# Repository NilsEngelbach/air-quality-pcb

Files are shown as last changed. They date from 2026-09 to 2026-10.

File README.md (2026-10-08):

# Air Quality Checker — PCB

Custom 2-layer KiCad boards for the [air-quality-checker](../air-quality-checker) firmware: a battery-powered
indoor air-quality monitor. A Bosch **BME688** measures the air, an **SG92R** micro servo points at the current IAQ
band, and readings can be uploaded over WiFi. A LiPo cell powers it and charges over USB-C. The device sleeps
~98 % of the time and wakes every 5 minutes.

The repo holds every board revision in its own folder. **The current board is [`v9/`](v9/) (rev I).**

---

## Current board — v9 (rev I)

| Block | Part | Notes |
|---|---|---|
| MCU | **ESP32-C3-WROOM-02-N4** | native USB Serial/JTAG (no USB-UART bridge), antenna in a board notch with no copper beside it |
| Sensor | **BME688** on-board, I²C 0x76 | on a slotted island at the board edge for thermal isolation |
| Indicator | **SG92R** servo header | from VSYS through a load switch (Q6): 0 µA in sleep, 4.5 V on USB / 3.0–4.2 V on battery |
| Charger | **MCP73831**, ~303 mA | charge status to the MCU (IO20) and a green side-view LED |
| Regulator | **AP2112K-3.3** | 600 mA LDO |
| Power path | DMG2305UX P-FETs + B5819W | USB priority, battery reverse-polarity protection, POWER switch drives a FET |
| Controls | POWER (SPDT) + **WiFi mode** (SP3T: OFF / SPARSE / CONTINUOUS) slide switches | right-angle, actuators through the enclosure wall |
| Indicators | blue STATUS + green CHG side-view LEDs | visible from the enclosure side |
| Expansion | **STEMMA QT / Qwiic** port | switched 3.3 V and bus isolation: 0 µA when off; e.g. for a real CO₂ sensor |
| Protection | 2 × USBLC6-2SC6 | USB data lines and the STEMMA QT port |
| Board | Ø 72 mm round, bottom flat for the controls, 2 layers, 1.6 mm FR4 | 0.3 mm minimum drill; assembled by PCBWay |

**State (2026-10-08):** layout done, ERC 0 / DRC 0 with schematic parity; schematic PDF and PCBWay BOM generated.
Gerbers, the ESP32-C3 firmware port and bench validation are still open.

| v9 document | For |
|---|---|
| [`v9/README.md`](v9/README.md) | changes vs v8, pin map, power architecture, firmware port, outputs, next steps |
| [`v9/user-documentation.md`](v9/user-documentation.md) | people using the device |
| [`v9/design_review.md`](v9/design_review.md) | findings F1–F34 with evidence and validation checklists |
| [`v9/layout_constraints.md`](v9/layout_constraints.md) | layout rules |
| [`v9/power_budget.md`](v9/power_budget.md) | sleep floor, wake budget, battery life per WiFi mode |

---

## Revisions

| Rev | Folder | Summary | Docs |
|---|---|---|---|
| A | [`v1/`](v1/) | 108 × 108 mm square. ESP-12F (ESP8266) + CP2102N, BME688 breakout over STEMMA QT, servo from VBAT | [README](v1/README.md) |
| B | [`v2/`](v2/) | Same circuit on a **Ø 72 mm round** board, mounting holes, wind logo | [README](v2/README.md) |
| C | [`v3/`](v3/) | **BME688 soldered on-board**, copper keep-out under the sensor | [README](v3/README.md) |
| D | [`v4/`](v4/) | GPIO2 status LED, battery sensing, USB ESD, battery reverse-polarity FET, spare-GPIO header, fiducials, **5 V servo boost** | [README](v4/README.md) |
| E | [`v5/`](v5/) | Production / assembly refresh (PCBWay BOM, replacement power switch); battery-life analysis | [power budget](v5/power_budget.md) |
| F | [`v6/`](v6/) | Gated servo boost, **3-position WiFi mode switch**, side-view status LED, MΩ battery divider | [README](v6/README.md), [user docs](v6/user-documentation.md), [power budget](v6/power_budget.md) |
| G | [`v7/`](v7/) | **ESP32-C3** (native USB, no CP2102N), FET-driven power switch, servo-rail load switch, long-actuator edge switches, STEMMA QT port, charge-status input, antenna notch and sensor island | [README](v7/README.md), [design review](v7/design_review.md) |
| H | [`v8/`](v8/) | **Servo boost removed** (servo from VSYS), Espressif WROOM-02 footprint so the board keeps the 0.3 mm minimum drill. Fabrication outputs were generated | [README](v8/README.md), [design review](v8/design_review.md) |
| I | [`v9/`](v9/) | Re-placed and re-routed v8: **GPIO remap**, LDO at the module, smaller sensor island, no copper beside the antenna, C24 on the STEMMA QT rail | [README](v9/README.md) and the documents above |

Each revision's README lists what changed against the one before. From v7 on, the design reviews number their
findings (F1, F2, …) and carry them forward, so a finding keeps its number across revisions.

---

## Repository layout

```
README.md                   this overview
build_pcbway_bom.py         KiCad BOM export → PCBWay BOM (python build_pcbway_bom.py v9)
a-sample-of-PCBWay-BOM.xlsx PCBWay's BOM template, the format the script produces
wind.svg                    wind logo used on the back silkscreen (v2+)
vN/
  air-quality-pcb-vN.kicad_pro / .kicad_sch / .kicad_pcb
  README.md, design_review.md, layout_constraints.md, power_budget.md, user-documentation.md   (as available)
  bom_kicad_raw.csv → bom_pcbway_vN.csv, schematic_vN.pdf                                       (as generated)
  Espressif.pretty/, SamacSys_Parts.pretty/, fp-lib-table, air-quality-pcb-vN.3dshapes/       (v7+: vendor footprints and STEP models)
```

Not in git (see `.gitignore`): `gerbers/`, `*.rpt` (ERC/DRC reports), KiCad backups and lock files. Regenerate
them with the `kicad-cli` commands in each revision's README (KiCad 10).

### PCBWay BOM

1. Export the schematic BOM ungrouped, with the fields `Reference,Value,Footprint,Manufacturer,MPN,Description`, to
   `vN/bom_kicad_raw.csv` (command in the revision README).
2. `python build_pcbway_bom.py vN` groups it into PCBWay's columns and writes `vN/bom_pcbway_vN.csv`.

---

## Firmware

The firmware lives in the sibling [`air-quality-checker`](../air-quality-checker) repo. It currently targets the
**ESP8266 boards (v1–v6)**. The ESP32-C3 boards (v7–v9) need a port: PlatformIO `espressif32`, ESP-IDF deep sleep,
the new pin map, BME688 at 0x76. The steps are in [`v7/README.md`](v7/README.md#firmware-port-air-quality-checker-repo),
with the servo rules from v8 and the **v9 pin map** in [`v9/README.md`](v9/README.md#firmware-port-air-quality-checker-repo).
The v7/v8 and v9 pin maps differ, so a v8 build must not be flashed onto a v9 board.

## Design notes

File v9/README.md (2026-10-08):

# Air Quality Checker — PCB v9 (rev I)

Ninth iteration, derived from the routed v8 board. Same circuit and outline. The board is **re-placed and
re-routed**, the **GPIO assignment is cleaned up** so that each signal leaves the module towards its destination,
the **sensor island is smaller** with a narrower neck, **no copper sits beside the antenna** any more, and the
STEMMA QT rail gets a **100 nF cap at the connector** (C24).

**State (2026-10-08): layout done; schematic PDF and BOMs generated, Gerbers not yet.** Schematic ERC **0 violations**.
Board DRC with schematic parity **0 violations, 0 unconnected** (also after a zone refill). Parity lists the
7 board-only footprints (H1–H4, FID1–3) and one new warning, D2's value (`CHG` on the board, `CHG-GREEN` in the
schematic; F34). The four silkscreen-at-edge items are excluded as in v8. Still to do: Gerbers, drill and
position files (see *Regenerate outputs*), the order, the firmware port and the bench validation.

| Document | For |
|---|---|
| [`user-documentation.md`](user-documentation.md) | people using the device: controls, WiFi modes, setup, LEDs, troubleshooting |
| [`design_review.md`](design_review.md) | findings F1–F26 (v7/v8) and **F27–F34 (new in v9)**, each with validation checklists |
| [`layout_constraints.md`](layout_constraints.md) | the layout rules the v9 board follows: antenna, servo rail, island, widths |
| [`power_budget.md`](power_budget.md) | sleep floor, wake budget, battery life by WiFi mode (estimates, bench checklist) |

For v7 → v8 (boost removed, Espressif footprint) see [`../v8/README.md`](../v8/README.md). For v6 → v7
(ESP32-C3, switches, STEMMA QT, …) see [`../v7/README.md`](../v7/README.md).

---

## What changed vs v8

| # | Change | Why (finding) |
|---|---|---|
| 1 | **GPIO remap:** SERVO_PWM IO5 → **IO0**, VBAT_SENSE IO0 → **IO3** (ADC1_CH3), MODE_A IO3 → **IO4**, MODE_B IO4 → **IO5** | the mode switch now uses the module's left pads (towards SW4), servo and VBAT sense its right pads (towards J3 and the divider); shorter routes, fewer vias. **Firmware pin map changes** (F27) |
| 2 | **C24 100 nF** on QT_3V3 at J5 / U8 | HF decoupling at the connector and the ESD clamp; 0 µA in sleep (F28) |
| 3 | **LDO U4 + C10–C12 moved** right below the module (53.1, 44.6) | short +3V3 to the module (+3V3 copper 156 → 104 mm) (F29) |
| 4 | **Power path and servo switch regrouped** at J3: D1, Q3, C20, Q6, Q7, R27, R28, C22, C19, C13 | SERVO_PWR 25 → 15.5 mm, F.Cu, no vias (F29) |
| 5 | **USB ESD U6 rotated**, pin pairs flipped (connector on 6/4, MCU on 1/3) | still flow-through; connector-side D± 19 → 7.5 mm (F29) |
| 6 | RESET/BOOT, EN RC, VBAT divider, charge-detect divider, strap pull-ups, STEMMA QT FETs re-placed | shorter, uncrossed routes (F29) |
| 7 | **Sensor island** ≈ 9.5 × 7 mm, **4 mm neck**, **4 mm slots** (v8: ≈ 11.5 × 13 mm, 7 mm neck, 1 mm slots); U5 further out, C14/C15 on the island | better thermal isolation of the BME688 (F13, F30) |
| 8 | **ANTENNA_KEEPOUT** widened to x 29.5–80 (both layers), pour keepouts x 27.5–83; new GND via fence at y = 27.5 | no copper on the board shoulders beside the antenna (F7, F31) |
| 9 | Re-routed and re-stitched: 641 vias (605 GND, stitching at 0.8 / 0.4 mm); a few accepted width exceptions | (F5, F32) |
| 10 | Title block / back silkscreen **rev I** | |

Everything else is unchanged from v8: schematic topology, parts (apart from C24), outline apart from the island,
U1 position and EPAD vias, connectors, switches, LEDs and mounting holes.

## Pin map (ESP32-C3-WROOM-02)

| GPIO | Net | Function |
|---|---|---|
| IO0 | **SERVO_PWM** | servo signal via R17 (v8: IO5) |
| IO1 | VBUS_SENSE | ADC1_CH1, 5 V → 1.59 V (USB present) |
| IO2 | QT_PWR_N | **STEMMA QT power, active low** (strap pin, R2 10 k pull-up → port off at reset and in sleep) |
| IO3 | **VBAT_SENSE** | ADC1_CH3, divider 1 M / 270 k (4.2 V → 0.89 V, use 2.5 dB attenuation) (v8: IO0) |
| IO4 | **MODE_A** | SW4 POS1 → LOW = WiFi **OFF** (v8: IO3) |
| IO5 | **MODE_B** | SW4 POS3 → LOW = **CONTINUOUS**; both HIGH = SPARSE (v8: IO4) |
| IO6 / IO7 | SDA / SCL | I²C: BME688 (**0x76**) + STEMMA QT port (through Q9/Q10) |
| IO8 | STATUS_LED_N | blue side LED D3, **active-low**; strap (10 k pull-up) |
| IO9 | BOOT | SW2, strap (10 k pull-up) |
| IO10 | SERVO_EN | HIGH = servo rail on (Q7 → Q6); R4 100 k pull-down keeps it off |
| IO18 / IO19 | USB D− / D+ | native USB Serial/JTAG |
| IO20 | CHG_DET | charger STAT via divider: LOW = charging (only valid with VBUS present), HIGH = done |
| IO21 | — | not connected (spare) |

## Power architecture

Unchanged from v8:

```
USB-C VBUS ─┬─► MCP73831 (303 mA) ─► VBAT_RAW ◄── Q4 (reverse-polarity) ◄── LiPo J4
            │        └─ STAT ─► D2 (green) / R31-R32 ─► IO20
            │                        │
            │                  Q5 (SW3 drives the gate)
            │                        ▼
            └─►|D1|──► VSYS ◄── Q3 (USB priority) ── VBAT ─► R20/R21 ─► IO3
                        │
                        ├─► AP2112K-3.3 ─► +3V3 (ESP32-C3, BME688, LED) ─► Q8 (IO2) ─► QT_3V3 (C23, C24) ─► J5
                        └─► Q6 (SERVO_EN via Q7) ─► SERVO_PWR (C19 22 µF + C13 100 µF) ─► J3
```

Servo supply: **≈ 4.5 V on USB**, **3.0–4.2 V on battery** (F25). Sleep floor estimate **≈ 66 µA**. Battery
life by WiFi mode is in [`power_budget.md`](power_budget.md) (estimates until measured).

## Firmware port (air-quality-checker repo)

The firmware in [`../../air-quality-checker`](../../air-quality-checker) still targets the ESP8266 (v6 board).
The port follows [`../v7/README.md`](../v7/README.md#firmware-port-air-quality-checker-repo) (PlatformIO
`espressif32` / `esp32-c3-devkitm-1`, BSEC2 1.10.2610, BME688 at 0x76, `esp_deep_sleep`, `RTC_DATA_ATTR`) and
the v8 servo rules, **with the v9 pin map**:

```cpp
#define SERVO_PWM_PIN   0   // v8: 5
#define VBUS_SENSE_PIN  1
#define QT_PWR_N_PIN    2   // LOW = STEMMA QT on
#define VBAT_SENSE_PIN  3   // v8: 0 — ADC1_CH3, ADC_2_5db, VBAT = mV / 0.2126
#define MODE_A_PIN      4   // v8: 3 — LOW = OFF
#define MODE_B_PIN      5   // v8: 4 — LOW = CONTINUOUS
#define SDA_PIN         6
#define SCL_PIN         7
#define LED_PIN         8   // active-low
#define BOOT_PIN        9
#define SERVO_EN_PIN   10
#define CHG_DET_PIN    20   // LOW = charging (only with VBUS present)
```

- **Do not flash a v7/v8 pin map onto v9:** it would drive PWM into the battery divider and read the mode switch
  as an ADC.
- **Servo (F25):** SERVO_EN HIGH ≥ 50 ms before a move, LOW after it and before sleep; no PWM while SERVO_EN is LOW;
  skip moves below VBAT ≈ 3.5 V; move with WiFi idle.
- **Mode switch (F33):** read IO4/IO5 with `INPUT_PULLUP` at each wake, then switch them back to `INPUT`. If you use
  GPIO wake (switch gesture, instant mode change), enable pull-up + wake **only on the pin whose contact is open**.
  A pull-up on a closed contact costs ~70 µA in sleep and doubles the floor.
- **Re-provisioning:** BOOT/RESET are inside the enclosure. Add a switch gesture on SW4 (e.g. OFF → CONTINUOUS →
  OFF → CONTINUOUS within 5 s) and keep RESET-then-BOOT as the service path; `user-documentation.md` marks both.
- **Low battery (F19):** VBAT < ~3.3 V → one LED blink, then indefinite deep sleep.

## Files

| File | Purpose |
|---|---|
| `air-quality-pcb-v9.kicad_pro/.kicad_sch/.kicad_pcb` | v9 project (ERC clean; board DRC clean with parity) |
| `Espressif.pretty/`, `SamacSys_Parts.pretty/`, `fp-lib-table` | vendor footprints: U1 (Espressif) and SW4 (OS103011MA7QP1, Mouser / SamacSys) |
| `air-quality-pcb-v9.3dshapes/` | STEP models for the vendor footprints and the side LEDs |
| `README.md` | this file |
| `user-documentation.md` | end-user guide |
| `design_review.md` | findings F1–F34 with evidence, sources and validation checklists |
| `layout_constraints.md` | layout rules |
| `power_budget.md` | power and battery-life estimates, bench checklist |
| `schematic_v9.pdf` | plotted schematic |
| `bom_kicad_raw.csv` → `bom_pcbway_v9.csv` | schematic BOM export → PCBWay BOM (38 lines, 72 placements; SW3, SW4, J3, J4 THT; C24 joins the CL21B104KBCNNNC line), built with `python build_pcbway_bom.py v9` |
| *to generate* `gerbers/` | Gerbers, drill, position file — see below (`*.rpt` and `gerbers/` are git-ignored) |

### Regenerate outputs (run in `v9/`)

```sh
kicad-cli sch erc -o erc_v9.rpt air-quality-pcb-v9.kicad_sch
kicad-cli pcb drc --schematic-parity --refill-zones -o drc_v9.rpt air-quality-pcb-v9.kicad_pcb
kicad-cli sch export pdf -o schematic_v9.pdf air-quality-pcb-v9.kicad_sch
kicad-cli pcb export gerbers -o gerbers/ --subtract-soldermask --check-zones \
  --layers "F.Cu,B.Cu,F.Paste,B.Paste,F.Silkscreen,B.Silkscreen,F.Mask,B.Mask,Edge.Cuts" air-quality-pcb-v9.kicad_pcb
kicad-cli pcb export drill -o gerbers/ --format excellon --generate-map --map-format pdf air-quality-pcb-v9.kicad_pcb
kicad-cli pcb export pos -o gerbers/air-quality-pcb-v9-pos.csv --format csv --units mm --side both air-quality-pcb-v9.kicad_pcb
kicad-cli sch export bom -o bom_kicad_raw.csv --fields "Reference,Value,Footprint,Manufacturer,MPN,Description" \
  --group-by "" air-quality-pcb-v9.kicad_sch
python ../build_pcbway_bom.py v9
```

Then zip the `*.g*` files and the `.drl` into `gerbers/air-quality-pcb-v9-gerbers.zip`. Expect 72 placements
(v8: 71, + C24) and a smallest hole of 0.30 mm.

## Next steps

1. Housekeeping (F34): resolve the D2 value warning, fix the title-block comment ("(v7)") and the two keepout
   names, then generate Gerbers, drill and position files (and re-export the PDF/BOM if the schematic changed).
2. Optional before ordering: 3D export → enclosure check (switch actuators ~3.2 mm, USB face, LEDs, sensor-island
   opening, ≥ 15 mm around the antenna) and a 1:1 paper print of the SW4 footprint against a real part (F11).
3. **Order at PCBWay:** Gerber zip, `bom_pcbway_v9.csv`, position file. Order note: SW3/SW4 are THT; parts overhang the
   bottom flat, and the sensor island hangs on a 4 mm neck — no breakaway tabs on those sides.
4. Firmware port with the v9 pin map (above), then the validation checklists in `design_review.md` (F27–F33 are new)
   and the bench measurements in `power_budget.md` §8.

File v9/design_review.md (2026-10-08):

# v9 Design Review — Findings and Validation Checklist

F1–F24 are the review of the v6 board (`v6/air-quality-pcb-v6.*`, state of 2026-09-30) and the
changes made for v7. F25–F26 cover v8 (boost removed, 0.3 mm minimum drill). v9 (rev I) is built from
the routed v8 board, so all of them carry over. **F27–F34** cover the v9 changes: a GPIO remap, C24 on the
STEMMA QT rail, a re-placed and re-routed board, a smaller sensor island, a copper-free zone beside the
antenna, and some open housekeeping. Where v9 changes an earlier finding, the section has a **v9** note
(the **v8** notes stay as history). Every finding lists the evidence, the source, what the design does about
it, and how to validate it. Tick the boxes as you validate. Coordinates are board mm (KiCad), centre (55, 55),
y grows downward.

**Status legend:** ✅ done in the schematic/netlist/board · 🟡 layout task, still open ·
⬜ open decision, not changed · 🔬 needs bench or firmware validation · ➖ obsolete

| # | Finding | Status |
|---|---|---|
| F1 | Power switch SW3 (0.3 A) carries the whole battery current | ✅ 🔬 |
| F2 | Servo rail is **not** off in deep sleep on v6 (boost passes VSYS through L1/D4) | ✅ 🔬 (v8: Q6 now feeds the servo directly) |
| F3 | v6 "DRC clean" is stale — the current v6 file has 8 violations | ✅ (v9: DRC 0 / 0, 2026-10-08) |
| F4 | GND pads of U3 (charger) and U7 (boost) have only one thermal spoke | ✅ (U7 gone in v8) |
| F5 | All tracks are 0.2 mm, no net classes | ✅ (v9 exceptions: F32) |
| F6 | Boost converter hot loop is ~20 mm long, with no input cap at U7 | ➖ boost removed |
| F7 | ESP-12F antenna sits mid-board with copper all around | ✅ 🔬 (v9: F31) |
| F8 | USB-UART bridge (CP2102N) is not needed with the ESP32-C3 | ✅ 🔬 |
| F9 | ESP32-C3 strapping / EN / USB requirements | ✅ 🔬 |
| F10 | v7 pin map (ADC1, deep-sleep wake pins) | ✅ 🔬 (v9 remap: F27) |
| F11 | Edge parts: overhang limits; switch actuators too short | ✅ 🟡 🔬 |
| F12 | MCP73831 runs in thermal regulation at 455 mA | ✅ (R14 3.3 k) 🟡 🔬 |
| F13 | BME688 needs thermal isolation from heat sources | ✅ 🔬 (v9: F30) |
| F14 | AP2112K quiescent current dominates the v7 sleep floor | ✅ decided: keep |
| F15 | WROOM-02 library footprint uses 0.2 mm EPAD via drills | ✅ v8: Espressif footprint (F26) |
| F16 | BSEC2 supports the ESP32-C3 | ✅ 🔬 |
| F17 | VBUS_SENSE moved from CP2102N to ESP ADC | ✅ 🔬 |
| F18 | Round outline vs. straight-fronted edge parts | ✅ (cuts done) 🔬 |
| F19 | No battery under-voltage cutoff on board | ✅ decided: protected cells; firmware cutoff 🔬 |
| F20 | v6 power budget understated the sleep current | ✅ 🔬 (v9: [`power_budget.md`](power_budget.md)) |
| F21 | STEMMA QT port for optional sensors | ✅ 🟡 🔬 |
| F22 | Charge status to the MCU | ✅ 🔬 |
| F23 | CHG LED D2 invisible inside the enclosure | ✅ 🟡 |
| F24 | BME688 occupies the common add-on address 0x77 | ✅ 🔬 |
| F25 | **v8:** boost removed — servo runs from VSYS (4.5 V USB / 3.0–4.2 V battery) | ✅ 🟡 🔬 |
| F26 | **v8:** board must keep the 0.3 mm minimum drill — EPAD vias for the WROOM-02 | ✅ 🔬 |
| F27 | **v9:** GPIO remap — SERVO_PWM → IO0, VBAT_SENSE → IO3, MODE_A → IO4, MODE_B → IO5 | ✅ 🔬 (firmware) |
| F28 | **v9:** C24 100 nF HF decoupling on QT_3V3 at J5 / U8 | ✅ 🔬 |
| F29 | **v9:** re-placement — LDO at the module, power path regrouped at the servo switch, USB ESD flipped | ✅ 🔬 |
| F30 | **v9:** smaller sensor island (≈ 9.5 × 7 mm, 4 mm neck, 4 mm slots), U5 decoupling on the island | ✅ 🔬 |
| F31 | **v9:** no copper beside the antenna — keepouts widened to the board shoulders, new via fence | ✅ 🔬 |
| F32 | **v9:** routing — track-width exceptions, 0.8 / 0.4 mm stitching, USB pair length | ✅ (accepted) 🔬 |
| F33 | **v9:** mode-switch pull-ups must not stay on in deep sleep (~70 µA per closed contact) | ⬜ firmware 🔬 |
| F34 | **v9:** housekeeping — D2 value parity warning, title-block comment, keepout names, Gerbers not generated yet | 🟡 |

---

## F1 — Power switch SW3 is overloaded

- **Evidence (v6):** SW3 = C&K PCM12SMTBR, rated **0.3 A @ 6 V** (v6 BOM). It switched
  VBAT_RAW → VBAT, i.e. *all* battery current: servo move ≈ 400 mA battery-side
  (`v6/power_budget.md` §8), ESP32-C3 WiFi TX peaks up to 350 mA (module datasheet,
  Table 6-4). Combined peaks ≈ 0.75 A > 2× the switch rating.
- **v7 action:** SW3 only drives the gate of a new P-FET **Q5 (DMG2305UX, 20 V / 4.2 A)**.
  Q5 source = VBAT_RAW, drain = VBAT. SW3 common (pin 2) → gate; POS1 (1–2) → GND = **ON**;
  POS2 (2–3) → source = **OFF**. **R26 10 MΩ** gate–source holds Q5 off during the
  break-before-make gap (costs 0.42 µA while ON). Q5's body diode points VBAT → VBAT_RAW,
  so with SW3 OFF the battery cannot feed the system; USB still powers it via D1 (same as v6).
  The switch now carries µA, so a 0.1 A switch (F11) is fine.
- **Validate:**
  - [ ] SW3 ON: device runs from battery; Q5 V_DS < 50 mV at 0.5 A load.
  - [ ] SW3 OFF, no USB: VBAT ≈ 0 V, battery current < 1 µA (only charger leakage).
  - [ ] SW3 OFF + USB: device runs from USB, battery charges, Q5 stays off.
  - [ ] Slide SW3 slowly between positions: no brownout or latch-up.

## F2 — The servo rail is never really off on v6

- **Evidence (v6 schematic):** MT3608 is a non-synchronous boost: VSYS → L1 → SW node → D4
  → SERVO_5V. Pulling EN low (v6 change #1) stops switching but **does not disconnect**:
  SERVO_5V sits at ≈ VSYS − V_F(D4) in deep sleep. The servo stays powered, and the
  feedback divider R22 + R23 (93 kΩ) draws ≈ 37 µA. The v6 budget line "MT3608 + SG92R
  idle < 1 µA (EN low = shutdown)" only counts the MT3608's own shutdown current.
- **v7 action:** load switch in front of the boost input:
  **Q6 DMG2305UX** (VSYS → BOOST_IN, which feeds U7 IN, L1 and C18), gate pulled up by **R27 100 k**;
  **Q7 2N7002** pulls the gate down through **R28 47.5 k** when BOOST_EN (IO10) is high
  (V_GS ≈ −2.5 V at 3.7 V). **C22 100 nF** gate-drain gives a slow turn-on:
  ≈ 47 µA / 100 nF ≈ 0.5 V/ms, so BOOST_IN ramps in ~8 ms and the inrush into the
  ~166 µF downstream (C18 + C19 + C21 + C13) is ~80 mA instead of amps.
  Off state: R4 keeps BOOST_EN low → Q7 off → Q6 off → zero rail current.
- **v8:** the boost is gone and Q6's drain is the servo rail itself (`SERVO_PWR`; the control net is
  now `SERVO_EN`, gate/pull-down nets `SERVO_GATE`/`SERVO_PD`). Downstream capacitance is C19 + C13 = 122 µF,
  so the soft-start inrush is ≈ 60 mA. The off state is unchanged: zero rail current. See F25.
- **Validate:**
  - [ ] **On a v6 board first:** measure the J3 pin-2 current and voltage in deep sleep (expect ≈ VSYS − 0.3 V and
        ≥ 37 µA plus the servo idle current). This confirms the finding and quantifies the v6 loss.
  - [ ] v9 deep sleep: SERVO_PWR = 0 V.
  - [ ] Scope VSYS, +3V3 and SERVO_PWR on a SERVO_EN rising edge: SERVO_PWR ramps in ~5–10 ms;
        +3V3 dips < 100 mV (no ESP brownout).
  - [ ] Servo moves normally with SERVO_EN high ≥ 50 ms before the move.

## F3 — v6 DRC report is stale

- **Evidence:** `v6/drc_v6_check.rpt` is dated 10:07; the board was saved at 14:17.
  A fresh `kicad-cli pcb drc` on v6 gives **8 violations**: 4× copper-to-edge
  (SW3 0.47 / 0.47 mm, SW4 0.44 / 0.42 mm vs the 0.5 mm rule), 2× silkscreen clipped (SW3),
  2× starved thermal (F4).
- **v7 action:** SW3/SW4 replaced (F11); thermal fix (F4).
- **v8:** `drc_v8.rpt` (with schematic parity): 0 errors, 0 unconnected; 2 warnings (U1 silkscreen
  clipped at the antenna notch, F26) and the 7 board-only footprints.
- **v9:** ERC 0 violations. DRC with schematic parity (2026-10-08, also after a zone refill): **0 violations,
  0 unconnected**. Parity reports the 7 board-only footprints and one new warning, D2's value (F34). The four
  `silk_edge_clearance` items at the notch and the bottom flat are excluded in the project file.
- **Validate:**
  - [ ] After placement and routing: `run_drc` = 0 violations, and the report timestamp is newer than the board file.

## F4 — Starved thermals on the charger and boost GND pads

- **Evidence:** v6 DRC `starved_thermal` on U7 pin 2 and U3 pin 2 (1 spoke instead of 2).
  These are the two parts whose GND pin is their main heat path.
- **v7 action:** pad zone connection set to **solid** for the GND pads of U1 (pin 9 + EPAD),
  U3, U4 and U7.
- **v8:** U7 is removed. The solid connection is set again on U1 pin 9 and on all nine EPAD pads of the new
  footprint (F26).
- **Validate:**
  - [ ] After the zone refill, no `starved_thermal` on these pads. (The 5 current hits on J1/U6 are fine-pitch USB
        GND pads that lost their feeding traces; they clear when routed.)

## F5 — All traces are 0.2 mm, and there are no net classes

- **Evidence (v6 board dump):** every segment is 0.2 mm, including VBUS (138 mm of track),
  VBAT (59 mm), VSYS (47 mm), BOOST_SW (20 mm), SERVO_5V (47 mm).
  0.2 mm × 35 µm Cu ≈ 2.5 mΩ/mm → 0.25 V per 10 cm at 1 A. Heating is not the issue
  (IPC-2221 ≈ 0.7 A for +10 °C); voltage drop and inductance are (brownout during
  servo + WiFi peaks at low battery).
- **Action (v7, updated for v8, unchanged in v9):** net classes in `air-quality-pcb-v9.kicad_pro` (Freerouting/`export_dsn` reads them):

  | Class | Width | Via | Nets |
  |---|---|---|---|
  | Power | 0.8 mm | 0.8/0.4 | BAT_IN, VBAT_RAW, VBAT, VSYS, SERVO_PWR |
  | Supply | 0.5 mm | 0.8/0.4 | VBUS, +3V3, GND |
  | USB | 0.25 mm (diff pair 0.25/0.2) | 0.6/0.3 | USB_D±, USB_D*_CON, USB_D*_MCU |

  v8: SERVO_PWR (was BOOST_IN + SERVO_5V) is in Power; BOOST_SW is gone.
- **v9:** the re-route has some short segments below the class width (KiCad DRC does not enforce class widths).
  They are listed and accepted in F32.
- **Validate:**
  - [ ] `export_dsn` contains the classes; routed power tracks are ≥ the class widths.
  - [ ] At a 1 A battery load: VBAT_RAW → VSYS drop < 100 mV (incl. Q4, Q5, Q3).

## F6 — Boost converter hot loop (obsolete in v8)

> **v8:** the boost converter is removed (F25), so this finding and its checks no longer apply. Kept for the record.

- **Evidence (v6 placement):** U7–L1 14.5 mm, U7–D4 13.6 mm, D4–C19 20.5 mm, D4–C13 25.4 mm;
  BOOST_SW was a 20 mm track at 0.2 mm. **No cap at U7 IN**: the nearest VSYS cap was C18,
  11.7 mm away (C8 next to U7 is on VBUS). R22 sat ~8 mm from FB.
  MT3608 datasheet p.6: 22 µF in/out close to the IC on a strong GND plane, main traces
  short and wide, SW node small, FB divider close.
- **v7 action:** C18 → **22 µF at U7 IN** (BOOST_IN); **C21 22 µF** second output cap
  (0805 X5R 16 V loses capacitance at 5 V); D4 SS34 (SMA, 5.2 × 2.6 mm) →
  **PMEG4030ER** (SOD-123W, 2.6 × 1.7 mm, 40 V / 3 A). C20 22 µF is VSYS bulk ahead of Q6.
  Layout recipe in `layout_constraints.md` §3.
- **Validate:**
  - [ ] Layout: loop U7.1 → D4 → C19/C21 → GND → U7.2 fits within ~8 × 8 mm on F.Cu.
  - [ ] Scope the SW node: clean edges, ringing < 2 V overshoot. SERVO_5V ripple < 100 mV p-p during a servo move.

## F7 — Antenna placement

- **Evidence (v6):** ESP-12F centred at (53, 52) on the Ø72 mm board. Its antenna region
  (y ≈ 40–47.5 mm) is ~21 mm from the nearest edge, with GND pour on both layers around
  the keepout. No tracks cross the antenna.
- **Source:** Espressif ESP32-C3 HW design guidelines: antenna **outside** the base board,
  or the feed point as close to the edge as possible; cut the board on both sides of and under the antenna;
  **≥ 15 mm clearance in all directions** inside the housing; dense GND vias near the antenna.
- **v7 action:** module → ESP32-C3-WROOM-02 (18 × 20 mm). Its footprint carries an all-layer
  keepout of 28 × 11 mm (5 mm beyond each side and the antenna end). The old mid-board
  keepout zone was removed. Placement in `layout_constraints.md` §2.
- **v8:** Espressif's footprint only carries an 18 × 6 mm keepout (the antenna area of the module itself).
  The 28 × 11 mm area of the stock footprint is kept as the board rule area **ANTENNA_KEEPOUT**
  (x 41–69, y 15.4–26.4, F.Cu + B.Cu: no tracks, vias, pads or pour) — see F26.
- **v9:** ANTENNA_KEEPOUT is widened to the board shoulders beside the notch (x 29.5–80), the pours are kept off a
  slightly larger band, and the via fence is rebuilt — see F31.
- **Validate:**
  - [ ] Layout: antenna end at (or past) the board edge; no copper, tracks or vias in the keepout.
  - [ ] Bench: RSSI of v6 vs v7 at the same spot / AP distance (expect v7 ≥ v6).
  - [ ] In the enclosure: battery, servo and screws ≥ 15 mm from the antenna.

## F8 — UART bridge removed

- **Evidence:** the ESP32-C3 has an integrated USB Serial/JTAG controller (GPIO18/19)
  that supports flashing, console and automatic download mode (Espressif schematic
  checklist).
- **v7 action:** removed U2 (CP2102N), C4, C5, Q1, Q2, R6, R7 and JP1 (the C3 wakes from its
  internal RTC timer, so no GPIO16→RST link is needed). Added **R24/R25 22 Ω** series
  resistors (place at U1). C6 (4.7 µF) stays as VBUS bulk. **No test pads** (decision: boards
  are ordered assembled); recovery is BOOT + RESET over USB with the enclosure open. IO20 is
  re-used for CHG_DET (F22); IO21 is unconnected.
- **Validate:**
  - [ ] Board enumerates as USB JTAG/serial debug unit (VID 303A); `esptool` flashes without pressing buttons.
  - [ ] Manual recovery: hold BOOT, tap RESET → download mode.
  - [ ] Known behaviour: the USB port disappears during deep sleep — firmware should not rely on the console.

## F9 — ESP32-C3 strapping, EN and USB

- **Source:** module datasheet Table 4-3: SPI boot = GPIO9 high; download = GPIO9 low +
  GPIO8 high; GPIO2 "recommended to pull up due to glitches". EN RC = 10 k + 1 µF.
  Supply ≥ 500 mA, 10 µF + 0.1 µF at the module.
- **v7 action:** R2 → IO2 10 k pull-up; R5 → IO8 10 k pull-up (the status LED also sits on IO8,
  active-low, so LED off = strap high); R3 → IO9 10 k pull-up + SW2 BOOT; R1/C1 = 10 k /
  **1 µF** (was 100 nF); SW1 RESET now on EN; C2/C3 = 10 µF + 100 nF. AP2112K = 600 mA.
- **Validate:**
  - [ ] Boots into the application in every SW4 position, with and without USB.
  - [ ] LED stays dark during reset (IO8 high).
  - [ ] BOOT/RESET are **internal only** (decision). WiFi re-provisioning therefore needs a firmware gesture on
        SW4 (see README, firmware port). BOOT + RESET remain the service path: BOOT held while RESET is
        released = download mode.

## F10 — v7 pin map

> **v9:** IO0, IO3, IO4 and IO5 are reassigned — see **F27**. The table below is the **v9** map; the
> reasoning per pin is unchanged.

| GPIO | Net | Why |
|---|---|---|
| IO0 | SERVO_PWM (v7/v8: VBAT_SENSE) | via R17 100 Ω; any GPIO can drive LEDC PWM |
| IO1 | VBUS_SENSE | ADC1_CH1 (F17) |
| IO2 | QT_PWR_N | strap (R2 pull-up) → STEMMA QT power, active low (F21) |
| IO3 | VBAT_SENSE (v7/v8: MODE_A) | ADC1_CH3 (ADC1 is calibrated; ADC2 is not usable reliably) |
| IO4 / IO5 | MODE_A / MODE_B (SW4) (v7/v8: IO3 / IO4) | internal pull-ups while awake; GPIO0–5 can wake from deep sleep (mind F33) |
| IO6 / IO7 | SDA / SCL | R18/R19 10 k pull-ups; BME688 0x76 + QT port |
| IO8 | STATUS_LED_N | strap, pull-up R5, LED active-low |
| IO9 | BOOT | strap, R3 + SW2 |
| IO10 | SERVO_EN (v7: BOOST_EN) | R4 100 k pull-down → Q7/Q6 servo-rail switch |
| IO18 / IO19 | USB D− / D+ | via R25 / R24 |
| IO20 | CHG_DET | charger status via R31/R32 (F22) |
| IO21 | — | unconnected, spare |

- **Validate:**
  - [ ] Firmware port (see README) reads all inputs and drives all outputs as listed (v9 map).
  - [ ] VBAT_SENSE (IO3) reads 4.20 V ± 30 mV at full charge (ADC1, 2.5 dB attenuation, divider 0.2126).

## F11 — Edge parts: overhang limits and actuator length

- **Rule:** what limits overhang is the **frontmost copper or hole**, not the body.
  PCBWay: copper ≥ 0.3 mm, holes ≥ 0.5 mm from the routed edge; project rule
  `min_copper_edge_clearance` = 0.5 mm.
- **Evidence (v6):** SW3/SW4 (PCM12/PCM13): front SMD tabs sit 0.23 mm in front of the body,
  so the actuator tips reached only **0.71 / 0.55 mm** past the edge — they cannot reach through
  a 1.5–2 mm enclosure wall. D3 lens 0.2 mm past the edge; J1 front 0.7 mm past (front shield
  pad 0.88 mm inside).
- **v7 action:** right-angle THT slide switches with a **4 mm actuator** (C&K OS series):
  - SW3 **OS102011MA1QN1** (SPDT, 0.1 A / 12 V, BBM). KiCad footprint `SW_Slide_SPDT_Angled_CK_OS102011MA1Q`.
  - SW4 **OS103011MA7QP1** (SP3T ON-ON-ON, 0.1 A / 12 V, Digi-Key CKN9561-ND, active).
    Vendor footprint `SamacSys_Parts:OS103011MA7QP1` (Mouser / SamacSys, v3.2, with STEP), matching the C&K OS
    datasheet p. I-42: posts Ø1.5 mm 12.2 mm apart; terminals Ø0.8 mm at 2.1 / 6.1 / 8.1 / 10.1 mm from the left post;
    body 12.6 × 4.3 mm, centred on the pin row (body front 2.15 mm ahead of it).
    **Common = pin 2** (POS1 1–2, POS2 2–3, POS3 2–4) — differs from the PCM13 (common = 3);
    the schematic is wired for this.
  - With the posts' pads ending 0.5 mm behind the body front, the **body front can sit flush with
    the board edge** and the actuator protrudes **4.0 mm** (travel 2 mm per step).
- **v8/v9 (accepted):** SW3/SW4 sit at y = 81 with their bodies ~0.8 mm behind the bottom flat, so the actuators
  protrude **~3.2 mm**, not 4.0 mm. v9 did not move them. Size the enclosure wall and slots for 3.2 mm.
- **Validate:**
  - [ ] **First article / paper print:** the vendor footprint matches a real part (0.8 mm terminal holes are tight;
        check the pins drop in).
  - [ ] Enclosure: actuator passes the wall with ≥ 1.5 mm to grip; slot length = 2 mm actuator + travel
        (SPDT ≈ 4 mm, SP3T ≈ 6 mm) + clearance.
  - [ ] SW4 positions decode OFF / SPARSE / CONTINUOUS in that physical order.
  - [ ] PCBWay order note: THT parts SW3/SW4 + parts overhanging the edge — no breakaway tabs on those sides.

## F12 — Charger thermal (MCP73831, SOT-23-5)

- **Evidence:** R14 = 2.2 k → I_REG = 1000 V / 2.2 k ≈ 455 mA. Dissipation (5.0 − 3.7) V × 0.455 A
  ≈ 0.6 W typical, ≈ 0.9 W at the start of fast charge (3.0 V), datasheet worst case
  (5.5 − 2.7) × 0.455 ≈ 1.3 W. θJA = 230 °C/W minimum copper, ~130 °C/W with large copper
  (datasheet Table "Temperature specifications", §6.1.1.3) → the part sits in thermal
  regulation, and it heats the board (which affects BME688 readings while charging).
- **v7 action (decided):** **R14 = 3.3 k → I_REG ≈ 303 mA.** Dissipation (5.0 − 3.7) × 0.303 ≈ 0.39 W typical,
  worst case (5.5 − 2.7) × 0.303 ≈ 0.85 W. A 2000 mAh cell needs ≈ 7–8 h to full (fine overnight).
  Layout: large pours on pins 2/3/4 with vias, solid GND (done, F4), far from U5.
- **Validate:**
  - [ ] Thermal camera / thermocouple while charging an empty cell: U3 case temperature, charge current vs time.
  - [ ] BME688 temperature offset while charging vs not charging.

## F13 — BME688 thermal isolation

- **Evidence:** heat sources on board: U3 (up to ~1 W), U4 (≈ 0.45 W during TX bursts on USB:
  (4.6 − 3.3) V × 0.35 A), ESP module, LEDs (v7 also had U7/L1 during moves; removed in v8).
- **v7 action (layout):** U5 on the opposite side of the board from U1/U3/U4, ideally on a
  peninsula with a milled slot on 2–3 sides; keep the existing SENSOR_KEEPOUT (no pour under U5).
- **v9:** the island is smaller and its neck narrower, U5 sits further out, and C14/C15 moved onto the island
  (F30). The LDO U4 moved next to the module, so it is now **33 mm** from U5 (v8: ~44 mm); still well beyond the
  ~15 mm guideline. U3 (charger, the largest heat source) is 56 mm away.
- **Validate:**
  - [ ] Compare BME688 temperature vs a reference thermometer in sleep cycle, while charging, and on CONTINUOUS WiFi.

## F14 — LDO quiescent current

- **Evidence:** v7 sleep floor (estimate): ESP32-C3 deep sleep 5 µA (datasheet typ) +
  **AP2112K 55 µA** + VBAT divider 3.3 µA + R26 0.4 µA + BME688 ~2 µA ≈ **66 µA**.
  The LDO is ~80 % of it.
- **v7 (decided): keep the AP2112K.** Possible later option: a ≥ 500 mA LDO with µA-level Iq (e.g. Richtek RT9080-33 class;
  check dropout at 350 mA and the 1 µF output cap requirements) → floor ≈ 13 µA. The gain is only
  ~1.3 mAh/day against ~34 mAh/day total (wake phases dominate).
- **Validate:**
  - [ ] Measure the v7 sleep floor first; decide on the LDO swap with real numbers.

## F15 — WROOM-02 EPAD via drill

- **Evidence:** KiCad's `RF_Module:ESP32-C3-WROOM-02` uses 12 × 0.2 mm drills in the EPAD;
  the board minimum (and PCBWay standard) is 0.3 mm → `drill_out_of_range`.
- **v7 action:** keep the stock `RF_Module:ESP32-C3-WROOM-02` footprint (0.2 mm drills, 0.6 mm pads,
  0.2 mm annular ring) and lower the board minimum (`min_through_hole_diameter`) to **0.2 mm**.
  PCBWay builds 0.2 mm drills, possibly at extra cost. (An earlier v7 draft used a project copy with 0.3 mm drills.)
- **v8 (decided):** the board stays at the **0.3 mm** minimum drill. The 0.2 mm EPAD drills are gone with
  Espressif's own footprint — details and checks in **F26**.

## F16 — BSEC2 on the ESP32-C3

- **Evidence:** Bosch-BSEC2-Library `library.properties` (v1.10.2610 — the version the
  firmware already pins) lists `esp32c3`, and `src/esp32c3/libalgobsec.a` exists
  (riscv32-esp-elf-gcc build of BSEC v2.6.1.0).
- **Validate:**
  - [ ] PlatformIO env `platform = espressif32`, `board = esp32-c3-devkitm-1`, `boschsensortec/bsec2@1.10.2610` links.
  - [ ] IAQ accuracy reaches 3 and the BSEC state survives deep sleep (RTC memory / LittleFS).

## F17 — VBUS sensing

- **v7 action:** the CP2102N's VBUS_SENSE divider is re-used for ESP ADC1 (IO1), values
  swapped: R12 47.5 k (top), R13 22.1 k (bottom) → 5.0 V → 1.59 V (5.5 V → 1.75 V), inside
  the 12 dB ADC range and below the 3.3 V pin limit. Only loads VBUS, so no battery drain.
- **Validate:**
  - [ ] IO1 reads ~1.6 V on USB, ~0 V on battery; firmware can detect "on USB" (e.g. skip deep sleep for debugging).

## F18 — Round outline vs straight-fronted edge parts

- **Evidence:** a 9–13 mm wide straight face on a Ø72 mm circle leaves its corners
  0.3–0.6 mm (sagitta) inside the edge. The WROOM-02 (18 mm) has a 1.1 mm sagitta. The enclosure wall is curved too.
- **v7 action (done):** Edge.Cuts now has a **bottom flat at y = 84** (x 33.67–76.33) for SW4/J1/SW3,
  an **antenna notch** x 41–69 down to y = 26.3, and the **sensor island** slots (see [`../v7/layout_plan.md`](../v7/layout_plan.md);
  v9 reshapes the island, F30).
  D3 and D2 sit on the arc beside the flat.
- **Validate:**
  - [ ] Enclosure fit check with a 3D export (`export_3d`) before ordering.

## F19 — Battery cutoff

- No on-board under-voltage cutoff. **Decision: only cells with built-in protection (PCM) are used**, so no protection circuit is added.
- **Firmware:** if VBAT_SENSE < ~3.3 V → indefinite deep sleep (LED blink once).
- [ ] Verify the threshold with a bench supply ramped down.

## F20 — Power budget correction

- v6 `power_budget.md` sleep floor (~80 µA) **omits the servo rail** (F2): ≥ 37 µA through
  R22/R23 plus the SG92R idle current with power and no PWM (not in its datasheet — measure;
  micro servos often draw several mA, which would dominate the daily budget).
- v7 estimate: ~66 µA (F14), servo rail 0.
- v8: unchanged (~66 µA); removing the boost only drops parts that were already switched off by Q6.
- v9: unchanged (~66 µA; C24 sits on the switched QT rail). The estimate-based budget is now in
  [`power_budget.md`](power_budget.md). F33 is a firmware trap that would roughly double it.
- [ ] Measure the v6 and v9 sleep currents with the same firmware mode and replace the estimates in `power_budget.md`.

## F21 — STEMMA QT port

- **Why:** BME688 eCO₂ is a VOC-based estimate; a STEMMA QT / Qwiic port allows add-ons such as a
  real CO₂ sensor (SCD41), SHT4x, light sensors, without a board respin.
- **v7 action:** J5 JST SH 4P (SM04B-SRSS-TB): 1 GND, 2 QT_3V3, 3 SDA, 4 SCL (+ MP to GND).
  - **Switched power:** Q8 DMG2305UX (+3V3 → QT_3V3), gate = IO2 (QT_PWR_N). R2's 10 k strap pull-up
    keeps the port **off at reset and in deep sleep** → 0 µA when not in use. C23 10 µF on QT_3V3
    (v9: plus C24 100 nF at the connector, F28).
  - **Bus isolation:** Q9/Q10 BSS138 (gate = QT_3V3, source = SDA/SCL, drain = port side) with
    R29/R30 10 k port-side pull-ups. When the port is off, the FETs block the board pull-ups from
    back-feeding the unpowered sensor through its I/O clamps (≈ 0.3 mA per line otherwise).
  - **ESD:** U8 USBLC6-2SC6 at the connector, wired flow-through (connector → U8 pin 6/4, bus → U8 pin 1/3;
    the pin pairs are the same line inside the part, as with U6 on the USB data lines).
- **Validate:**
  - [ ] IO2 HIGH/input: QT_3V3 = 0 V, no current into J5; sleep floor unchanged.
  - [ ] IO2 LOW: QT_3V3 ≈ 3.3 V; +3V3 dip on enable < 100 mV with an SCD41 attached.
  - [ ] I²C scan with the port on: 0x76 (BME688) + the add-on; with the port off: only 0x76, no bus errors.
  - [ ] 400 kHz I²C works through Q9/Q10 with a 20–50 cm cable.

## F22 — Charge status to the MCU

- **v7 action:** charger STAT (U3.1, push-pull to VBUS = 5 V) → **R31 10 k / R32 18 k** → IO20 (CHG_DET):
  5.0 V → 3.21 V, 5.5 V → 3.54 V (below the 3.6 V pin maximum). STAT low = charging, high = done,
  hi-Z without VBUS (reads low → firmware must qualify with VBUS_SENSE). D2 still lights while charging.
- **Validate:**
  - [ ] IO20 reads LOW while charging, HIGH when full, and stays ≤ 3.6 V at VBUS = 5.5 V.

## F23 — Visible charge LED

- **v7 action:** D2 (top-view 0805, invisible inside the enclosure) → **Kingbright KPA-3010SGC**, green
  side-view, same footprint as D3; R15 1 k from VBUS gives ≈ 2.8 mA (Vf ≈ 2.2 V). Placed on the
  board edge next to the bottom flat (mirror of D3).
- **Validate:**
  - [ ] Polarity on first article (pad 1 = cathode, as for D3); visible through the enclosure.

## F24 — BME688 I²C address

- **v7 action:** BME688 SDO (pin 5) moved from +3V3 to GND → address **0x76**; 0x77 stays free
  for common add-on breakouts (BME280/680/688, BMP3xx default to 0x77).
- **Validate:**
  - [ ] Firmware uses `BME68X_I2C_ADDR_LOW` (0x76); I²C scan shows the BME688 at 0x76.

## F25 — Servo supply without the boost (v8)

- **Decision:** remove the MT3608 boost (U7, L1, D4, C18, C21, R22, R23). The servo must work on USB **and** on
  battery, so it runs from **VSYS** through the existing load switch Q6 (F2). VBUS alone was rejected:
  it is 0 V on battery.
- **Evidence:**
  - SG92R (TowerPro): rated **4.8–6 V**; all figures are given at 4.8 V (2.5 kg·cm, 0.1 s/60°). TowerPro
    publishes no current figures; micro servos of this class typically draw ~5–10 mA idle,
    ~150–250 mA moving and ~0.6 A or more at start/stall (estimate — measure).
  - SERVO_PWR = VSYS − Q6 drop (DMG2305UX, ≈ 50–70 mΩ → ≈ 15 mV at 250 mA):
    **USB ≈ 4.5–4.6 V** (VBUS − B5819W at ~0.5 A; within a few % of the rating), **battery 3.0–4.2 V**
    (below the rating: lower torque and speed, roughly proportional to voltage).
  - On battery, a start/stall pulse of ~0.6 A through the cell's protection, Q4/Q5/Q3 and the cell's internal
    resistance pulls VSYS down by roughly 0.2–0.3 V. The AP2112K needs VIN ≳ 3.3 V + dropout (≈ 0.1–0.25 V at the
    ESP's load) to hold +3V3; the module runs down to 3.0 V. Below VBAT ≈ 3.5 V a servo start can dip +3V3.
    C20 22 µF (VSYS) and C13 100 µF + C19 22 µF (SERVO_PWR) buffer the edge.
  - USB budget: with 5.1 kΩ CC pull-downs a USB 2.0 port only guarantees 500 mA. Charger 303 mA + ESP32-C3
    (WiFi TX peaks ~350 mA) + servo can exceed it; phone chargers (≥ 1.5 A) are fine.
  - USB inrush is unchanged: the servo bulk caps sit behind Q6's soft start (C22), not on VBUS.
- **v8 action:** `SERVO_PWR` net = Q6.D, C22, C19 22 µF, C13 100 µF, J3.2 (Power class). C20 stays as VSYS bulk.
  IO10 renamed `SERVO_EN`. Firmware: enable ≥ 50 ms before a move; skip moves below VBAT ≈ 3.5 V;
  move with WiFi idle; no PWM while SERVO_EN is low.
- **Validate:**
  - [ ] On battery at 4.2 / 3.7 / 3.5 V (bench supply in place of the cell): the servo reaches every IAQ position
        and holds it; record move time and current (peak and average).
  - [ ] Scope +3V3 during a servo start at VBAT = 3.5 V: no ESP brownout reset; adjust the firmware cut-off threshold.
  - [ ] On USB from a laptop port while charging an empty cell: servo move with WiFi on and off — no USB
        disconnect or brownout.
  - [ ] Sleep floor unchanged (servo rail 0 V, F20).

## F26 — EPAD vias with the 0.3 mm minimum drill (v8)

- **Constraint:** the board keeps PCBWay's standard minimum drill **0.3 mm** (`min_through_hole_diameter` 0.3).
  Both stock KiCad footprints (`RF_Module:ESP32-C3-WROOM-02` and `…-02U`) have 12 × 0.2 mm drills in the EPAD (F15).
- **Options considered:** (1) Espressif's footprint + board vias — **chosen**; (2) a project copy of the stock
  footprint with 0.3 mm drills (breaks the "no custom footprints" rule; 0.55 mm via pitch leaves 0.25 mm between holes);
  (3) no EPAD vias (weaker RF ground); (4) another module — a full re-layout.
- **v8 action:**
  - U1 → **`Espressif:ESP32-C3-WROOM-02`** from [espressif/kicad-libraries](https://github.com/espressif/kicad-libraries)
    (`v8/Espressif.pretty`, STEP in `air-quality-pcb-v8.3dshapes/`; v9 carries its own copies). The EPAD is a 3 × 3 array of 0.7 mm pads
    (pitch 1.05–1.15 mm), **no drills**. Its origin is 0.1 mm off the stock one; U1 now sits at **(55, 33.4)** so
    all pads are at the same board positions as in v7 (the routing still lands on them).
  - **4 GND vias 0.6 / 0.3 mm** at the gap crossings of the EPAD pads: **(55.385 | 56.485, 33.15 | 34.25)**. The via ring
    just touches the four pad corners (0.27 mm from the via centre), so the vias connect directly; the hole stays
    0.12 mm clear of the pad openings. Vias are tented (board setting), which limits wicking. The GND pour (solid
    connection) also joins the nine pads.
  - Board rule area **ANTENNA_KEEPOUT** replaces the stock footprint's built-in 28 × 11 mm keepout (F7).
- **v9:** U1 and the four EPAD vias are unchanged (checked: same coordinates, 0.6 / 0.3 mm). The new stitching uses
  0.8 / 0.4 mm vias; the smallest drill is still 0.3 mm (EPAD and signal vias).
- **Validate:**
  - [ ] DFM at PCBWay: no drill below 0.3 mm, no surcharge.
  - [ ] Gerber/3D check: the Espressif STEP model sits on the footprint (offset −9 / −7 mm in the footprint);
        the EPAD paste openings are the nine 0.7 mm squares.
  - [ ] First article: X-ray or a cross-check of the EPAD solder joint (no large voids, no solder through the tented vias).
  - [ ] RF (F7 check) is no worse than the v7 expectation.
  - [ ] The U1 silkscreen is clipped at the antenna notch (2 DRC warnings) — cosmetic; accept or hide those lines.

## F27 — GPIO remap (v9)

- **Change (schematic):**

  | Net | v8 | v9 | Module pad (side) |
  |---|---|---|---|
  | SERVO_PWM | IO5 (pad 4, left) | **IO0** | pad 18, right |
  | VBAT_SENSE | IO0 (pad 18, right) | **IO3** | pad 15, right |
  | MODE_A (SW4 → OFF) | IO3 (pad 15, right) | **IO4** | pad 3, left |
  | MODE_B (SW4 → CONTINUOUS) | IO4 (pad 3, left) | **IO5** | pad 4, left |

- **Why:** each signal now leaves the module on the side that faces its destination. SW4 is bottom-left (x 39),
  so both mode lines use the left pads. J3 is on the right edge (x 86), so the servo signal uses a right pad. The
  VBAT divider sits right of centre. In v8, MODE_A and SERVO_PWM left on the far side and crossed the board.
  Result: SERVO_PWM 49.8 → **34.2 mm, all F.Cu** (v8: 2 vias); MODE_A/MODE_B 2 vias each (v8: 4 / 6).
- **Checks against the ESP32-C3 rules (F9, F10):**
  - **ADC:** VBAT_SENSE on IO3 = **ADC1_CH3**, still ADC1. Divider, C17 and attenuation are unchanged.
  - **Deep-sleep wake:** MODE_A/MODE_B on IO4/IO5 are still within GPIO0–5 (deep-sleep wake capable).
  - **IO0 at power-up:** IO0/IO1 are the XTAL_32K pins (no 32 kHz crystal is fitted) and are not straps.
    Any level or glitch on IO0 during reset is harmless: R4 holds SERVO_EN low, so the servo rail is unpowered
    until the firmware enables it.
  - IO4/IO5 are also the pad-JTAG pins (MTMS/MTDI). Pad JTAG is not used; debugging goes over USB-JTAG.
- **Trade-off:** VBAT_SENSE now runs **30 mm** (v8: 11.6 mm, 2 vias). The node has ~213 kΩ source impedance, but
  C17 100 nF sits at the ADC pad (67, 30.5), so the line is low-impedance at RF and only DC reaches the pin.
- **Firmware:** the pin map changes (see README, *Firmware port*). The v8 map **must not** be flashed onto v9:
  it would drive PWM into the VBAT divider and sample the mode switch as an ADC.
- **Validate:**
  - [ ] Firmware pin map: `SERVO_PWM = 0`, `VBAT_SENSE = 3`, `MODE_A = 4`, `MODE_B = 5`.
  - [ ] VBAT_SENSE: spread of 8 consecutive samples < 20 mV, with WiFi idle and during a WiFi TX burst.
  - [ ] Power-up and reset with the servo connected: the servo does not twitch.
  - [ ] SW4 decodes OFF / SPARSE / CONTINUOUS on IO4 / IO5 (with F11).

## F28 — C24 on the STEMMA QT rail (v9)

- **Change:** **C24 100 nF** (0805 X7R, CL21B104KBCNNNC) from QT_3V3 to GND at (35.5, 63), between C23 10 µF
  (42, 63) and U8 (35.5, 66.5).
- **Why:** QT_3V3 had only the 10 µF bulk C23, ~6.5 mm from the connector. U8's VBUS pin (pin 5, the clamp
  reference) and J5.2 now get a small HF cap within ~3.5 mm, for add-on sensors with fast current edges and for the
  ESD clamp path. It sits on the switched rail, so it costs nothing in sleep.
- **Validate:**
  - [ ] With an add-on attached and IO2 LOW: QT_3V3 ripple at J5 < 50 mV p-p during the add-on's measurement.
  - [ ] Enable inrush (C23 + C24 + the add-on's caps through Q8): +3V3 dip < 100 mV (F21 check).

## F29 — Re-placement and re-route (v9)

The v9 board is re-placed and re-routed; outline, connectors, switches, LEDs, U1 and the mounting holes stay where
they were. Main moves:

| Block | v9 placement | Effect |
|---|---|---|
| **LDO** U4 + C10 (VIN), C11/C12 (VOUT) | U4 (53.1, 44.6), right below the module; C11/C12 at (51.5 / 49.5, 48) | +3V3 copper 156 → **104 mm**; the module's 3V3 pin is fed over a short path. VSYS now carries the ESP current over ~32 mm at 0.8 mm (≈ 20 mΩ, ≈ 7 mV at 350 mA) |
| **Power path + servo switch** D1, Q3, C20, Q6, Q7, R27, R28, C22, R4, C19, C13, R17 | grouped right of centre, next to J3: D1 (73, 54.8), Q3 (73, 58.3), Q6 (75, 51), C13 (80.5, 54) | SERVO_PWR 25.4 → **15.5 mm**, F.Cu, no vias. C20 (VSYS bulk) sits at Q6/Q3 |
| **VBAT divider** R20/R21 | (68.5, 53.5) / (67.5, 51.5) at VBAT; C17 stays at the ADC pad | see F27 |
| **Charge detect** R31/R32 | together at the charger, (71.4, 66) / (68.5, 68) | CHG_DET (slow) runs to U1 pad 11 |
| **USB ESD** U6 | (54, 73.5), rotated; pin pairs flipped: connector on pins 6/4, MCU side on 1/3 | still flow-through (1↔6 and 3↔4 are the same line inside the USBLC6). USB_D*_CON 19 / 17.5 → **7.5 / 6.0 mm** |
| **RESET / BOOT** SW1/SW2, R1/C1, R3 | SW1 (42, 38.5), SW2 (48, 43), next to the module's EN / IO9 side | internal buttons, short EN RC |
| **Strap pull-ups** | R5 (IO8) at (31, 74.5) next to D3/R16; R2 (IO2) at (41.5, 53.6) next to Q8 | DC pull-ups: position is not critical. R5 now sits at the LED end of STATUS_LED_N |
| **STEMMA QT** Q9, Q10, R29, U8, C24 | between J5 and the main I²C bus | see F28 |

- **Validate:**
  - [ ] Scope +3V3 at U1 pad 1 during WiFi TX on battery at VBAT 3.5 V: dip < 100 mV.
  - [ ] Enumeration and flashing over USB are reliable with a 1 m and a 2 m cable (F32 USB pair).
  - [ ] LDO case temperature during CONTINUOUS uploads on USB (F13 check).

## F30 — Sensor island (v9)

- **Change (Edge.Cuts):** the island is now **≈ 9.5 × 7 mm** (x 19.2–28.9, y 51.5–58.5). It is joined to the board
  by a **4 mm wide neck** (y 53–57, x 29.1–31.5), with **4 mm wide slots** above and below. v8: ≈ 11.5 × 13 mm, a
  7 mm neck, 1 mm slots. U5 moved 3.3 mm further out to (21.7, 55.0), and its decoupling caps C14/C15 moved onto the
  island at (26, 54 / 56.25). C16 10 µF and the I²C pull-ups R18/R19 stay on the main board at x 35.5.
- **Why:** less copper and less FR4 cross-section between the warm board and the sensor (F13); the wider slots also
  let room air reach the sensor from both sides.
- **Notes:** SENSOR_KEEPOUT (x 19–31, y 48–62, no pour) still covers the island and the neck. Only +3V3, GND, SDA and
  SCL cross the neck. The +3V3 run on the island is 0.2 mm, which is fine at the BME688's few mA (heater peaks
  included); see F32. The narrow neck is the mechanical weak point: no breakaway tab on this side, and don't use the
  island as a handling point.
- **Validate:**
  - [ ] BME688 temperature vs a reference: offset in sleep cycle, while charging and in CONTINUOUS, compared with a
        v8 board if one is built (F13).
  - [ ] Island survives depanelling and assembly (visual check for cracks at the neck).
  - [ ] Enclosure opening lines up with the island.

## F31 — No copper beside the antenna (v9)

- **Change:**
  - **ANTENNA_KEEPOUT** (F.Cu + B.Cu, no tracks / vias / pads / pour) widened from x 41–69 to **x 29.5–80**
    (y 15.4–26.5). It now covers the board shoulders on both sides of the antenna notch, not just the notch.
  - Two pour-only keepouts, **x 27.5–83, y 15–26.5**, one per layer (named `ANETNNA_KEEPOUT_1` on F.Cu and
    `ANTENNAb_KEEPOUT_2` on B.Cu — typos, F34). The pours now end at y ≈ 26.5 on both sides.
  - The v8 F.Cu pour and stitching vias in the upper-left lobe, e.g. (40, 24) and (37, 25.5), are gone. The new
    **via fence** (0.8 / 0.4 mm, GND) runs along y = 27.5 from x 35.5 to 74.5, mostly at 2 mm pitch (v8: 15 vias at
    1 mm pitch, x 48–62, 0.6 / 0.3 mm). 2 mm is far below λ/20 (≈ 6 mm at 2.4 GHz).
- **Why:** Espressif's layout guide asks for the antenna outside the base board or at its edge, with **no copper beside
  or under it**. With a notch only as wide as the module, the copper on the shoulders sat within a few mm of the
  antenna's ends. Bare laminate there is the closest a round board gets to "antenna outside the board".
- **Not changed:** H3 / H4 are still ~14 mm from the antenna area. Use nylon screws there, or accept the detuning
  (see F7 housing check).
- **Validate:**
  - [ ] RSSI at a fixed spot and AP distance: v9 ≥ v8 (or v7 expectation), board in its enclosure.
  - [ ] Gerber check: no copper on either layer above y ≈ 26.5 between x 27.5 and 83.

## F32 — Routing details (v9)

- **Track widths below the class width** (DRC does not flag these; all checked and accepted):

  | Net (class) | Where | Width / length | Why it is fine |
  |---|---|---|---|
  | +3V3 (Supply 0.5) | sensor island, C16 → C14/C15 → U5 | 0.2 mm, ~22 mm | BME688 draws a few mA; the island neck is too narrow for wide copper |
  | VBAT_RAW (Power 0.8) | to C9, R26 and SW3.3 | 0.2 mm, ~14 mm | gate network (µA) and a cap stub; the battery current runs on the 0.8 mm path |
  | VBAT_RAW (Power 0.8) | U3 pins 3–5 | 0.65 mm, ~5 mm | limited by the SOT-23-5 pad pitch |
  | VSYS (Power 0.8) | at U4 pins 1 / 3 (VIN, EN) and C10 | 0.3 mm, ~5.5 mm | pad necks; ≈ 2 mV at 350 mA |
  | SERVO_PWR (Power 0.8) | Q6 drain → C22 | 0.5 mm, 2.9 mm | ≈ 3 mΩ; < 2 mV at a 0.6 A servo start |
  | VBUS (Supply 0.5) | between the J1 VBUS pin pairs | 0.4 mm, ~7 mm | limited by the USB-C pad pitch |

- **Stitching:** 641 vias, 605 of them GND; 556 are 0.8 / 0.4 mm (v8: mostly 0.6 / 0.3). 67 vias under the module.
  The smallest drill is still 0.3 mm (the four EPAD vias and the signal vias), so the 0.3 mm board rule (F26) holds.
- **USB pair:** U6 → R24/R25 is **47.3 / 48.4 mm** (Δ 1.1 mm), each line with 2 vias. This misses the `< 30 mm,
  ≤ 1 via` guideline in `layout_constraints.md` §2, as v8 did (46–49 mm). At USB full speed (12 Mb/s, ≥ 4 ns edges)
  this is not critical; the connector side is now short (F29).
- **Validate:**
  - [ ] USB: enumeration, `esptool` flash at the default baud and a long serial log, with a 2 m cable (F29).
  - [ ] At a 1 A battery load: VBAT_RAW → VSYS drop < 100 mV (F5 check).

## F33 — Mode-switch pull-ups in deep sleep (v9, firmware)

- **Evidence:** SW4 has no external pull-ups; MODE_A/MODE_B rely on the ESP32-C3's internal pull-ups (~45 kΩ
  typ.). In OFF or CONTINUOUS, one contact is closed to GND. If the firmware leaves that pin's pull-up enabled across
  deep sleep (for example, to wake on a switch change, v7 README), it draws **3.3 V / 45 kΩ ≈ 70 µA**. That is more
  than the whole ~66 µA sleep floor (F14, F20), so the sleep current about doubles in two of the three positions.
  The v6 firmware already avoids this: it samples the pins with pull-ups, then releases them to Hi-Z.
- **Rule for the port:**
  - No GPIO wake: read IO4/IO5 with pull-ups at each wake, then set them to plain input before sleep. A mode change
    takes effect at the next timer wake (≤ 5 min). This is the simplest option and costs 0 µA.
  - With GPIO wake (for a switch gesture or instant mode change): enable the pull-up and the low-level wake **only on
    the pin whose contact is open**. An open contact costs 0 µA. Example: in SPARSE both are open, so wake on either.
    In OFF (IO4 closed), wake only on IO5 → moving to CONTINUOUS wakes the chip; moving to SPARSE takes effect at the
    next timer wake.
- **Validate:**
  - [ ] Sleep current in all three SW4 positions is the same within ±5 µA.

## F34 — Housekeeping (v9)

- [ ] **D2 value parity warning:** the board footprint value is `CHG` (silkscreen label), the schematic value
      `CHG-GREEN`. The BOM comes from the schematic, so ordering is not affected. Either set the schematic value to
      `CHG` or update the PCB from the schematic and re-check the silkscreen text.
- [ ] **Title block** comment 1 still reads "ESP32-C3 + BME688 + SG92R (v7)"; rev is I.
- [ ] **Keepout names** `ANETNNA_KEEPOUT_1` / `ANTENNAb_KEEPOUT_2` → e.g. `ANTENNA_POUR_KEEPOUT_F` / `_B` (cosmetic).
- [x] **Schematic PDF and BOMs** generated (2026-10-08): `schematic_v9.pdf`, `bom_kicad_raw.csv`,
      `bom_pcbway_v9.csv` (38 lines, 72 placements; C24 merged into the CL21B104KBCNNNC line, otherwise identical to v8).
- [ ] **Gerbers, drill and position files** (commands in the README).
- [ ] 3D export → enclosure check (switch actuators ~3.2 mm, F11; USB face; LEDs; island opening; ≥ 15 mm
      around the antenna).

---

## Sources

- Espressif, [ESP32-C3 PCB layout guidelines](https://docs.espressif.com/projects/esp-hardware-design-guidelines/en/latest/esp32c3/pcb-layout-design.html) and [schematic checklist](https://docs.espressif.com/projects/esp-hardware-design-guidelines/en/latest/esp32c3/schematic-checklist.html)
- Espressif, [ESP32-C3 datasheet](https://www.espressif.com/sites/default/files/documentation/esp32-c3_datasheet_en.pdf) (pin functions: ADC1 channels, XTAL_32K on GPIO0/1, deep-sleep wake on GPIO0–5, internal pull-up value — F27, F33)
- Espressif, [ESP32-C3-MINI-1 datasheet](https://documentation.espressif.com/esp32-c3-mini-1_datasheet_en.pdf) (strapping, current consumption tables — same ESP32-C3 chip); [ESP32-C3-WROOM-02-N4 at Digi-Key](https://www.digikey.com/en/products/detail/espressif-systems/ESP32-C3-WROOM-02-N4/14553031)
- Espressif, [KiCad libraries](https://github.com/espressif/kicad-libraries) (WROOM-02 footprint and STEP, F26)
- Aerosemi, [MT3608 datasheet](https://www.olimex.com/Products/Breadboarding/BB-PWR-3608/resources/MT3608.pdf) (v7 boost, removed in v8)
- TowerPro SG92R specification (4.8–6 V, figures at 4.8 V); Diodes Inc. DMG2305UX and AP2112K datasheets (F25)
- Microchip, [MCP73831 datasheet](http://ww1.microchip.com/downloads/en/DeviceDoc/20001984g.pdf)
- C&K, OS series datasheet ([LCSC copy](https://wmsc.lcsc.com/wmsc/upload/file/pdf/v2/lcsc/1811061532_C-K-OS102011MA1QN1_C226259.pdf)); [OS103011MA7QP1 at Digi-Key](https://www.digikey.com/en/products/detail/c-k/OS103011MA7QP1/1981432); [OS102011MA1QN1 at LCSC](https://www.lcsc.com/product-detail/Slide-Switches_C-K-OS102011MA1QN1_C226259.html)
- Kingbright KPA-3010SGC ([Farnell](https://uk.farnell.com/kingbright/kpa-3010sgc/led-side-view-smd-green-12mcd/dp/8530335)); JST SH SM04B-SRSS-TB; onsemi BSS138
- Nexperia, [PMEG4030ER datasheet](https://assets.nexperia.com/documents/data-sheet/PMEG4030ER.pdf); Diodes Inc., [2N7002 datasheet](https://www.diodes.com/datasheet/download/2N7002.pdf)
- Bosch, [BSEC2 library](https://github.com/boschsensortec/Bosch-BSEC2-Library)
- PCBWay, [safety spacing](https://www.pcbway.com/blog/PCB_Manufacturing_Information/How_is_the_PCB_safety_spacing_designed_.html), [hole to edge](https://www.pcbway.com/helpcenter/Engineering_Questions/the_spacing_requirement_from_hole_to_the_edge_of_board.html)

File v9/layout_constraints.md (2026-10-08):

# v9 Layout Constraints

These are the rules for the v9 (rev I) board. The board is placed and routed; this file lists the rules it
follows, so a later change does not quietly break one. Each rule references a finding in
[`design_review.md`](design_review.md). Coordinates are board mm (KiCad), centre (55, 55), y grows downward.

**Changed vs v8:** GPIO remap (F27), C24 on QT_3V3 (F28), re-placement of the LDO, power path, servo switch,
USB ESD and buttons (F29), smaller sensor island (F30), no copper beside the antenna (F31), 0.8 / 0.4 mm
stitching (F32). Placement and routing history up to v8: [`../v7/layout_plan.md`](../v7/layout_plan.md),
[`../v8/layout_plan.md`](../v8/layout_plan.md).

---

## 1. Zoning

```
              ┌──── antenna notch (x 41–69) ────┐
     bare FR4 │  U1 ESP32-C3-WROOM-02 (55, 33.4) │ bare FR4      ← no copper above y ≈ 26.5 (F31)
              └──────────────────────────────────┘
   SW1/SW2, R1/C1 (left of U1)     U4 LDO + C10–C12 (below U1)      R20/R21, C17 (VBAT sense)
 ┌──────┐
 │ U5   │ sensor island          Q8, C23/C24, Q9/Q10, U8        D1, Q3, Q6/Q7, C20, C22, C19, C13 ─ J3 (right edge)
 └──────┘  (left edge)           (STEMMA QT block, J5)          U3 charger, R14, C9, R31/R32 ─ J4, Q4/Q5
              D3 ◜  SW4 (39)   ── J1 USB-C (56.5) ──   SW3 (66)  ◝ D2           ← bottom flat, y = 84
```

- Heat sources (U3, U4, U1) stay away from **U5**. In v9, U4 is 33 mm away, U1 40 mm and U3 56 mm (F13, F30).
- The **antenna end** of U1 points out of the board. Battery, servo, screws and USB cable stay
  ≥ 15 mm away from it in the housing.
- Signals leave the module on the side that faces their destination (F27): mode switch → left pads 3/4,
  servo PWM and VBAT sense → right pads 18/15.

## 2. ESP32-C3-WROOM-02 (U1) — F7, F9, F26, F31

| Rule | Value | Source |
|---|---|---|
| Footprint | `Espressif:ESP32-C3-WROOM-02` (vendor, `v9/Espressif.pretty`), origin (55, 33.4) | F26 |
| Antenna position | outside the board outline (best), or feed point at the edge; cut the board on both sides of and under the antenna | Espressif PCB layout guide |
| Keepout | board rule area **ANTENNA_KEEPOUT** x 29.5–80, y 15.4–26.5, F.Cu + B.Cu: no tracks / vias / pads / pour (footprints allowed). Plus pour-only keepouts x 27.5–83, y 15–26.5 on each layer. The footprint adds its own 18 × 6 mm keepout | F7, F31 |
| Housing | ≥ 15 mm free space around the antenna in all directions (battery!) | Espressif |
| GND | via fence along y = 27.5 (x 35.5–74.5, ~2 mm pitch, 0.8 / 0.4 mm); dense GND vias under the module (67 in v9) | Espressif, F31 |
| EPAD | 9 pads (0.7 mm, no drills), solid zone connection; **4 GND vias 0.6 / 0.3 mm in the gaps** at (55.385 \| 56.485, 33.15 \| 34.25), tented. Don't move them onto the pads (paste openings); keep other stitching off the EPAD | F26 |
| Drill | board minimum **0.3 mm** — no smaller vias anywhere | F26 |
| Decoupling | C2 10 µF + C3 100 nF at pad 1 (3V3), at (42 / 44, 29), vias straight to GND | Espressif |
| LDO | U4 directly below the module (53.1, 44.6); C10 at VIN, C11/C12 at VOUT — short +3V3 to pad 1 | F29 |
| EN | R1 10 k + C1 1 µF close to pad 2; SW1 RESET next to them | Espressif |
| USB | R24/R25 22 Ω **at the module** (IO19/IO18). D+/D− as a parallel pair, equal length, over solid GND, GND vias at transitions. Guideline < 30 mm and ≤ 1 via per line; v9 has 47–48 mm and 2 vias (accepted for full speed, F32) | Espressif |
| ADC input | C17 100 nF **at the ADC pad** (U1 pad 15 / IO3); the divider R20/R21 may sit at VBAT | F27 |
| Strap pull-ups | R2 (IO2), R5 (IO8), R3 (IO9): DC pull-ups, any position on their net (R5 sits at D3, R2 at Q8) | F9, F29 |

## 3. Servo rail — F2, F25, F29

No switching converter; the servo current is a slow motor load straight from VSYS.

1. **Q6** (75, 51), source on **VSYS** (0.8 mm), drain = **SERVO_PWR** (Power class) → C22 → C19 → C13 → J3.2.
   v9 route: 15.5 mm, F.Cu, no vias.
2. **C13 100 µF** (80.5, 54) right at J3 (motor bulk); **C19 22 µF** anywhere on SERVO_PWR.
3. Gate network **Q7 / R27 / R28 / C22** next to Q6, 0.2–0.3 mm. **C22** sits between SERVO_GATE and SERVO_PWR (soft start);
   keep it close to Q6.
4. **J3.3 (GND)** and C13's GND with ≥ 2 vias to the B.Cu plane: the servo's return current (up to ~0.6 A at start)
   should not flow through the module's ground area.
5. **SERVO_EN** (IO10 → R4, Q7 gate) and **SERVO_PWM** (IO0 → R17 at J3) are slow signals.
6. **C20 22 µF** stays as VSYS bulk at Q6 / Q3: it buffers the servo start on battery.

## 4. Charger, LDO, power path — F1, F4, F12

| Part | Rule |
|---|---|
| U3 MCP73831 (76.5, 68) | Large copper on pins 2 (GND, solid), 3 (VBAT) and 4 (VDD) with vias to B.Cu; J4 close to VBAT/VSS (datasheet §6.2); C7/C8 at VDD, C9 at VBAT. Up to ~1 W while fast charging. Pin necks at 0.65 mm are fine (F32) |
| U4 AP2112K (53.1, 44.6) | C10 at VIN, C11/C12 at VOUT; copper on GND/VIN for ≈ 0.45 W bursts. Fed by VSYS (0.8 mm, ~32 mm) |
| Q3 / D1 | at the servo switch (73, 54.8–58.3): VSYS is formed next to Q6 and C20 |
| Q4 / Q5 | on the battery path: short and wide (Power class). Q5 (81, 62) near J4; SW3 only carries the gate (PWR_GATE, R26), so its traces can be 0.2 mm |
| D1 | carries the servo current on USB too (B5819W, 1 A) |
| VBAT divider | R20/R21 at VBAT (68.5, 53.5), C17 at the ADC pad — see §2 |

## 5. Edge parts — how far they may overhang — F11, F18

The limit is the **frontmost copper or hole**: copper ≥ 0.5 mm (project rule; PCBWay min
0.3 mm), holes ≥ 0.5 mm from the routed edge. Bodies may overhang. Unchanged from v8.

| Part | Limiting feature | v9 placement | Result |
|---|---|---|---|
| **SW3** OS102011MA1QN1 | mounting-post pads end 0.5 mm behind the body front | (66, 81), body ~0.8 mm behind the flat | actuator **~3.2 mm** past the edge (accepted) |
| **SW4** OS103011MA7QP1 | same series and geometry | (39, 81) | actuator **~3.2 mm** past the edge |
| **J1** USB-C HRO TYPE-C-31-M-12 | front shield tab pads (1.85 mm behind the body front) | (56.5, 81.4) | receptacle face ≈ flush with the outer enclosure wall |
| **D3** KPA-3010 side LED (blue) | its pads, 0.8 mm behind the lens | (31.5, 81), on the arc left of the flat | lens up to ~0.3 mm past the edge; light pipe or thin window |
| **D2** KPA-3010SGC (green CHG) | same as D3 | (78.5, 81), mirror of D3 | same as D3 |
| **J5** STEMMA QT (JST SH, horizontal) | its SMD mounting tabs | (30, 67.5) | ≥ 15 mm from the antenna notch |
| **U1** antenna | keepout only | antenna end at or past the edge | see §2 |

- Enclosure slots for the switches: width ≥ 2.0 mm actuator + clearance; length ≈ actuator +
  travel (SPDT 2 mm → ~4 mm, SP3T 2 × 2 mm → ~6 mm) + clearance.
- On a Ø 72 mm circle, a straight face of width *w* has its corners
  36 − √(36² − (w/2)²) mm inside the edge: 9 mm → 0.28 mm, 12.6 mm → 0.56 mm, 18 mm → 1.14 mm.
- **PCBWay note:** parts overhang the bottom flat, and the sensor island hangs on a 4 mm neck — panelize with
  rails or tabs elsewhere, no breakaway tabs on those sides.

## 6. Track widths and vias — F5, F32

Net classes are in the project file (Freerouting reads them via `export_dsn`):

| Class | Width | Nets |
|---|---|---|
| Power | 0.8 mm | BAT_IN, VBAT_RAW, VBAT, VSYS, SERVO_PWR |
| Supply | 0.5 mm | VBUS, +3V3, GND |
| USB | 0.25 mm, diff pair 0.25 / 0.2 gap | USB_D±, USB_D*_CON, USB_D*_MCU |
| Default | 0.2 mm | signals (incl. SERVO_EN, SERVO_GATE, SERVO_PD) |

- Narrower segments are allowed only where the current is small or a pad forces a neck. The accepted
  list is in F32 (sensor-island +3V3, the VBAT_RAW gate/cap stubs, U3/U4/J1 pad necks, Q6 → C22).
  KiCad DRC does **not** check class widths, so re-check them by hand after any re-route.
- Vias: 0.6 / 0.3 and 0.8 / 0.4 mm only (minimum drill 0.3 mm). Stitching uses 0.8 / 0.4 mm.
- Prefer copper pours over long tracks for VBAT/VSYS where space allows.

## 7. Sensor island — F13, F30

- Island ≈ 9.5 × 7 mm (x 19.2–28.9, y 51.5–58.5), **4 mm neck** at y 53–57, **4 mm slots** above and below.
- U5 at (21.7, 55.0); C14/C15 on the island. C16 and R18/R19 stay on the main board.
- Keep the SENSOR_KEEPOUT (x 19–31, y 48–62, no pour on either layer). Only +3V3, GND, SDA and SCL cross the neck.
- Opening in the enclosure above the sensor; no heat source within ~15 mm.

## 8. STEMMA QT, charge detect and misc

- **J5** at (30, 67.5). **U8 (ESD) directly behind J5**, flow-through: J5.3/J5.4 → U8 pins 6/4,
  U8 pins 1/3 → Q9/Q10 drains. **Q9/Q10, R29/R30** between U8 and the main I²C bus. **Q8 + C23** feed QT_3V3;
  **C24 100 nF** between C23 and U8, close to U8 pin 5 / J5.2 (F28). IO2 (QT_PWR_N) is a slow signal.
- **USB ESD U6:** flow-through, connector on pins 6/4, MCU side on pins 1/3 (F29). Keep U6 between J1 and R24/R25.
- **R31/R32** (charge detect): together at the charger; CHG_DET is a slow signal to U1 pad 11.
- No test pads (decision: assembled boards; recovery = BOOT + RESET over USB with the enclosure open).
- BOOT/RESET (SW1/SW2) are internal: no enclosure access needed.
- **Re-routing:** a full re-route (delete all tracks and vias) also deletes the **4 EPAD vias** and the antenna
  via fence. Re-add the EPAD vias at the coordinates in §2, then stitch, then refill zones and run DRC with
  schematic parity.

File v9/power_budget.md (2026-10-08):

# Power Budget — v9 board

Update of [`v6/power_budget.md`](../v6/power_budget.md) for the ESP32-C3 boards (v7 → v9). The duty cycle is
the same as on v6: BSEC ULP with one sample per 300 s, a short wake and ~290 s of deep sleep, 288 wakes per day.
The WiFi mode switch (SW4) splits the budget by mode.

> **All numbers are estimates** (datasheet typicals and the firmware's duty cycle). Nothing here is measured on a
> v7–v9 board yet. The ESP32-C3 firmware port does not exist yet, so the wake time is the biggest unknown.
> Replace the estimates with bench numbers (§8) before sizing batteries for a real deployment.

---

## 1. What changed since v6

| | v6 (ESP8266) | v9 (ESP32-C3) | Effect |
|---|---|---|---|
| MCU deep sleep | ESP-12F ~20 µA | WROOM-02 **~5 µA** | −15 µA |
| Servo rail in sleep | boost "off" but VSYS still reached the servo via L1/D4 (F2): ≥ 37 µA + servo idle | **0** (Q6 load switch) | the v6 budget had missed this |
| Servo supply | 5 V boost, ~400 mA battery-side per move | **VSYS directly** (3.0–4.2 V on battery), no converter loss | less charge per move, but lower torque (F25) |
| Wake current | ESP8266 calibrates its RF at every boot: ~80 mA assumed | ESP32-C3 keeps the radio off unless WiFi starts: **~25–40 mA** assumed | the main gain in OFF/SPARSE |
| USB bridge | CP2102N (only on VBUS) | none (native USB) | no battery effect |
| Charge current | ~455 mA | **~303 mA** (R14 3.3 k, F12) | longer charge time (§6) |
| STEMMA QT port | — | switched by Q8: **0 µA** when off | optional add-on load (§5) |

## 2. Sleep floor (all modes)

| Contributor | Current | Note |
|---|---|---|
| ESP32-C3 deep sleep (RTC timer) | ~5 µA | module datasheet typical |
| AP2112K-3.3 quiescent | ~55 µA | ~80 % of the floor; LDO swap deferred (F14) |
| VBAT divider R20 + R21 (1 M + 270 k) | 3.3 µA | on VBAT, behind Q5 → 0 with POWER off |
| BME688 sleep + board leakage | ~2 µA | |
| R26 10 MΩ (Q5 gate, POWER on) | 0.4 µA | |
| MCP73831 reverse leakage into VBAT_RAW | < 1 µA | only without VBUS; flows even with POWER off |
| Servo rail (Q6 off), STEMMA QT (Q8 off), LEDs, SW4 contacts | 0 | SW4: only if the pull-ups are off in sleep — **F33** |
| **Total** | **≈ 66 µA** | **≈ 1.6 mAh/day** in every mode |

**Trap (F33):** if the firmware keeps the ESP's internal pull-up on a closed SW4 contact during sleep (OFF or
CONTINUOUS position), that adds ~70 µA and **doubles the floor**.

**POWER switch off (SW3):** only the battery side remains: the charger's reverse leakage (< 1 µA) and the cell's
self-discharge (~3 %/month).

## 3. Wake budget (per 300 s cycle)

| Phase | Assumption | Charge per event |
|---|---|---|
| Boot from deep sleep + BSEC state restore + one ULP sample + LED | ~25–40 mA for ~4–6 s (CPU at 160 MHz, radio off; BME688 heater pulses inside) | **~30–65 µAh**, typ. ~40 µAh |
| WiFi upload (associate + DHCP + TLS + HTTPS POST) | ~4–6 s at ~100–130 mA average (TX peaks ~350 mA) | **~110–220 µAh**, typ. ~150 µAh |
| Servo move (only when the IAQ band changes) | SERVO_EN 50 ms ahead, ~150–250 mA for ~1 s at 3.7 V | **~40–70 µAh** per move |

At 3.7 V the servo is slower than at 4.8 V, so a move takes longer, but no boost converter loss is paid.
A few moves per day cost < 0.5 mAh/day, which is negligible.

## 4. Daily totals by mode (typical, with the range)

| Mode (SW4) | What happens | Per day |
|---|---|---|
| **OFF** | 288 wakes, no WiFi | 288 × 40 µAh + floor ≈ **13 mAh** (10–21) |
| **SPARSE** | as OFF, plus one batch upload per hour (every 12th wake) | 13 + 24 × 150 µAh ≈ **17 mAh** (13–26) |
| **CONTINUOUS** | upload at every wake | 288 × (40 + 150) µAh + floor ≈ **56 mAh** (42–84) |

For comparison, the v6 estimates were 34 / 38 / 75–90 mAh/day. The difference is mostly the wake current (§1). It is
also the least certain number, so measure it first.

## 5. Battery life (usable = nameplate × 0.75)

The derating covers the cut-off at ~3.3–3.5 V, temperature and ageing. Typical values; the ranges from §4 give
roughly −40 % / +30 %. Runs longer than ~3 months also lose ~3 %/month to self-discharge.

| Mode | 1000 mAh | 2000 mAh | 3500 mAh (18650) |
|---|---|---|---|
| OFF | ~8 weeks | ~16 weeks | ~6 months |
| SPARSE | ~6 weeks | ~12 weeks | ~5 months |
| CONTINUOUS | ~2 weeks | ~4 weeks | ~6–7 weeks |

**Reading:** SPARSE costs ~30 % more than OFF. CONTINUOUS costs about 4× as much: use it for short campaigns
or with USB power.

### Optional add-on on the STEMMA QT port

An add-on only costs energy while IO2 powers the port. Example, **Sensirion SCD41** (real CO₂) in single-shot mode:
the measurement takes ~5 s, so the ESP stays awake ~5 s longer, and the sensor draws its measurement current
on top of that. Rough estimate: **+40–70 µAh per reading → +12–20 mAh/day** if it measures at every wake. That about
doubles OFF-mode consumption. Measuring CO₂ every 3rd wake (15 min) keeps it at +4–7 mAh/day. Check Sensirion's
notes on automatic self-calibration when the sensor is power-cycled between readings.

## 6. USB power and charging

| | Value |
|---|---|
| Charge current (CC phase) | ~303 mA (R14 = 3.3 kΩ) |
| Charge time, empty → full | ~4 h for 1000 mAh, **~7–8 h for 2000 mAh**, ~13 h for 3500 mAh |
| Port budget | a USB 2.0 port only guarantees 500 mA with the 5.1 kΩ CC pull-downs |
| Worst-case draw on USB | charger 303 mA + ESP32-C3 TX peaks ~350 mA + servo start ~0.6 A |

The device runs normally while charging. On a laptop port, charging plus a WiFi burst plus a servo start can exceed
500 mA for a moment. The firmware avoids this by moving the servo with WiFi idle (F25). Phone chargers (≥ 1.5 A)
are fine.

## 7. Firmware contract for these numbers

- **Sleep:** `esp_sleep_enable_timer_wakeup()` + `esp_deep_sleep_start()`. Before sleeping: SERVO_EN (IO10) LOW,
  STATUS LED off (IO8 HIGH/input), STEMMA QT off (IO2 HIGH/input), SW4 pins IO4/IO5 as plain inputs (F33).
- **Servo:** SERVO_EN HIGH ≥ 50 ms before a move, LOW after it; no PWM on IO0 while SERVO_EN is LOW; skip moves
  below VBAT ≈ 3.5 V; move with WiFi idle (F25).
- **Mode switch:** read IO4/IO5 with pull-ups at each wake, then release them. GPIO wake only on an open contact (F33).
- **BSEC:** stay on **ULP** (300 s). LP mode costs more and breaks calibration across deep sleep.
- **Low battery:** below ~3.3 V on VBAT_SENSE → indefinite deep sleep (F19).
- **Sparse cadence:** batch every 12 wakes (1 h), as on v6.

## 8. Bench verification checklist

1. **Sleep current**, POWER on, SW4 in each position, no USB: expect **~66 µA**, the same in all three
   positions (± 5 µA). A ~70 µA jump in OFF or CONTINUOUS means F33.
2. **POWER off:** battery current < 1 µA.
3. **Wake in OFF mode:** current profile and duration of one wake (scope over a shunt, or a power profiler).
   Update §3 and §4.
4. **One upload** (CONTINUOUS): charge per upload. Then **one hour of SPARSE** as a cross-check.
5. **Servo move** on battery at 4.2 / 3.7 / 3.5 V: peak and average current, move time (F25).
6. **Charge time** of the cell you deploy, and the charger temperature (F12).
7. Record the results here and replace the estimate tables.

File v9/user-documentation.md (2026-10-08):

# Air Quality Checker — User Documentation (v9 board)

A battery-powered indoor air-quality monitor. Every 5 minutes it wakes up, measures the air with a Bosch
BME688 sensor, turns a pointer (servo) to the current air-quality band, can upload the reading over WiFi, and
goes back to sleep. Depending on the WiFi mode and the battery, one charge lasts weeks to months.

> **Firmware status:** this guide describes the v9 board running the ESP32-C3 firmware. That firmware port is
> still to be done (see [`README.md`](README.md), *Firmware port*). The behaviour below follows the current
> firmware (v6 board) adapted to v9. Points marked **(planned)** depend on features that the port still has to add.

---

## 1. Controls and indicators

All controls sit on one edge of the device, the **control edge**:

```
   ●STATUS        [ WIFI MODE ]        ( USB-C )        [ POWER ]        CHG●
   blue LED        3-position          charge +          on / off       green LED
                   slide switch        data              slide switch
```

| Item | Name | What it does |
|---|---|---|
| **SW3** | POWER (slide) | Main switch. ON = the device runs from the battery. OFF = battery disconnected (storage, shipping). USB still charges and powers the device when OFF. |
| **SW4** | WIFI MODE (3-position slide) | OFF / SPARSE / CONTINUOUS — see §3. |
| **J1** | USB-C | Charging, and firmware updates / log output. |
| **D3** | STATUS (blue LED) | Device state — see §5. |
| **D2** | CHG (green LED) | On = battery charging. Off = full, or no USB. |

Inside the enclosure (only needed for service):

| Item | Name | What it does |
|---|---|---|
| **SW1** | RESET (button) | Restarts the device. |
| **SW2** | BOOT (button) | WiFi re-setup and firmware recovery — see §6. |
| **J4** | LiPo (JST PH 2-pin) | Battery connector. The plug is keyed. |
| **J3** | SERVO (3-pin) | Pointer servo. Pin labels on the board: **S** (signal) / **+** / **−**. |
| **J5** | STEMMA QT / Qwiic (4-pin JST SH) | Optional add-on sensor, e.g. a true CO₂ sensor. Powered only while it is used. |

---

## 2. Getting started

1. **Charge first.** Connect USB-C. The green CHG LED lights while charging and goes out when the battery is full
   (~7–8 h for a 2000 mAh cell; the charger is deliberately gentle to keep heat away from the sensor).
2. **Choose a WiFi mode** on WIFI MODE (§3). If unsure, start with **OFF**: the device works fully offline.
3. **Slide POWER on.** The blue STATUS LED blinks (sensor stabilising) and the pointer moves to its first position.
4. **Expect a learning period.** The gas sensor needs about **48 hours** of running time to reach full accuracy.
   Readings are usable much earlier, but treat the first two days as warm-up. The calibration is kept across sleep
   cycles, so this happens only once, or again after the battery was completely empty.

> Do the first WiFi setup (§4) on USB power. A setup session keeps the device fully awake for a few minutes.

---

## 3. WiFi modes (WIFI MODE switch)

The two end positions are **OFF** and **CONTINUOUS**; the middle position is **SPARSE**. Check the labels on your
enclosure for which end is which. The mode is read at every wake, so a change takes effect within 5 minutes.
No reflash is needed.

| Position | Mode | Behaviour | Typical battery life* (2000 mAh) |
|---|---|---|---|
| End | **OFF** | Never uses WiFi. Measurement and pointer only. | ~3–4 months |
| Middle | **SPARSE** | Stores readings on the device and uploads them as one batch **every hour**. | ~3 months |
| Other end | **CONTINUOUS** | Uploads every 5-minute reading. | ~4 weeks |

\* Estimates, not yet measured on this board. Details and other battery sizes:
[`power_budget.md`](power_budget.md). SPARSE costs little more than OFF. For long CONTINUOUS deployments, use USB power.

Each upload contains IAQ, accuracy, temperature, humidity, pressure, eCO₂, bVOC and battery voltage.

---

## 4. WiFi setup (provisioning)

WiFi credentials are **never built into the firmware**. You enter them once in a setup page on the device; they
are stored on the device and survive firmware updates (only a full flash erase removes them).

### First-time setup

1. Set WIFI MODE to **SPARSE** or **CONTINUOUS** and slide POWER on.
2. With no credentials stored, the device starts its setup portal: the STATUS LED blinks
   **long – short – short**, and a WiFi network named **`Birdy-Setup-<id>`** appears.
3. Join that network with your phone. The setup page opens by itself (otherwise browse to `192.168.4.1`).
4. Enter WiFi name and password, API URL, API key and Birdy ID, then tap **Save & Reboot**. The device restarts in
   the selected mode and starts uploading.
5. If nobody completes the setup within **~3 minutes**, the device goes back to sleep to save the battery. It offers
   the portal again at the next wake (every 5 minutes), until it is configured or you switch to OFF.

### Changing the WiFi later

- **(planned) Without opening the enclosure:** a switch gesture on WIFI MODE will force the setup portal, for example
  OFF → CONTINUOUS → OFF → CONTINUOUS within 5 seconds. The exact gesture is defined by the firmware port.
- **With the enclosure open (same sequence as on the v6 board):** press and release **RESET**, then press
  **BOOT** within about half a second. The STATUS LED shows long – short – short and `Birdy-Setup-<id>` appears again.

> Order matters: if BOOT is still **held while RESET is released**, the chip starts in firmware-download mode
> instead (§6). Nothing breaks: just press RESET again.

---

## 5. STATUS LED (blue)

| Pattern | Meaning |
|---|---|
| On for a few seconds, then off | Normal wake, sensor calibrated |
| Blinking ½ s on / ½ s off | Sensor still stabilising — normal during the first days |
| **Long – short – short**, repeating | **WiFi setup portal active** — join `Birdy-Setup-<id>` |
| Off | Asleep (normal: the device sleeps ~98 % of the time), or no power |
| **(planned)** One blink, then nothing for a long time | Battery empty: the device has switched itself off to protect the cell — charge it |

The green CHG LED is independent: on = charging, off = full or unplugged.

---

## 6. Buttons (inside the enclosure)

### RESET (SW1)
Restarts the device immediately. Use it after a WiFi mode change if you don't want to wait for the next wake, or as
the first step when troubleshooting.

### BOOT (SW2)
- **WiFi re-setup:** RESET, then BOOT within ~0.5 s (§4).
- **Firmware recovery:** hold BOOT, tap RESET, release BOOT. The chip then waits in download mode and shows up as a
  USB serial/JTAG device, ready for flashing. Normal firmware updates over USB-C don't need this. It is the recovery
  path if an update went wrong, or if the computer cannot see the device because it is asleep (§9).

---

## 7. Everyday behaviour

- The device is asleep most of the time (STATUS LED off). Every 5 minutes it wakes for a few seconds: the LED lights or
  blinks, the pointer moves *if* the air-quality band changed, then it sleeps again.
- **The pointer only moves when the band changes.** Hours without movement are normal and save battery.
- The pointer sweeps 0°–180° across seven bands:

| IAQ | Band | Pointer |
|---|---|---|
| 0–50 | Excellent | far left (0°) |
| 51–100 | Good | 30° |
| 101–150 | Lightly polluted | 60° |
| 151–200 | Moderately polluted | 90° |
| 201–250 | Heavily polluted | 120° |
| 251–350 | Severely polluted | 150° |
| > 350 | Extremely polluted | far right (180°) |

- **On battery the pointer moves more slowly** than on USB. The servo runs directly from the battery (3.0–4.2 V)
  instead of a 5 V supply. This is expected.
- **(planned)** When the battery is low (below ~3.5 V), the pointer stops moving to protect the electronics.
  Readings and uploads continue. Charge the device.
- **eCO₂ is an estimate derived from the VOC reading, not a real CO₂ measurement.** For real CO₂, add a CO₂ sensor
  on the STEMMA QT port (§8). Treat all readings as trends; the sensor is designed for indoor air.

---

## 8. Power, battery, charging

- **Charging:** any USB-C charger or computer port. Charge current is ~300 mA; a 2000 mAh cell takes ~7–8 h. The
  device keeps working while it charges.
- **On a laptop port** the device can briefly draw close to the port's 500 mA limit (charging + WiFi + pointer). A
  phone charger (≥ 1.5 A) avoids that.
- **Battery:** single-cell LiPo / Li-ion, 3.7 V, **with built-in protection circuit**, JST PH 2-pin plug (keyed).
  Rough sizes: 1000–2000 mAh for OFF/SPARSE; 18650 cells (3300–3500 mAh) for long deployments; see
  [`power_budget.md`](power_budget.md).
- **POWER off** disconnects the battery from the electronics. Use it for storage and shipping. The cell then only
  self-discharges (~3 % per month).
- **Battery monitoring:** the device measures its battery voltage at every wake and uploads it (WiFi modes).
- **STEMMA QT add-on:** plug in while the device is off. Add-ons cost battery only while they measure, but a CO₂
  sensor measuring every 5 minutes roughly doubles the consumption in OFF mode.
- **Placement:** keep metal (battery, screws, cables) and your hand away from the WiFi antenna end of the board.
  Don't block the sensor opening in the enclosure.
- LiPo safety: don't charge unattended on flammable surfaces; don't use damaged or swollen cells; charge at 0–45 °C.

---

## 9. Troubleshooting

| Symptom | Likely cause / fix |
|---|---|
| No LEDs, nothing happens | POWER off? Battery empty or unplugged? Connect USB-C (green LED should light) and press RESET. |
| STATUS blinks long – short – short | WiFi setup portal is active — join `Birdy-Setup-<id>` (§4). If unwanted, switch WIFI MODE to OFF. |
| No uploads, LED looks normal | WIFI MODE on OFF? Wrong credentials → re-setup (§4). Router out of range? In SPARSE, uploads happen only once per hour. |
| Pointer never moves | Normal while the air-quality band stays the same. |
| Pointer moves slowly or stops part-way | Battery low — charge. On USB it should move normally. |
| Pointer stopped updating, readings still upload | **(planned)** low-battery servo cut-off — charge. |
| Readings stay "stabilising" for days | The sensor needs ~48 h of running time. If it never improves, the stored calibration may be damaged; a firmware reset clears it. |
| Green CHG LED never lights on USB | Battery already full, battery unplugged, or the USB source provides no power. |
| Computer doesn't find the device for a firmware update | It is asleep (the USB port only exists while it is awake). Use the recovery sequence: hold BOOT, tap RESET, release BOOT (§6). |
| Device restarts when the pointer moves | Battery very low, or a weak USB port while charging — charge, or use a stronger charger. |

---

## 10. Quick reference

| | |
|---|---|
| Wake cycle | every ~5 min (~290 s sleep + a few seconds awake) |
| Sleep current | ~66 µA, whole device (estimate) |
| Battery | 3.7 V LiPo / Li-ion with protection, JST PH 2-pin |
| Charging | USB-C, ~300 mA, green LED = charging |
| WiFi modes | OFF / SPARSE (hourly batch) / CONTINUOUS (every reading) |
| Setup portal | `Birdy-Setup-<id>`, ~3 min timeout, `192.168.4.1` |
| Sensor | BME688: temperature, humidity, pressure, VOC gas → IAQ, eCO₂, bVOC |
| Full accuracy | after ~48 h of running time (one-time) |
| Add-on port | STEMMA QT / Qwiic, 3.3 V, switched off between readings |
| Firmware update | over USB-C (native USB); recovery: hold BOOT, tap RESET, release BOOT |

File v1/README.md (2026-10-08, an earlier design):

# Air Quality Checker — PCB v1 (square)

First iteration of the board for the [air-quality-checker](../../air-quality-checker) firmware: an
ESP8266 air-quality monitor that reads a Bosch BME688 over I2C and moves an SG92R micro servo to indicate
the current IAQ level. Battery-powered with LiPo charging over USB-C.

This board replaces the Adafruit Feather HUZZAH with an on-board design, so the whole system fits on one
PCB. v2–v4 refer to this file for the electrical description; for the current board see
[`../v9/README.md`](../v9/README.md).

---

## What's on the board

| Block | Part | Notes |
|---|---|---|
| MCU | **ESP-12F** (ESP8266, 4 MB) | Castellated module, antenna keep-out respected |
| USB–serial | **CP2102N** QFN28 | USB-C → UART, with DTR/RTS auto-reset |
| Charger | **MCP73831** | Single-cell LiPo, 2.2 kΩ PROG ≈ 500 mA |
| Regulator | **AP2112K-3.3** | 3.3 V LDO @ 600 mA |
| Power path | **DMG2305UX** PFET + **B5819W** Schottky | USB powers the rail and charges the cell |
| Sensor | **STEMMA QT (JST-SH 4P)** | BME688 breakout over I2C (SDA GPIO4 / SCL GPIO5) |
| Actuator | **3-pin servo header** | SG92R, powered from VBAT through a 100 Ω signal resistor |
| User I/O | RESET + BOOT buttons, deep-sleep jumper, PWR and CHG LEDs | |
| Battery | **JST-PH 2P** | LiPo cell |

Board size: **108 × 108 mm**, 2 copper layers, 1.6 mm FR4.

---

## Schematic ↔ firmware pin map

| Net | ESP-12F pin | Function |
|---|---|---|
| `SDA` | GPIO4 | BME688 I2C data |
| `SCL` | GPIO5 | BME688 I2C clock |
| `SERVO_PWM` | GPIO13 | Servo PWM (through R17 100 Ω) |
| `GPIO16` | GPIO16 | Deep-sleep wake → RST via JP1 |
| `RST` | RST | Reset; pulled up by R2, driven by Q1 (DTR) |
| `GPIO0` | GPIO0 | Boot strap; pulled up by R3, driven by Q2 (RTS) |
| `UART_TX` | GPIO1/TXD | to CP2102N RXD |
| `UART_RX` | GPIO3/RXD | to CP2102N TXD |
| `GPIO2` | GPIO2 | On-board status LED (firmware `LED_PIN`) |
| `GPIO15` | GPIO15 | Pulled low (boot strap) |

`GPIO16 → RST` is required for `ESP.deepSleep()` to wake up (ESP8266 Errata 2.9).
The jumper **JP1** ships **bridged**; cut it only if you need GPIO16 for something else.

---

## Power architecture

```
USB-C (VBUS) ─┬─► MCP73831 ─► VBAT_RAW (LiPo JST-PH)
              │                 │
              │            SW3 (power switch)
              │                 │
              │                 ▼
              └─►|B5819W├──► VSYS ◄── Q3 (DMG2305UX, USB priority)
                            │
                            ├─► AP2112K-3.3 ─► +3V3 (ESP + BME688)
                            └─► Servo header V+   (C13 100 µF bulk)
```

When USB is present, Q3 turns off and the Schottky feeds VSYS, so the cell is not
loaded during charging. On battery, Q3 conducts and the cell drives VSYS.

> **Note:** the servo runs from **VBAT/VSYS** (~3.7–4.2 V), not the 3.3 V rail, per
> the SG92R's 4.8–6 V rating. Torque is slightly reduced at 3.7 V; add a boost
> converter if that matters.

---

## Fabrication

Recommended stack-up for JLCPCB/OSHPark: 2 layers, 1.6 mm, HASL, 0.2 mm min trace.
Gerbers are not kept in the repo; regenerate them (run in `v1/`):

```sh
kicad-cli pcb export gerbers --output gerbers/ \
  --layers "F.Cu,B.Cu,F.Paste,B.Paste,F.Silkscreen,B.Silkscreen,F.Mask,B.Mask,Edge.Cuts" \
  air-quality-pcb.kicad_pcb
kicad-cli pcb export drill --output gerbers/ air-quality-pcb.kicad_pcb
kicad-cli sch export bom --output bom.csv air-quality-pcb.kicad_sch
kicad-cli pcb drc --output drc.rpt air-quality-pcb.kicad_pcb
kicad-cli sch erc --output erc.rpt air-quality-pcb.kicad_sch
```

---

## Verification status (at release)

| Check | Result |
|---|---|
| ERC (schematic) | **0 errors, 0 warnings** |
| DRC (board) | **0 violations, 0 unconnected** |
| Nets | 32, all routed; GND is a filled pour on both layers |
| Autorouter | Freerouting 2.4.1 (Specctra DSN/SES) |

---

## Design notes / caveats

- **Antenna keep-out:** U1's antenna region (top of the module) is kept clear of
  copper by the ESP-12E footprint. Do not route or pour under it.
- **USB-C CC resistors** R10/R11 (5.1 kΩ) are required for a USB-C source to
  provide VBUS.
- **CP2102N auto-program:** Q1/Q2 form the standard cross-coupled DTR/RTS reset
  and boot circuit used by the Feather; `pio run --target upload` works without
  touching the buttons.
- **BME688 pull-ups** live on the Adafruit breakout (10 kΩ) — none are fitted here.
- **Charging current** is set by R14 = 2.2 kΩ (≈ 500 mA: I = 1000 / R).

---

## Firmware

The firmware lives in the sibling [`air-quality-checker`](../../air-quality-checker)
repo and runs as-is on this board: same ESP8266, same I2C pins, same servo pin (`GPIO13`),
same LED pin (`GPIO2`).

---

## Files

| File | Purpose |
|---|---|
| `air-quality-pcb.kicad_pro` | Project |
| `air-quality-pcb.kicad_sch` | Schematic (ERC clean) |
| `air-quality-pcb.kicad_pcb` | Board (DRC clean, fully routed) |
| `schematic.pdf` | Plotted schematic |
| `bom.csv` | Bill of materials |

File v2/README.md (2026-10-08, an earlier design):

# Air Quality Checker — PCB v2 (round)

Second iteration of the [air-quality-checker](../air-quality-checker) board: the
same ESP8266 + BME688 + SG92R design as [v1](../v1/), but on a **compact round
PCB** with mounting holes and a wind logo.

> The circuit is identical to v1 — only the mechanical form factor, placement
> density and silkscreen changed. See the [v1 README](../v1/README.md) for the
> full electrical description and the schematic↔firmware pin map.

---

## What changed vs. v1

| | v1 | v2 |
|---|---|---|
| Shape | 108 × 108 mm square | **Ø 72 mm circle** |
| Board area | 11 664 mm² | **4 072 mm² (−65 %)** |
| Mounting | none | **4 × M2.5 holes** on the diagonal |
| Logo | none | **wind mark** + wordmark on the back silk |
| Placement | grid | polar, courtyard-legalized |

Everything on the electrical side is unchanged: ESP-12F, CP2102N, MCP73831,
AP2112K, DMG2305UX/B5819W power path, STEMMA QT, servo header, LiPo JST-PH,
RESET/BOOT buttons, deep-sleep jumper, PWR/CHG LEDs.

---

## Mechanical

- **Diameter:** 72 mm (outline Ø 72.05 mm on Edge.Cuts).
- **Mounting holes:** 4 × M2.5 (2.7 mm drill) on the 45°/135°/225°/315°
  diagonals, positioned to clear every component courtyard.
- **Connectors on the rim** for cable access:
  - USB-C (J1) — bottom
  - STEMMA QT (J2) — top
  - servo 3-pin header (J3) — right
  - LiPo JST-PH (J4) — left
- **Logo:** `wind.svg` (3 filled paths) converted to filled silkscreen polygons
  on the **bottom** silkscreen, together with `AIR QUALITY CHECKER` / `REV B`.

### Regenerating the logo

`wind.svg` lives in the repo root. The generator parses its paths
(lines + elliptical arcs) and emits `gr_poly` fills on `B.SilkS`:

```
python svg_to_poly.py wind.svg          # sanity-check the path bounds
```

---

## Verification status

| Check | Result |
|---|---|
| ERC (schematic) | **0 errors, 0 warnings** |
| DRC (board) | **0 violations, 0 unconnected** |
| Nets | 32, all routed; GND pour on both layers |
| Schematic ↔ PCB netlist | exact match (32 nets) |
| Autorouter | Freerouting 2.4.1 (Specctra DSN/SES) |

---

## Fabrication

Gerbers and drill files are in `gerbers/`. Recommended stack-up for
JLCPCB/OSHPark: 2 layers, 1.6 mm, HASL, 0.2 mm min trace.

### Regenerate outputs

```sh
kicad-cli pcb export gerbers --output gerbers/ \
  --layers "F.Cu,B.Cu,F.Paste,B.Paste,F.Silkscreen,B.Silkscreen,F.Mask,B.Mask,Edge.Cuts" \
  air-quality-pcb-v2.kicad_pcb
kicad-cli pcb export drill --output gerbers/ air-quality-pcb-v2.kicad_pcb
kicad-cli sch export bom --output bom_v2.csv air-quality-pcb-v2.kicad_sch
kicad-cli sch export pdf --output schematic_v2.pdf air-quality-pcb-v2.kicad_sch
kicad-cli pcb drc --output drc_v2.rpt air-quality-pcb-v2.kicad_pcb
kicad-cli sch erc --output erc_v2.rpt air-quality-pcb-v2.kicad_sch
```

---

## Design notes

- **Antenna keep-out:** U1's antenna region points up and stays clear of copper;
  no traces or pour run under it.
- **GND:** a single filled pour on both layers with solid (full) pad connections;
  the circular outline is approximated by a 96-point polygon inset 0.5 mm.
- **Routing:** all signal traces are ≥ 0.2 mm; the servo and power nets use wider
  traces. Freerouting's 150 µm segments were widened to 0.2 mm and re-verified.
- **Placement** was legalized against the *real* KiCad courtyards (including
  offset courtyards on connectors) so DRC is clean.

---

## Files

| File | Purpose |
|---|---|
| `air-quality-pcb-v2.kicad_pro` | Project |
| `air-quality-pcb-v2.kicad_sch` | Schematic (ERC clean) |
| `air-quality-pcb-v2.kicad_pcb` | Board (DRC clean, fully routed) |
| `schematic_v2.pdf` | Plotted schematic |
| `render_v2_top.png` / `render_v2_bottom.png` | 3D renders |
| `bom_v2.csv` | Bill of materials |
| `gerbers/` | Gerbers + drill (fabrication) |

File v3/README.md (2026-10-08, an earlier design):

# Air Quality Checker — PCB v3 (round, on-board BME688)

Third iteration: the same round board as [v2](../v2/), but the Bosch **BME688 is
soldered directly on the PCB** instead of hanging off a STEMMA QT breakout.

> The power/USB/MCU section is identical to v2; only the sensor front-end
> changed. See the [v1 README](../v1/README.md) for the full electrical
> description and the schematic↔firmware pin map.

---

## What changed vs. v2

| | v2 | v3 |
|---|---|---|
| Sensor | BME688 **breakout** on a STEMMA QT cable | **BME688 soldered on-board** (`U5`, LGA-8 3×3 mm) |
| Connector | J2 JST-SH 4-pin (STEMMA QT) | **removed** |
| Sensor support | on the breakout | **C14/C15/C16** decoupling + **R18/R19** I²C pull-ups on-board |
| Thermal | — | **copper keep-out** under the sensor on both layers |
| Shape / holes / logo | Ø 72 mm, 4 × M2.5, wind logo | unchanged |
| Rev | B | **C** |

Everything else is unchanged: ESP-12F, CP2102N, MCP73831, AP2112K,
DMG2305UX/B5819W power path, servo header, LiPo JST-PH, RESET/BOOT buttons,
deep-sleep jumper, PWR/CHG LEDs.

---

## The on-board BME688

| | |
|---|---|
| Ref | `U5` — `Sensor:BME680` symbol, value **BME688** |
| Footprint | `Package_LGA:Bosch_LGA-8_3x3mm_P0.8mm_ClockwisePinNumbering` |
| Interface | I²C, **address 0x77** |
| Decoupling | `C14` 100 nF (VDD), `C15` 100 nF (VDDIO), `C16` 10 µF bulk |
| Pull-ups | `R18`/`R19` 10 kΩ on SDA/SCL to +3V3 (the breakout used to provide these) |

Wiring (I²C mode):

| Pin | Name | Net | Note |
|---|---|---|---|
| 1, 7 | GND | `GND` | |
| 2 | CSB | `+3V3` | high ⇒ I²C mode |
| 3 | SDI | `SDA` | |
| 4 | SCK | `SCL` | |
| 5 | SDO | `+3V3` | high ⇒ address **0x77** (firmware `BME68X_I2C_ADDR_HIGH`) |
| 6 | VDDIO | `+3V3` | |
| 8 | VDD | `+3V3` | |

> The sensor sits near the top edge with a **4.4 mm copper keep-out** on both
> layers so the ground pour does not thermally load the gas sensor. Give the
> enclosure a vent above it.

> **ERC note:** the stock KiCad `Sensor:BME680` symbol types SDO as
> `bidirectional` (to cover SPI too). Since SDO is only the I²C address-select
> input here, the generated schematic retypes that one pin to `input`; this
> removes a spurious `pin_to_pin` warning against the LDO's power output.

---

## Mechanical

- **Diameter:** 72 mm (outline Ø 72.05 mm on Edge.Cuts).
- **Mounting holes:** 4 × M2.5 (2.7 mm drill) on the 45°/135°/225°/315° diagonals.
- **Connectors on the rim:**
  - USB-C (J1) — bottom
  - servo 3-pin header (J3) — right
  - LiPo JST-PH (J4) — left
- **Logo:** `wind.svg` converted to filled silkscreen polygons on the **bottom**
  silkscreen, with `AIR QUALITY CHECKER` / `REV C 2026`.

---

## Verification status

| Check | Result |
|---|---|
| ERC (schematic) | **0 errors, 0 warnings** |
| DRC (board) | **0 violations, 0 unconnected** |
| Nets | 32, all routed; GND pour on both layers |
| Schematic ↔ PCB netlist | exact match (32 nets, 52 footprints) |
| Sensor keep-out | no copper under `U5` on F.Cu/B.Cu (verified) |
| Autorouter | Freerouting 2.4.1 (Specctra DSN/SES) |

---

## Fabrication

Gerbers and drill files are in `gerbers/`. Recommended stack-up for
JLCPCB/OSHPark: 2 layers, 1.6 mm, HASL, 0.2 mm min trace.

### Regenerate outputs

```sh
kicad-cli pcb export gerbers --output gerbers/ \
  --layers "F.Cu,B.Cu,F.Paste,B.Paste,F.Silkscreen,B.Silkscreen,F.Mask,B.Mask,Edge.Cuts" \
  air-quality-pcb-v3.kicad_pcb
kicad-cli pcb export drill --output gerbers/ air-quality-pcb-v3.kicad_pcb
kicad-cli sch export bom --output bom_v3.csv air-quality-pcb-v3.kicad_sch
kicad-cli sch export pdf --output schematic_v3.pdf air-quality-pcb-v3.kicad_sch
kicad-cli pcb drc --output drc_v3.rpt air-quality-pcb-v3.kicad_pcb
kicad-cli sch erc --output erc_v3.rpt air-quality-pcb-v3.kicad_sch
```

---

## Design notes

- **Antenna keep-out:** U1's antenna region stays clear of copper.
- **GND:** a single filled pour on both layers with solid pad connections; the
  circular outline is approximated by a 96-point polygon inset 0.5 mm, and the
  sensor keep-out is cut from it.
- **Routing:** all signal traces ≥ 0.2 mm; the servo and power nets use wider
  traces. Freerouting's 150 µm segments were widened to 0.2 mm and re-verified.
- **Placement** was legalized against the *real* KiCad courtyards (including
  offset courtyards on connectors) so DRC is clean. The five small parts packed
  around the sensor have their silkscreen references hidden to keep the dense
  cluster DRC-clean.

---

## Files

| File | Purpose |
|---|---|
| `air-quality-pcb-v3.kicad_pro` | Project |
| `air-quality-pcb-v3.kicad_sch` | Schematic (ERC clean) |
| `air-quality-pcb-v3.kicad_pcb` | Board (DRC clean, fully routed) |
| `schematic_v3.pdf` | Plotted schematic |
| `render_v3_top.png` / `render_v3_bottom.png` | 3D renders |
| `bom_v3.csv` | Bill of materials |
| `gerbers/` | Gerbers + drill (fabrication) |

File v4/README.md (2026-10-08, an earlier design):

# Air Quality Checker — PCB v4 (round, on-board BME688 + refinements)

Fourth iteration: the [v3](../v3/) round board with a batch of functional and
manufacturing improvements — a proper activity LED, battery monitoring, USB ESD
protection, battery reverse-polarity protection, a spare-GPIO header, fiducials,
and a 5 V boost for the servo.

> The core (ESP-12F, CP2102N, MCP73831, AP2112K, power path, on-board BME688)
> is unchanged from v3. See the [v1 README](../v1/README.md) for the full
> electrical description and the schematic↔firmware pin map.

---

## What changed vs. v3

| | v3 | v4 |
|---|---|---|
| Power LED | `D3` **always-on** PWR-RED (~1.3 mA, even in deep sleep) | `D3` is now a **GPIO2 status LED** (active-LOW, dark in deep sleep) |
| Battery monitoring | — | **`VBAT_SENSE`** divider into the ESP **ADC/TOUT** (R20/R21/C17) |
| USB protection | none | **`U6` USBLC6-2SC6** ESD array in-line on D+/D− |
| Battery protection | none | **`Q4` P-FET** reverse-polarity protection at the LiPo input |
| Expansion | — | **`J5`** 1×4 header: GPIO12 / GPIO14 / +3V3 / GND |
| Assembly | — | **3 fiducials** (FID1–3) |
| Servo rail | VSYS (~3.7–4.7 V) | **`U7` MT3608 5 V boost** → `SERVO_5V` |
| USB-C port | faced **along** the board edge (cable blocked by the board) | **rotated to face the board edge** — cable plugs in |
| Part choices | some footprints had no 3D model | swapped to **modeled equivalents** (see below) |
| Rev | C | **D** |

Everything else is unchanged: round Ø 72 mm, 4 × M2.5 holes, wind logo,
RESET/BOOT buttons, deep-sleep jumper, CHG LED, servo header, LiPo JST-PH.

---

## New blocks

### Status LED (replaces the power LED)
`D3` (STATUS) is wired `+3V3 → R16 1 kΩ → D3 → GPIO2`, i.e. **active-LOW** to
match the firmware (`LED_PIN = 2`). When the firmware drives GPIO2 low the LED
lights; in deep sleep the ESP only weakly holds the pin (~2 µA), so the LED goes
dark. This removes the ~1.3 mA that the old always-on PWR-LED drew 24/7.

### Battery voltage sense
`VBAT → R20 100 kΩ → VBAT_SENSE → R21 27 kΩ → GND`, with `C17` 100 nF filtering,
into **U1 pin 2 (ADC/TOUT)**. 4.2 V → ~0.89 V, inside the ESP8266 ADC's 0–1.0 V
range. Firmware can read it to estimate charge.

### USB ESD protection
`U6` (USBLC6-2SC6) sits in-line between the USB-C connector and the CP2102N:
the connector side is `USB_DP_CON`/`USB_DM_CON`, the chip side is `USB_D+`/`USB_D-`.
`VBUS` and `GND` are the clamp rails.

### Battery reverse-polarity protection
`Q4` (DMG2305UX P-FET): **drain → `BAT_IN` (J4)**, **source → `VBAT_RAW`**,
**gate → GND**. A correctly-wired cell turns the FET on; a reversed cell keeps it
off and its body diode blocks. (The JST-PH connector is keyed, so this is
belt-and-suspenders. Note the charger, which lives on `VBAT_RAW`, is not isolated
from a reversed cell while USB is plugged in.)

### Spare-GPIO breakout
`J5` 1×4: **1 = GPIO12, 2 = GPIO14, 3 = +3V3, 4 = GND** — the two usable free
ESP8266 GPIOs, for a future second sensor.

### Servo 5 V boost
`U7` (MT3608) steps `VSYS` up to `SERVO_5V` ≈ **5.07 V**
(`Vout = 0.6 V × (1 + R22/R23) = 0.6 × (1 + 82 k/11 k)`), so the SG92R sees its
rated 4.8–6 V. `L1` = 10 µH, `D4` = SS34 Schottky, `C18` = 10 µF in,
`C19` = 22 µF out, `EN` tied to `VSYS`. `C13` (100 µF) stays as the servo bulk cap.

### Fiducials
Three `Fiducial_1mm_Mask2mm` marks on the outer ring for pick-and-place alignment.
They are placed **after** routing (at track-free spots) so they can't interfere
with the autorouter or end up sitting on a trace.
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

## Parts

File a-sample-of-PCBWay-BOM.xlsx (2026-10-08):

 |  |  | xxxx xxxx xxxxx xxPCS BOM (Sample Bill of Materials)
Item # | *Designator | *Qty | Manufacturer | *Mfg Part # | Description / Value | *Package/Footprint | Type | Your Instructions / Notes
1 | U1 | 1 | Linear | LTC3780EG#PBF | IC BUCK-BOOST CONV 24-SSOP | 24-SSOP | SMD
2 | U2,U4 | 2 | Fairchild | LM2904M | IC OPAMP DUAL -40-85 C 8-SOIC | 8-SOIC | DNS
3 | U3 | 1 | ON | LM317MBDTG | LM317M IC REG VOLT ADJ 500MA DPAK | DPAK | SMD
4 | U5 | 1 | Microchip | PIC16F690-I/SS | IC PIC MCU FLASH 4KX14 20SSOP | 20SSOP | SMD
5 | Q1 | 1 | Diodes Inc | GBJ10005-F | RECT BRIDGE GPP 50V 10A GBJ | GBJ | SMD
6 | R14,R18 | 2 | Panasonic | ERJ-6ENF4701V | RES 4.70K OHM 1/8W 1% 0805 SMD | 0805 | SMD
7 | R15 | 1 | Susumu | RL3720WT-R022-F | RES .022 OHM 1W 1% 0815 SMD | 0815 | SMD
8 | R16, R31 | 2 | Panasonic | ERJ-6ENF4702V | RES 47.0K OHM 1/8W 1% 0805 SMD | 0805 | SMD
9 | C5 | 1 | Murata | GRM21BR71C225KA12L | CAP CER 2.2UF 16V X7R 0805 | 0805 | SMD
10 | C7 | 1 | Murata | GRM21BR71C475KA73L | CAP CER 4.7UF 16V X7R 0805 | 0805 | DNS
11 | C8,C22 | 2 | Muruta | GRM21BR71C105KA01L | CAP CER 1.0UF 16V 10% X7R 0805 | 0805 | SMD
12 | CN6 | 1 | Molex | 538-53398-0671 | 1.25mm Connectors VERTICAL HDR SMT 6P | SMT 6P | SMD
13 | L1,L2 | 2 | Coiltronics | DR127-150-R | INDUCTOR SHIELD PWR 15UH SMD | SMD | SMD
14 | L3 | 1 | TDK | ACM1211-102-2PL-TL | CHOKE COMM MODE 1000 OHM 6A SM | SMD | SMD
15 | CN3,CN4 | 2 | Molex | 53047-0510 | CONN HEADER 5POS 1.25MM VERT TIN | 5POS | thru-hole
Need a quick and accurante quote? Need an efficient production? Please read SMT Ordering Necessary Files & Info in 1 minute. Thank you very much! (https://www.pcbway.com/smt_ordering_guide.html)
Click for Instructions on How to Create a BOM (https://www.pcbway.com/blog/PCB_Assembly/How_to_Build_a_BOM__Bill_Of_Materials_.html)

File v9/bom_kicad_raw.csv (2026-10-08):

Reference | Value | Footprint | Manufacturer | MPN | Description
C1 | 1uF | Capacitor_SMD:C_0805_2012Metric | Samsung Electro-Mechanics | CL21B105KOFNNWE | CAP CER 1UF 16V X7R 0805
C2 | 10uF | Capacitor_SMD:C_0805_2012Metric | YAGEO | CC0805KRX5R7BB106 | CAP CER 10UF 16V X5R 0805
C3 | 100nF | Capacitor_SMD:C_0805_2012Metric | Samsung Electro-Mechanics | CL21B104KBCNNNC | CAP CER 0.1UF 50V X7R 0805
C6 | 4.7uF | Capacitor_SMD:C_0805_2012Metric | Samsung Electro-Mechanics | CL21A475KOFNNNG | CAP CER 4.7UF 16V X5R 0805
C7 | 4.7uF | Capacitor_SMD:C_0805_2012Metric | Samsung Electro-Mechanics | CL21A475KOFNNNG | CAP CER 4.7UF 16V X5R 0805
C8 | 100nF | Capacitor_SMD:C_0805_2012Metric | Samsung Electro-Mechanics | CL21B104KBCNNNC | CAP CER 0.1UF 50V X7R 0805
C9 | 4.7uF | Capacitor_SMD:C_0805_2012Metric | Samsung Electro-Mechanics | CL21A475KOFNNNG | CAP CER 4.7UF 16V X5R 0805
C10 | 1uF | Capacitor_SMD:C_0805_2012Metric | Samsung Electro-Mechanics | CL21B105KOFNNWE | CAP CER 1UF 16V X7R 0805
C11 | 10uF | Capacitor_SMD:C_0805_2012Metric | YAGEO | CC0805KRX5R7BB106 | CAP CER 10UF 16V X5R 0805
C12 | 100nF | Capacitor_SMD:C_0805_2012Metric | Samsung Electro-Mechanics | CL21B104KBCNNNC | CAP CER 0.1UF 50V X7R 0805
C13 | 100uF | Capacitor_SMD:CP_Elec_6.3x5.4 | Nichicon | UCD1C101MCL1GS | CAP ALUM 100UF 20% 16V SMD 6.3mm dia
C14 | 100nF | Capacitor_SMD:C_0805_2012Metric | Samsung Electro-Mechanics | CL21B104KBCNNNC | CAP CER 0.1UF 50V X7R 0805
C15 | 100nF | Capacitor_SMD:C_0805_2012Metric | Samsung Electro-Mechanics | CL21B104KBCNNNC | CAP CER 0.1UF 50V X7R 0805
C16 | 10uF | Capacitor_SMD:C_0805_2012Metric | YAGEO | CC0805KRX5R7BB106 | CAP CER 10UF 16V X5R 0805
C17 | 100nF | Capacitor_SMD:C_0805_2012Metric | Samsung Electro-Mechanics | CL21B104KBCNNNC | CAP CER 0.1UF 50V X7R 0805
C19 | 22uF | Capacitor_SMD:C_0805_2012Metric | Samsung Electro-Mechanics | CL21A226KOQNNNG | CAP CER 22UF 16V X5R 0805
C20 | 22uF | Capacitor_SMD:C_0805_2012Metric | Samsung Electro-Mechanics | CL21A226KOQNNNG | CAP CER 22UF 16V X5R 0805
C22 | 100nF | Capacitor_SMD:C_0805_2012Metric | Samsung Electro-Mechanics | CL21B104KBCNNNC | CAP CER 0.1UF 50V X7R 0805
C23 | 10uF | Capacitor_SMD:C_0805_2012Metric | YAGEO | CC0805KRX5R7BB106 | CAP CER 10UF 16V X5R 0805
C24 | 100nF | Capacitor_SMD:C_0805_2012Metric | Samsung Electro-Mechanics | CL21B104KBCNNNC | CAP CER 0.1UF 50V X7R 0805
D1 | B5819W | Diode_SMD:D_SOD-123 | MCC (Micro Commercial Components) | B5819W-TP | DIODE SCHOTTKY 40V 1A SOD-123
D2 | CHG-GREEN | LED_SMD:LED_Kingbright_KPA-3010_3x2x1mm | Kingbright | KPA-3010SGC | LED GREEN CLEAR RIGHT ANGLE SMD 3.0x2.0x1.0mm side-view
D3 | STATUS | LED_SMD:LED_Kingbright_KPA-3010_3x2x1mm | Kingbright | KPA-3010QBC-D | LED BLUE CLEAR RIGHT ANGLE SMD 3.0x2.0x1.0mm side-view; status + WiFi setup feedback
J1 | USB-C | Connector_USB:USB_C_Receptacle_HRO_TYPE-C-31-M-12 | Korean Hroparts (HRO) | TYPE-C-31-M-12 | USB Type-C 2.0 receptacle 16P mid-mount SMD
J3 | SERVO | Connector_PinHeader_2.54mm:PinHeader_1x03_P2.54mm_Vertical | Wurth Elektronik | 61300311121 | CONN HEADER VERT 3POS 2.54MM THT
J4 | LiPo | Connector_JST:JST_PH_B2B-PH-K_1x02_P2.00mm_Vertical | JST | B2B-PH-K-S | CONN HEADER VERT 2POS 2MM JST PH THT
J5 | STEMMA_QT | Connector_JST:JST_SH_SM04B-SRSS-TB_1x04-1MP_P1.00mm_Horizontal | JST | SM04B-SRSS-TB(LF)(SN) | CONN HEADER SMD R/A 4POS 1MM JST SH; STEMMA QT / Qwiic
Q3 | DMG2305UX | Package_TO_SOT_SMD:SOT-23 | Diodes Incorporated | DMG2305UX-7 | MOSFET P-CH 20V 4.2A SOT-23
Q4 | DMG2305UX | Package_TO_SOT_SMD:SOT-23 | Diodes Incorporated | DMG2305UX-7 | MOSFET P-CH 20V 4.2A SOT-23
Q5 | DMG2305UX | Package_TO_SOT_SMD:SOT-23 | Diodes Incorporated | DMG2305UX-7 | MOSFET P-CH 20V 4.2A SOT-23
Q6 | DMG2305UX | Package_TO_SOT_SMD:SOT-23 | Diodes Incorporated | DMG2305UX-7 | MOSFET P-CH 20V 4.2A SOT-23
Q7 | 2N7002 | Package_TO_SOT_SMD:SOT-23 | Diodes Incorporated | 2N7002-7-F | MOSFET N-CH 60V 115MA SOT-23
Q8 | DMG2305UX | Package_TO_SOT_SMD:SOT-23 | Diodes Incorporated | DMG2305UX-7 | MOSFET P-CH 20V 4.2A SOT-23
Q9 | BSS138 | Package_TO_SOT_SMD:SOT-23 | onsemi | BSS138 | MOSFET N-CH 50V 220MA SOT-23
Q10 | BSS138 | Package_TO_SOT_SMD:SOT-23 | onsemi | BSS138 | MOSFET N-CH 50V 220MA SOT-23
R1 | 10k | Resistor_SMD:R_0805_2012Metric | YAGEO | RC0805FR-0710KL | RES 10K OHM 1% 1/8W 0805
R2 | 10k | Resistor_SMD:R_0805_2012Metric | YAGEO | RC0805FR-0710KL | RES 10K OHM 1% 1/8W 0805
R3 | 10k | Resistor_SMD:R_0805_2012Metric | YAGEO | RC0805FR-0710KL | RES 10K OHM 1% 1/8W 0805
R4 | 100k | Resistor_SMD:R_0805_2012Metric | YAGEO | RC0805FR-07100KL | RES 100K OHM 1% 1/8W 0805
R5 | 10k | Resistor_SMD:R_0805_2012Metric | YAGEO | RC0805FR-0710KL | RES 10K OHM 1% 1/8W 0805
R9 | 100k | Resistor_SMD:R_0805_2012Metric | YAGEO | RC0805FR-07100KL | RES 100K OHM 1% 1/8W 0805
R10 | 5.1k | Resistor_SMD:R_0805_2012Metric | YAGEO | RC0805FR-075K1L | RES 5.1K OHM 1% 1/8W 0805
R11 | 5.1k | Resistor_SMD:R_0805_2012Metric | YAGEO | RC0805FR-075K1L | RES 5.1K OHM 1% 1/8W 0805
R12 | 47.5k | Resistor_SMD:R_0805_2012Metric | YAGEO | RC0805FR-0747K5L | RES 47.5K OHM 1% 1/8W 0805
R13 | 22.1k | Resistor_SMD:R_0805_2012Metric | YAGEO | RC0805FR-0722K1L | RES 22.1K OHM 1% 1/8W 0805
R14 | 3.3k | Resistor_SMD:R_0805_2012Metric | YAGEO | RC0805FR-073K3L | RES 3.3K OHM 1% 1/8W 0805
R15 | 1k | Resistor_SMD:R_0805_2012Metric | YAGEO | RC0805FR-071KL | RES 1K OHM 1% 1/8W 0805
R16 | 220R | Resistor_SMD:R_0805_2012Metric | YAGEO | RC0805FR-07220RL | RES 220 OHM 1% 1/8W 0805
R17 | 100R | Resistor_SMD:R_0805_2012Metric | YAGEO | RC0805FR-07100RL | RES 100 OHM 1% 1/8W 0805
R18 | 10k | Resistor_SMD:R_0805_2012Metric | YAGEO | RC0805FR-0710KL | RES 10K OHM 1% 1/8W 0805
R19 | 10k | Resistor_SMD:R_0805_2012Metric | YAGEO | RC0805FR-0710KL | RES 10K OHM 1% 1/8W 0805
R20 | 1M | Resistor_SMD:R_0805_2012Metric | YAGEO | RC0805FR-071ML | RES 1M OHM 1% 1/8W 0805
R21 | 270k | Resistor_SMD:R_0805_2012Metric | YAGEO | RC0805FR-07270KL | RES 270K OHM 1% 1/8W 0805
R24 | 22R | Resistor_SMD:R_0805_2012Metric | YAGEO | RC0805FR-0722RL | RES 22 OHM 1% 1/8W 0805
R25 | 22R | Resistor_SMD:R_0805_2012Metric | YAGEO | RC0805FR-0722RL | RES 22 OHM 1% 1/8W 0805
R26 | 10M | Resistor_SMD:R_0805_2012Metric | YAGEO | RC0805FR-0710ML | RES 10M OHM 1% 1/8W 0805
R27 | 100k | Resistor_SMD:R_0805_2012Metric | YAGEO | RC0805FR-07100KL | RES 100K OHM 1% 1/8W 0805
R28 | 47.5k | Resistor_SMD:R_0805_2012Metric | YAGEO | RC0805FR-0747K5L | RES 47.5K OHM 1% 1/8W 0805
R29 | 10k | Resistor_SMD:R_0805_2012Metric | YAGEO | RC0805FR-0710KL | RES 10K OHM 1% 1/8W 0805
R30 | 10k | Resistor_SMD:R_0805_2012Metric | YAGEO | RC0805FR-0710KL | RES 10K OHM 1% 1/8W 0805
R31 | 10k | Resistor_SMD:R_0805_2012Metric | YAGEO | RC0805FR-0710KL | RES 10K OHM 1% 1/8W 0805
R32 | 18k | Resistor_SMD:R_0805_2012Metric | YAGEO | RC0805FR-0718KL | RES 18K OHM 1% 1/8W 0805
SW1 | RESET | Button_Switch_SMD:SW_Push_1P1T_NO_CK_KMR2 | C&K | KMR221G LFS | SWITCH TACTILE SPST-NO 0.05A 32V SMD
SW2 | BOOT | Button_Switch_SMD:SW_Push_1P1T_NO_CK_KMR2 | C&K | KMR221G LFS | SWITCH TACTILE SPST-NO 0.05A 32V SMD
SW3 | POWER | Button_Switch_THT:SW_Slide_SPDT_Angled_CK_OS102011MA1Q | C&K | OS102011MA1QN1 | SWITCH SLIDE SPDT 0.1A 12V THT right-angle, 4 mm actuator
SW4 | WIFI_MODE | SamacSys_Parts:OS103011MA7QP1 | C&K | OS103011MA7QP1 | SWITCH SLIDE SP3T ON-ON-ON 0.1A 12V THT right-angle, 4 mm actuator
U1 | ESP32-C3-WROOM-02 | Espressif:ESP32-C3-WROOM-02 | Espressif Systems | ESP32-C3-WROOM-02-N4 | ESP32-C3 WiFi/BLE module, 4 MB flash, PCB antenna, 18x20 mm castellated
U3 | MCP73831 | Package_TO_SOT_SMD:SOT-23-5 | Microchip Technology | MCP73831T-2ACI/OT | IC BATT CNTL LI-ION 1CEL SOT-23-5
U4 | AP2112K-3.3 | Package_TO_SOT_SMD:SOT-23-5 | Diodes Incorporated | AP2112K-3.3TRG1 | IC REG LINEAR 3.3V 600MA SOT-23-5
U5 | BME688 | Package_LGA:Bosch_LGA-8_3x3mm_P0.8mm_ClockwisePinNumbering | Bosch Sensortec | BME688 | SENSOR GAS/HUM/PRES/TEMP I2C LGA-8
U6 | USBLC6-2SC6 | Package_TO_SOT_SMD:SOT-23-6 | STMicroelectronics | USBLC6-2SC6 | TVS DIODE 5.25VWM 17VC SOT-23-6
U8 | USBLC6-2SC6 | Package_TO_SOT_SMD:SOT-23-6 | STMicroelectronics | USBLC6-2SC6 | TVS DIODE 5.25VWM 17VC SOT-23-6

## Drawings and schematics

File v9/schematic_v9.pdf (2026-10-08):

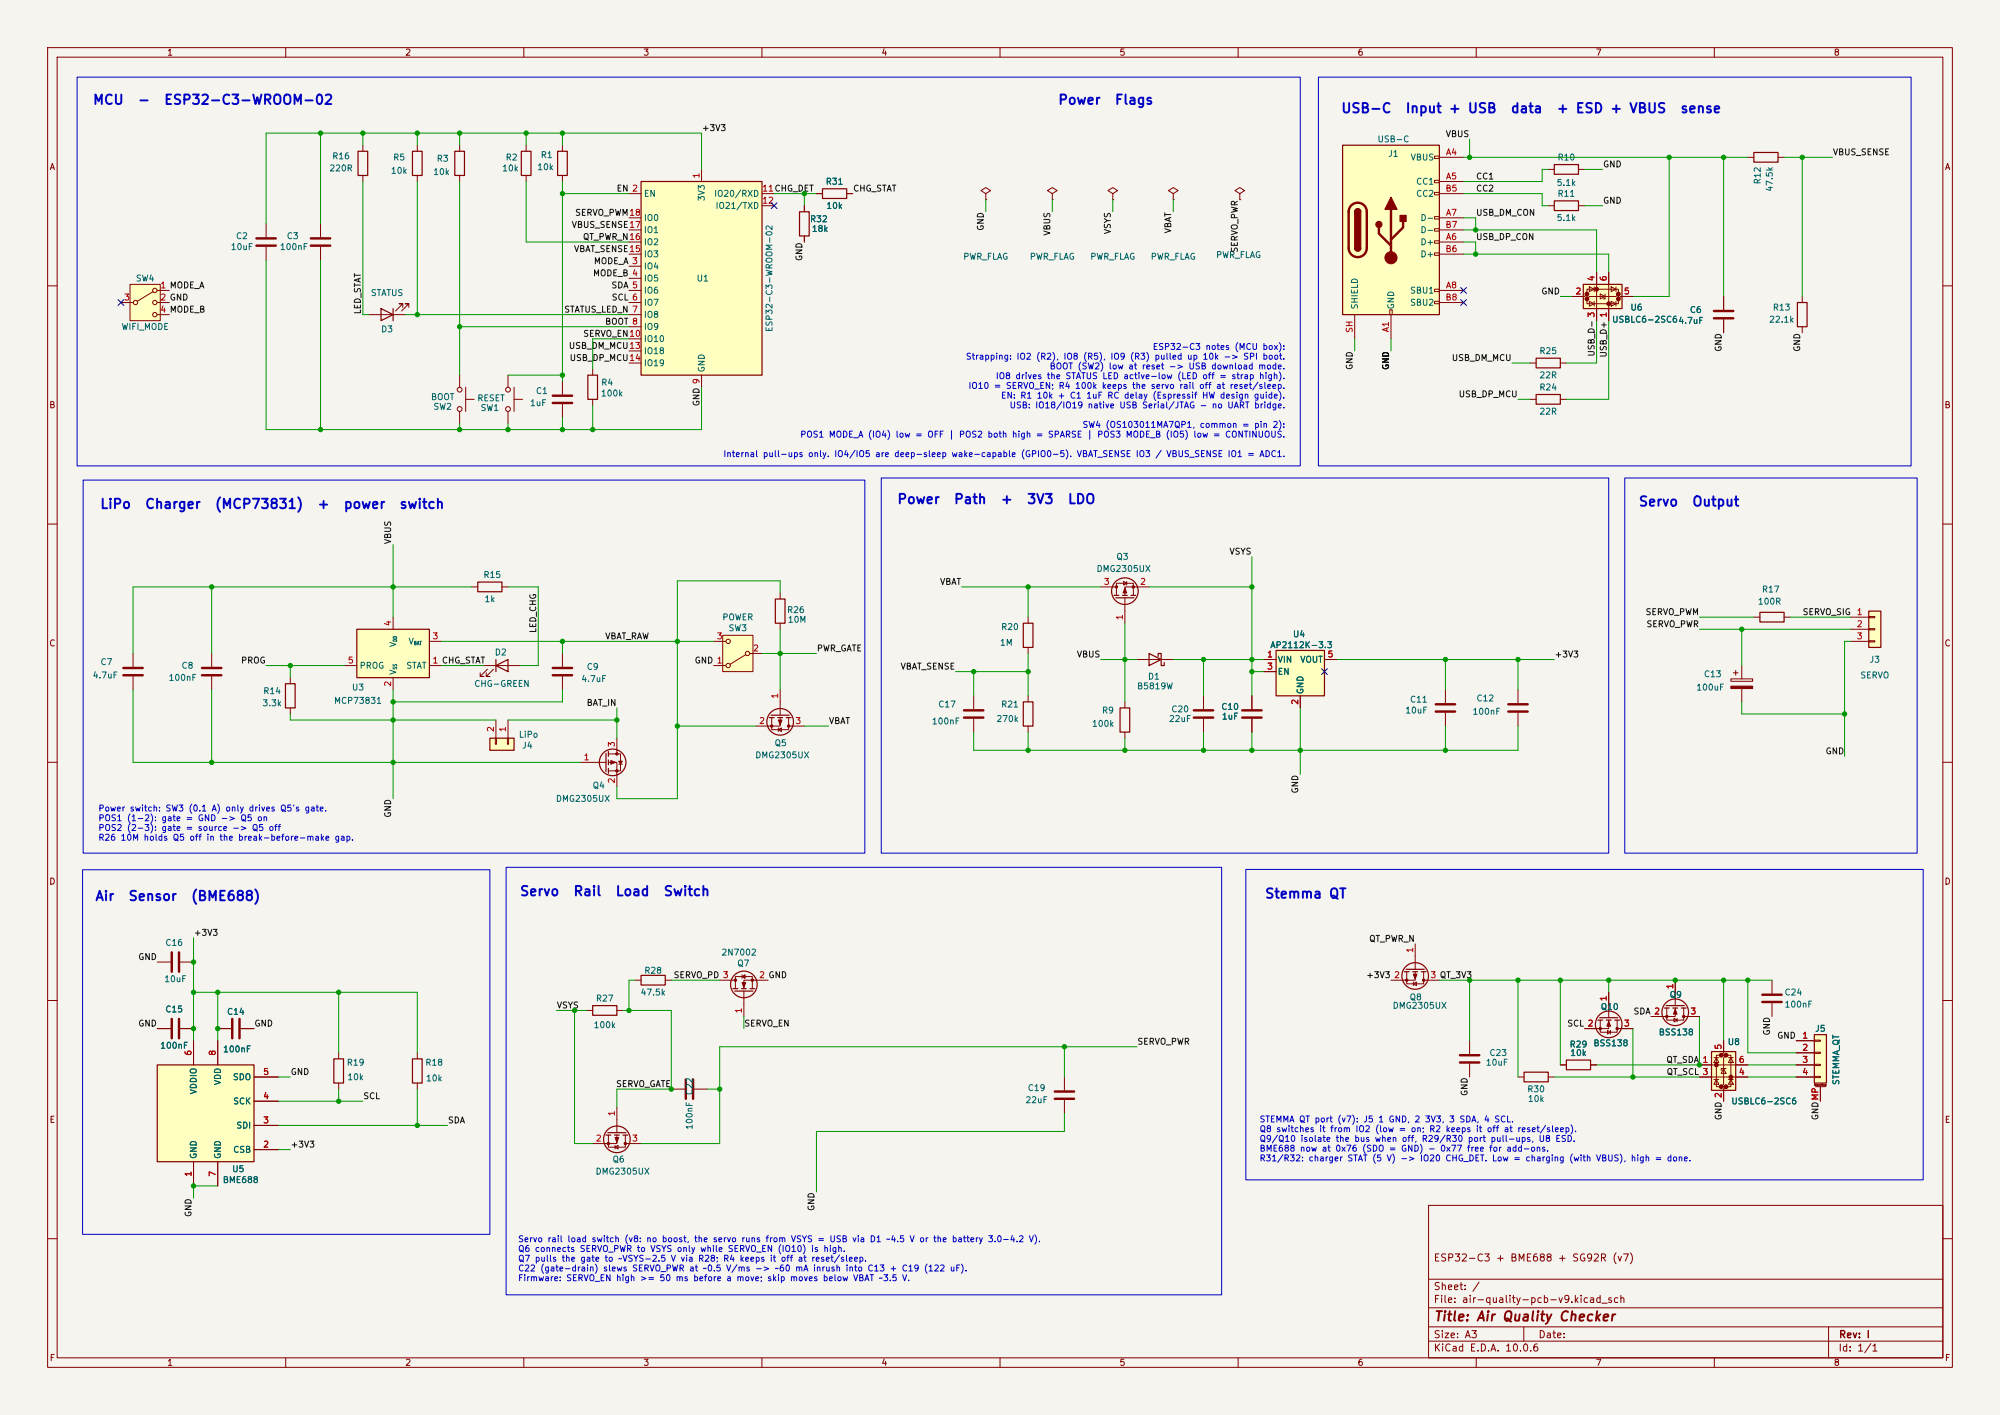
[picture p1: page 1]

USB-C Input + USB data + ESD + VBUS sense

CC2 GND

BOOT SERVO_EN

Strapping: IO2 (R2), IO8 (R5), IO9 (R3) pulled up 10k -> SPI boot. BOOT (SW2) low at reset -> USB download mode.

IO10 = SERVO_EN; R4 100k keeps the servo rail off at reset/sleep. EN: R1 10k + C1 1uF RC delay (Espressif HW design guide). USB: IO18/IO19 native USB Serial/JTAG - no UART bridge. SW4 (OS103011MA7QP1, common = pin 2): POS1 MODE_A (IO4) low = OFF | POS2 both high = SPARSE | POS3 MODE_B (IO5) low = CONTINUOUS.

IO8 drives the STATUS LED active-low (LED off = strap high).

Internal pull-ups only. IO4/IO5 are deep-sleep wake-capable (GPIO0-5). VBAT_SENSE IO3 / VBUS_SENSE IO1 = ADC1. LiPo Charger (MCP73831) + power switch

Power switch: SW3 (0.1 A) only drives Q5's gate. POS1 (1-2): gate = GND -> Q5 on POS2 (2-3): gate = source -> Q5 off R26 10M holds Q5 off in the break-before-make gap. Air Sensor (BME688)

Servo Rail Load Switch

STEMMA QT port (v7): J5 1 GND, 2 3V3, 3 SDA, 4 SCL. Q8 switches it from IO2 (low = on; R2 keeps it off at reset/sleep).

Q9/Q10 isolate the bus when off, R29/R30 port pull-ups, U8 ESD. BME688 now at 0x76 (SDO = GND) - 0x77 free for add-ons. R31/R32: charger STAT (5 V) -> IO20 CHG_DET. Low = charging (with VBUS), high = done.

Servo rail load switch (v8: no boost, the servo runs from VSYS = USB via D1 ~4.5 V or the battery 3.0-4.2 V). Q6 connects SERVO_PWR to VSYS only while SERVO_EN (IO10) is high. Q7 pulls the gate to ~VSYS-2.5 V via R28; R4 keeps it off at reset/sleep. C22 (gate-drain) slews SERVO_PWR at ~0.5 V/ms -> ~60 mA inrush into C13 + C19 (122 uF). Firmware: SERVO_EN high >= 50 ms before a move; skip moves below VBAT ~3.5 V.

Sheet: /
File: air-quality-pcb-v9.kicad_sch
Title: Air Quality Checker

Size: A3 | Rev: I | F Date:
KiCad E.D.A. 10.0.6 | Id: 1/1

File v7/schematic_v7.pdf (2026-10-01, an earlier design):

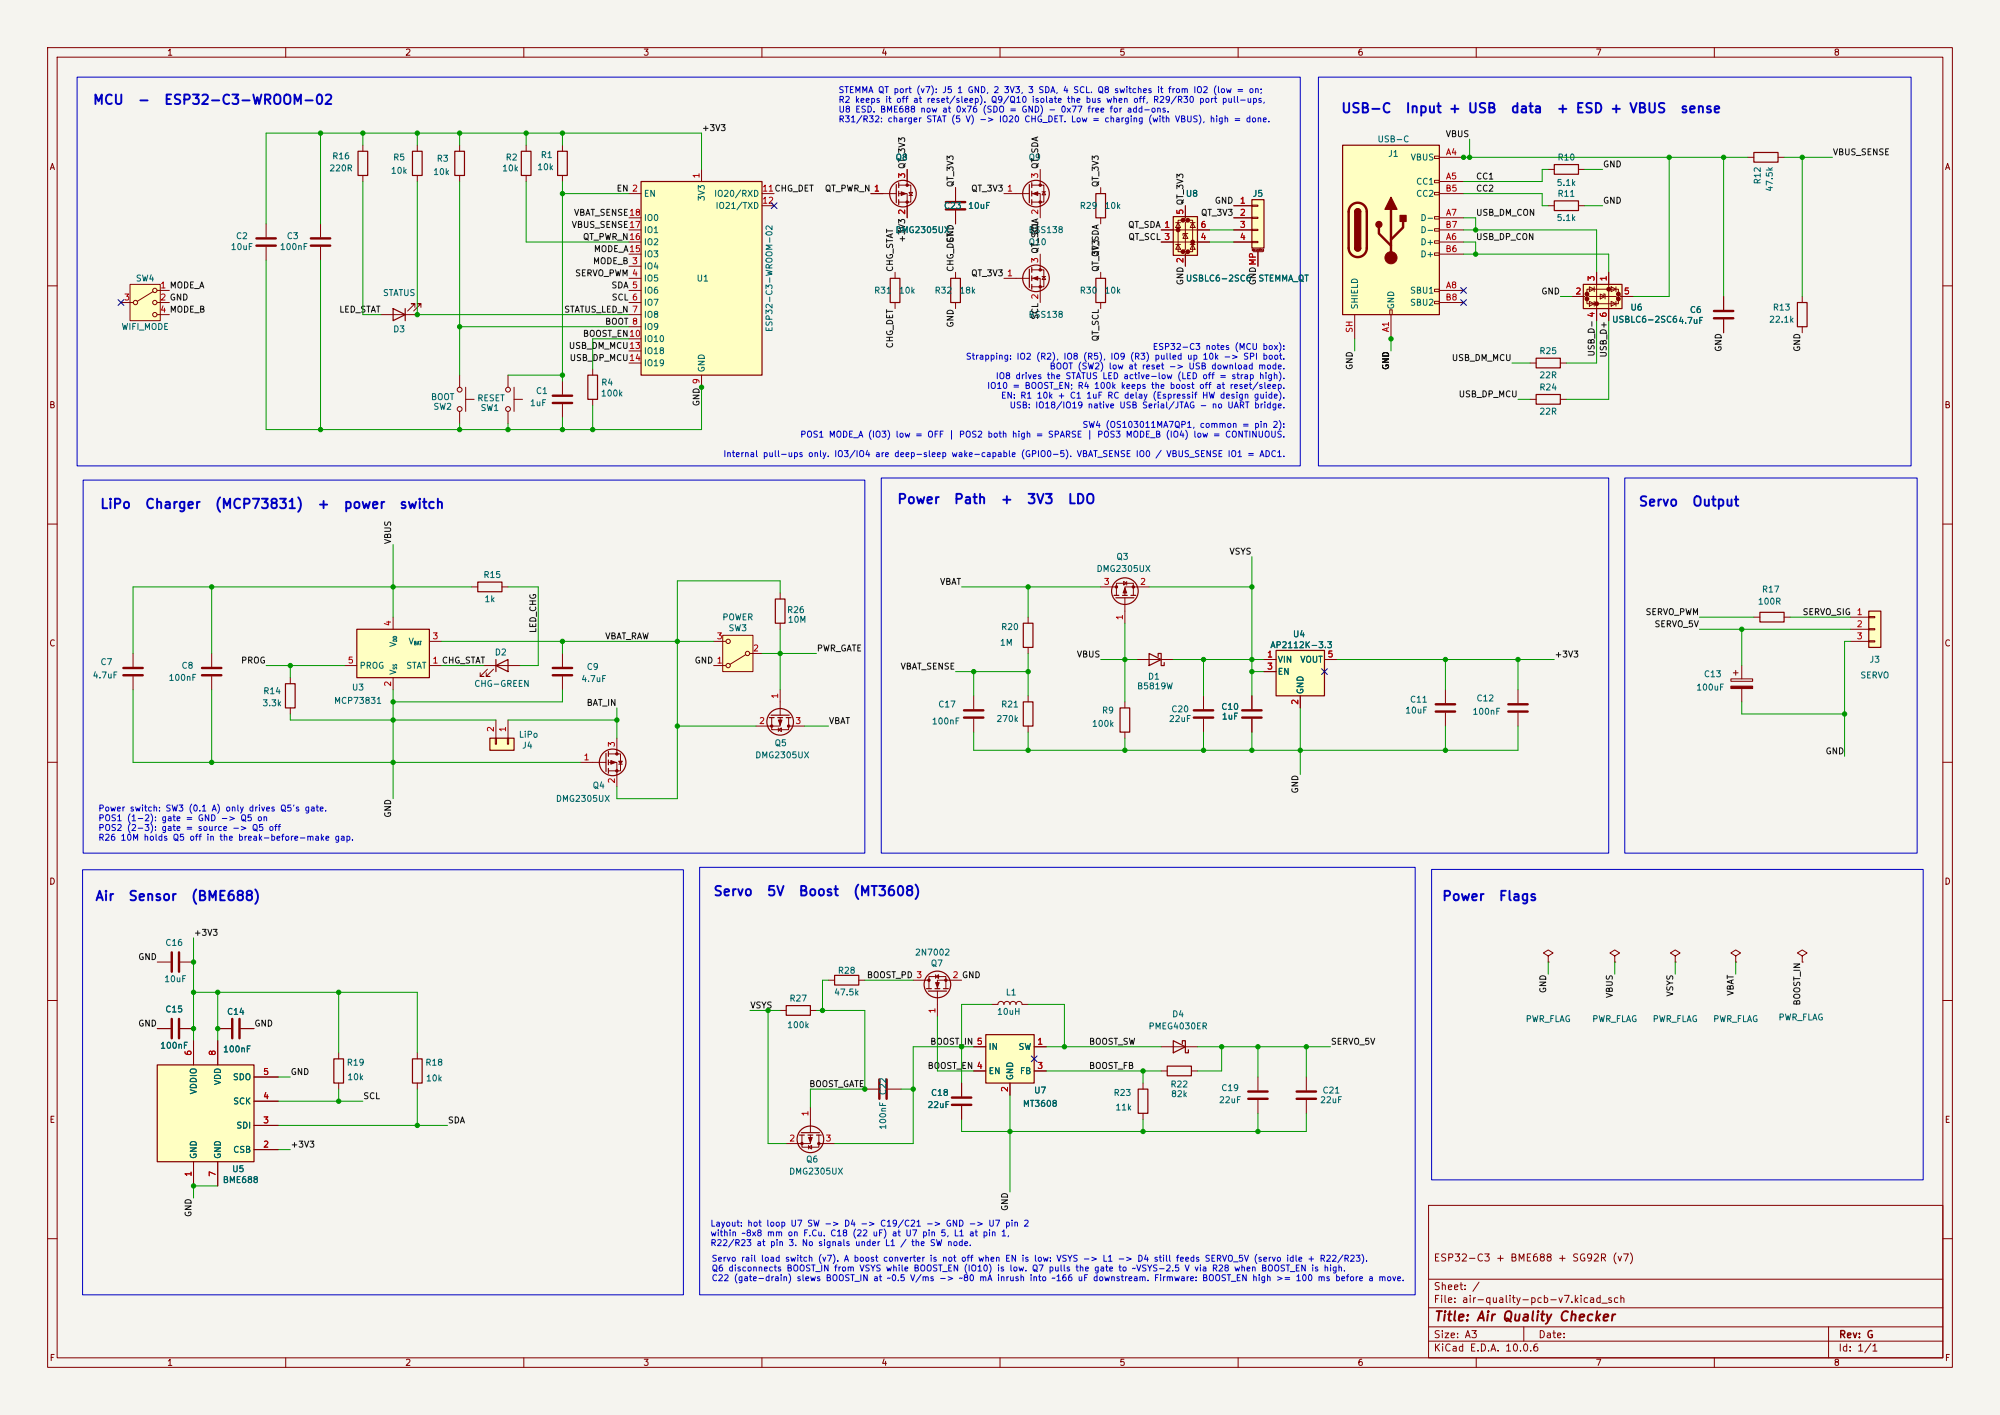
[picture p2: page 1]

STEMMA QT port (v7): J5 1 GND, 2 3V3, 3 SDA, 4 SCL. Q8 switches it from IO2 (low = on; R2 keeps it off at reset/sleep). Q9/Q10 isolate the bus when off, R29/R30 port pull-ups, U8 ESD. BME688 now at 0x76 (SDO = GND) - 0x77 free for add-ons. R31/R32: charger STAT (5 V) -> IO20 CHG_DET. Low = charging (with VBUS), high = done. Air Sensor (BME688)
Internal pull-ups only. IO3/IO4 are deep-sleep wake-capable (GPIO0-5). VBAT_SENSE IO0 / VBUS_SENSE IO1 = ADC1. MCU - ESP32-C3-WROOM-02

USB-C Input + USB data + ESD + VBUS sense

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

IO10 = BOOST_EN; R4 100k keeps the boost off at reset/sleep. EN: R1 10k + C1 1uF RC delay (Espressif HW design guide). USB: IO18/IO19 native USB Serial/JTAG - no UART bridge. SW4 (OS103011MA7QP1, common = pin 2): POS1 MODE_A (IO3) low = OFF | POS2 both high = SPARSE | POS3 MODE_B (IO4) low = CONTINUOUS.

IO8 drives the STATUS LED active-low (LED off = strap high).

Servo Output Power switch: SW3 (0.1 A) only drives Q5's gate. POS1 (1-2): gate = GND -> Q5 on POS2 (2-3): gate = source -> Q5 off R26 10M holds Q5 off in the break-before-make gap.
LiPo Charger (MCP73831) + power switch

R22/R23 at pin 3. No signals under L1 / the SW node. Servo 5V Boost (MT3608)

Servo rail load switch (v7). A boost converter is not off when EN is low: VSYS -> L1 -> D4 still feeds SERVO_5V (servo idle + R22/R23). Q6 disconnects BOOST_IN from VSYS while BOOST_EN (IO10) is low. Q7 pulls the gate to ~VSYS-2.5 V via R28 when BOOST_EN is high. C22 (gate-drain) slews BOOST_IN at ~0.5 V/ms -> ~80 mA inrush into ~166 uF downstream. Firmware: BOOST_EN high >= 100 ms before a move. Layout: hot loop U7 SW -> D4 -> C19/C21 -> GND -> U7 pin 2 within ~8x8 mm on F.Cu. C18 (22 uF) at U7 pin 5, L1 at pin 1,

Sheet: /
File: air-quality-pcb-v7.kicad_sch
Title: Air Quality Checker

Size: A3 | Rev: G | F Date:
KiCad E.D.A. 10.0.6 | Id: 1/1

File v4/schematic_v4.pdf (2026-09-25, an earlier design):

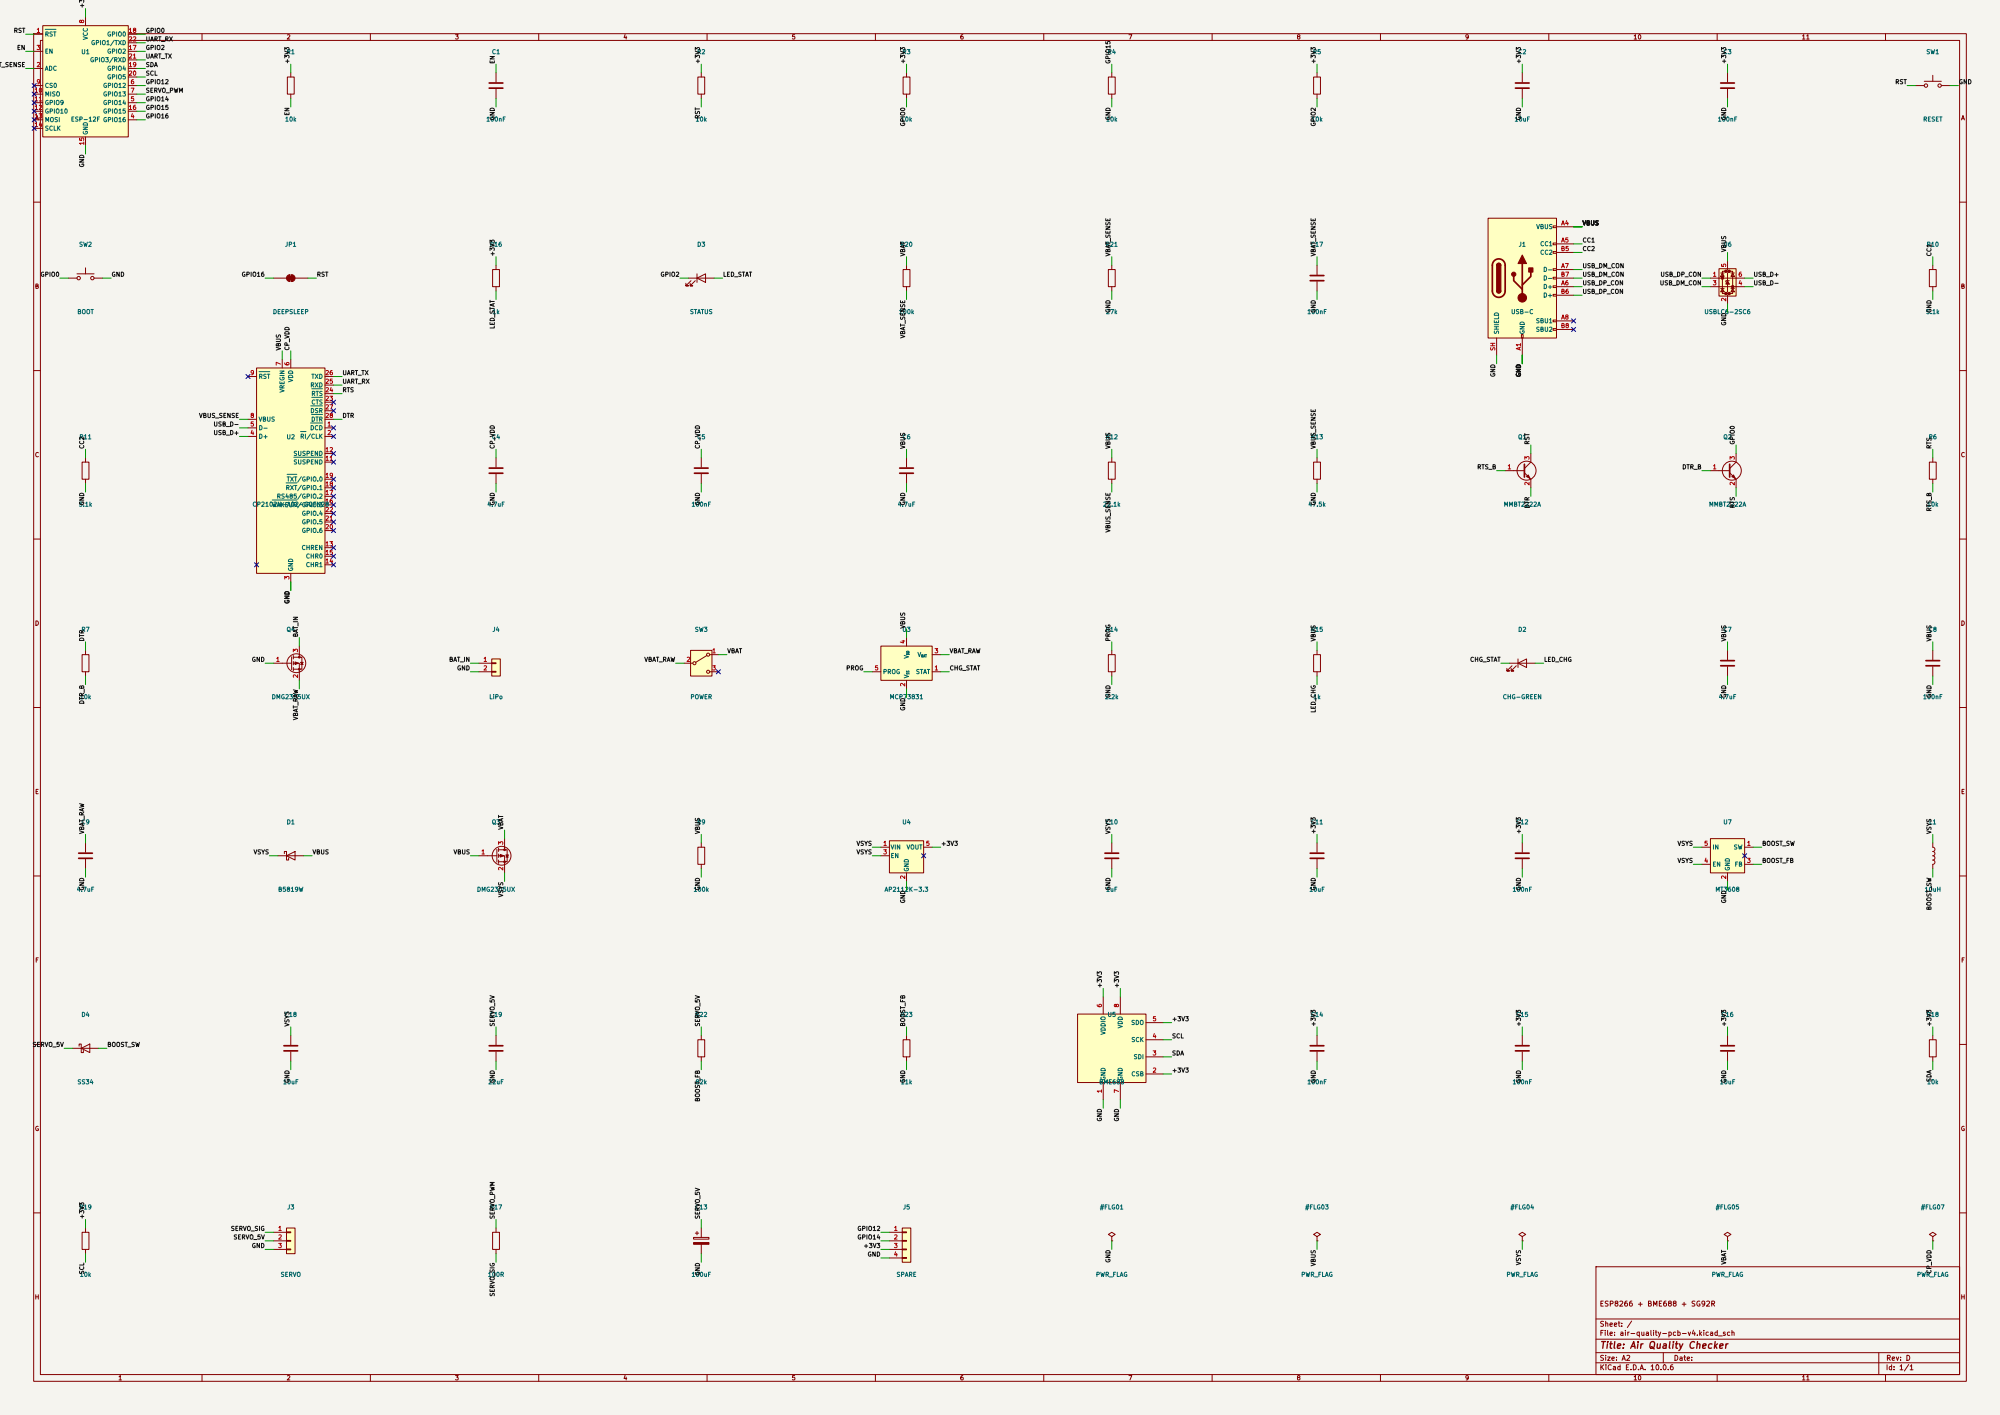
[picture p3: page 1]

SUSPEND 11 SUSPEND 12 CHREN 13 CHR1 14 CHR0 15 WAKEUP/GPIO.3 16 RS485/GPIO.2 17 RXT/GPIO.1 18 TXT/GPIO.0 19 GPIO.6 20 GPIO.5 21 GPIO.4 22 CTS 23 RTS 24 RXD 25 TXD 26 DSR 27 DTR 28 U2 CP2102N-A02-GQFN28

Sheet: /
File: air-quality-pcb-v4.kicad_sch
Title: Air Quality Checker

Size: A2 | Rev: D
KiCad E.D.A. 10.0.6 | Id: 1/1

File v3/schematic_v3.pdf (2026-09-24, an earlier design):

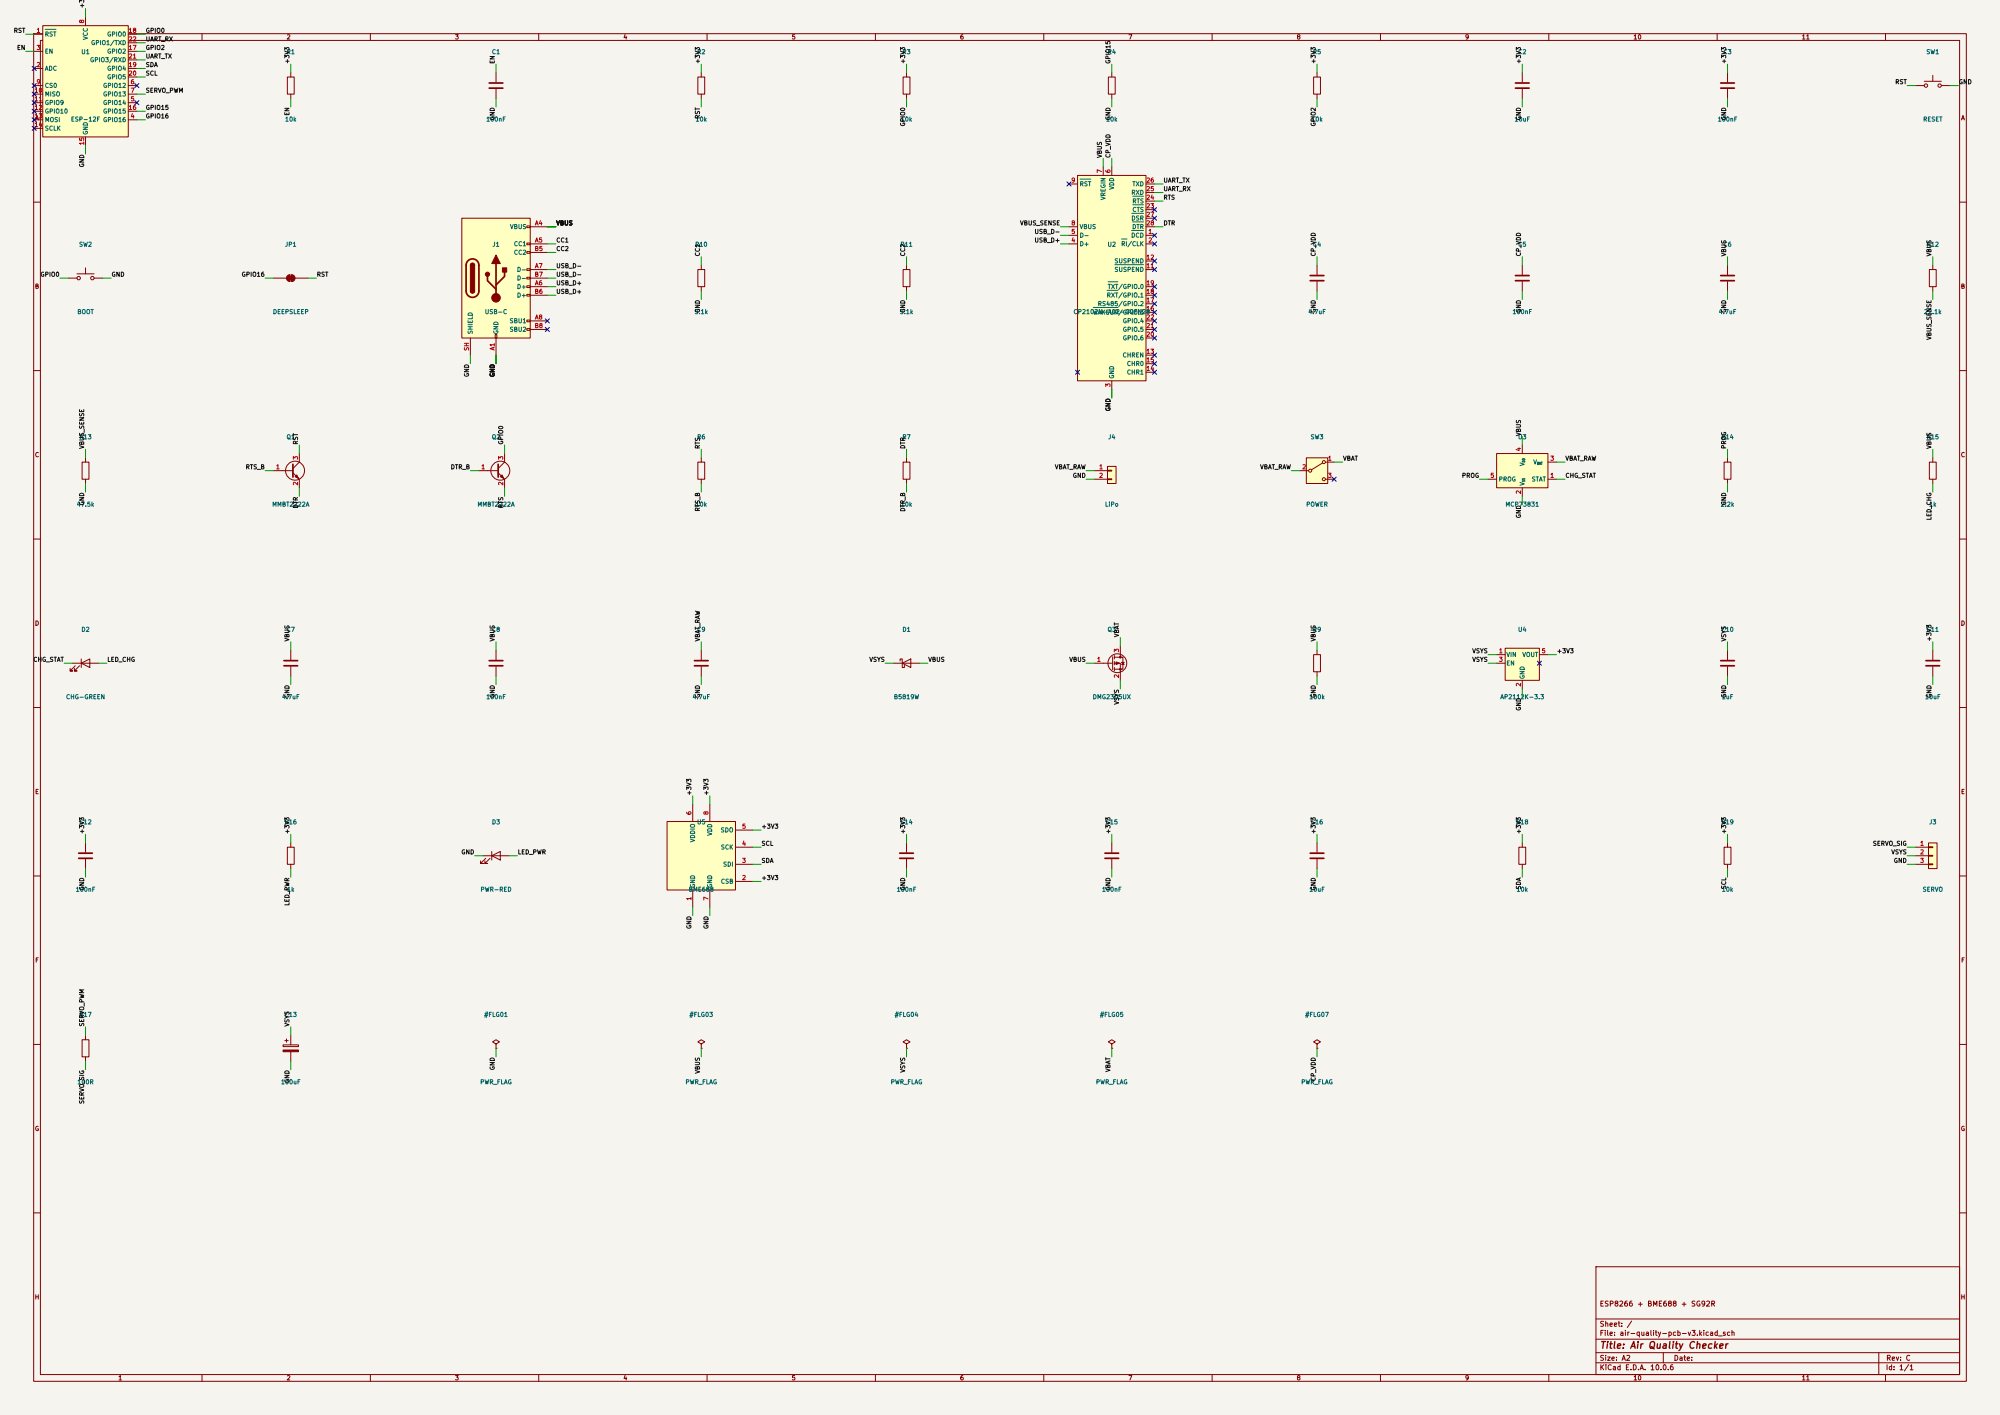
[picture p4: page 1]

Sheet: /
File: air-quality-pcb-v3.kicad_sch
Title: Air Quality Checker

Size: A2 | Rev: C
KiCad E.D.A. 10.0.6 | Id: 1/1

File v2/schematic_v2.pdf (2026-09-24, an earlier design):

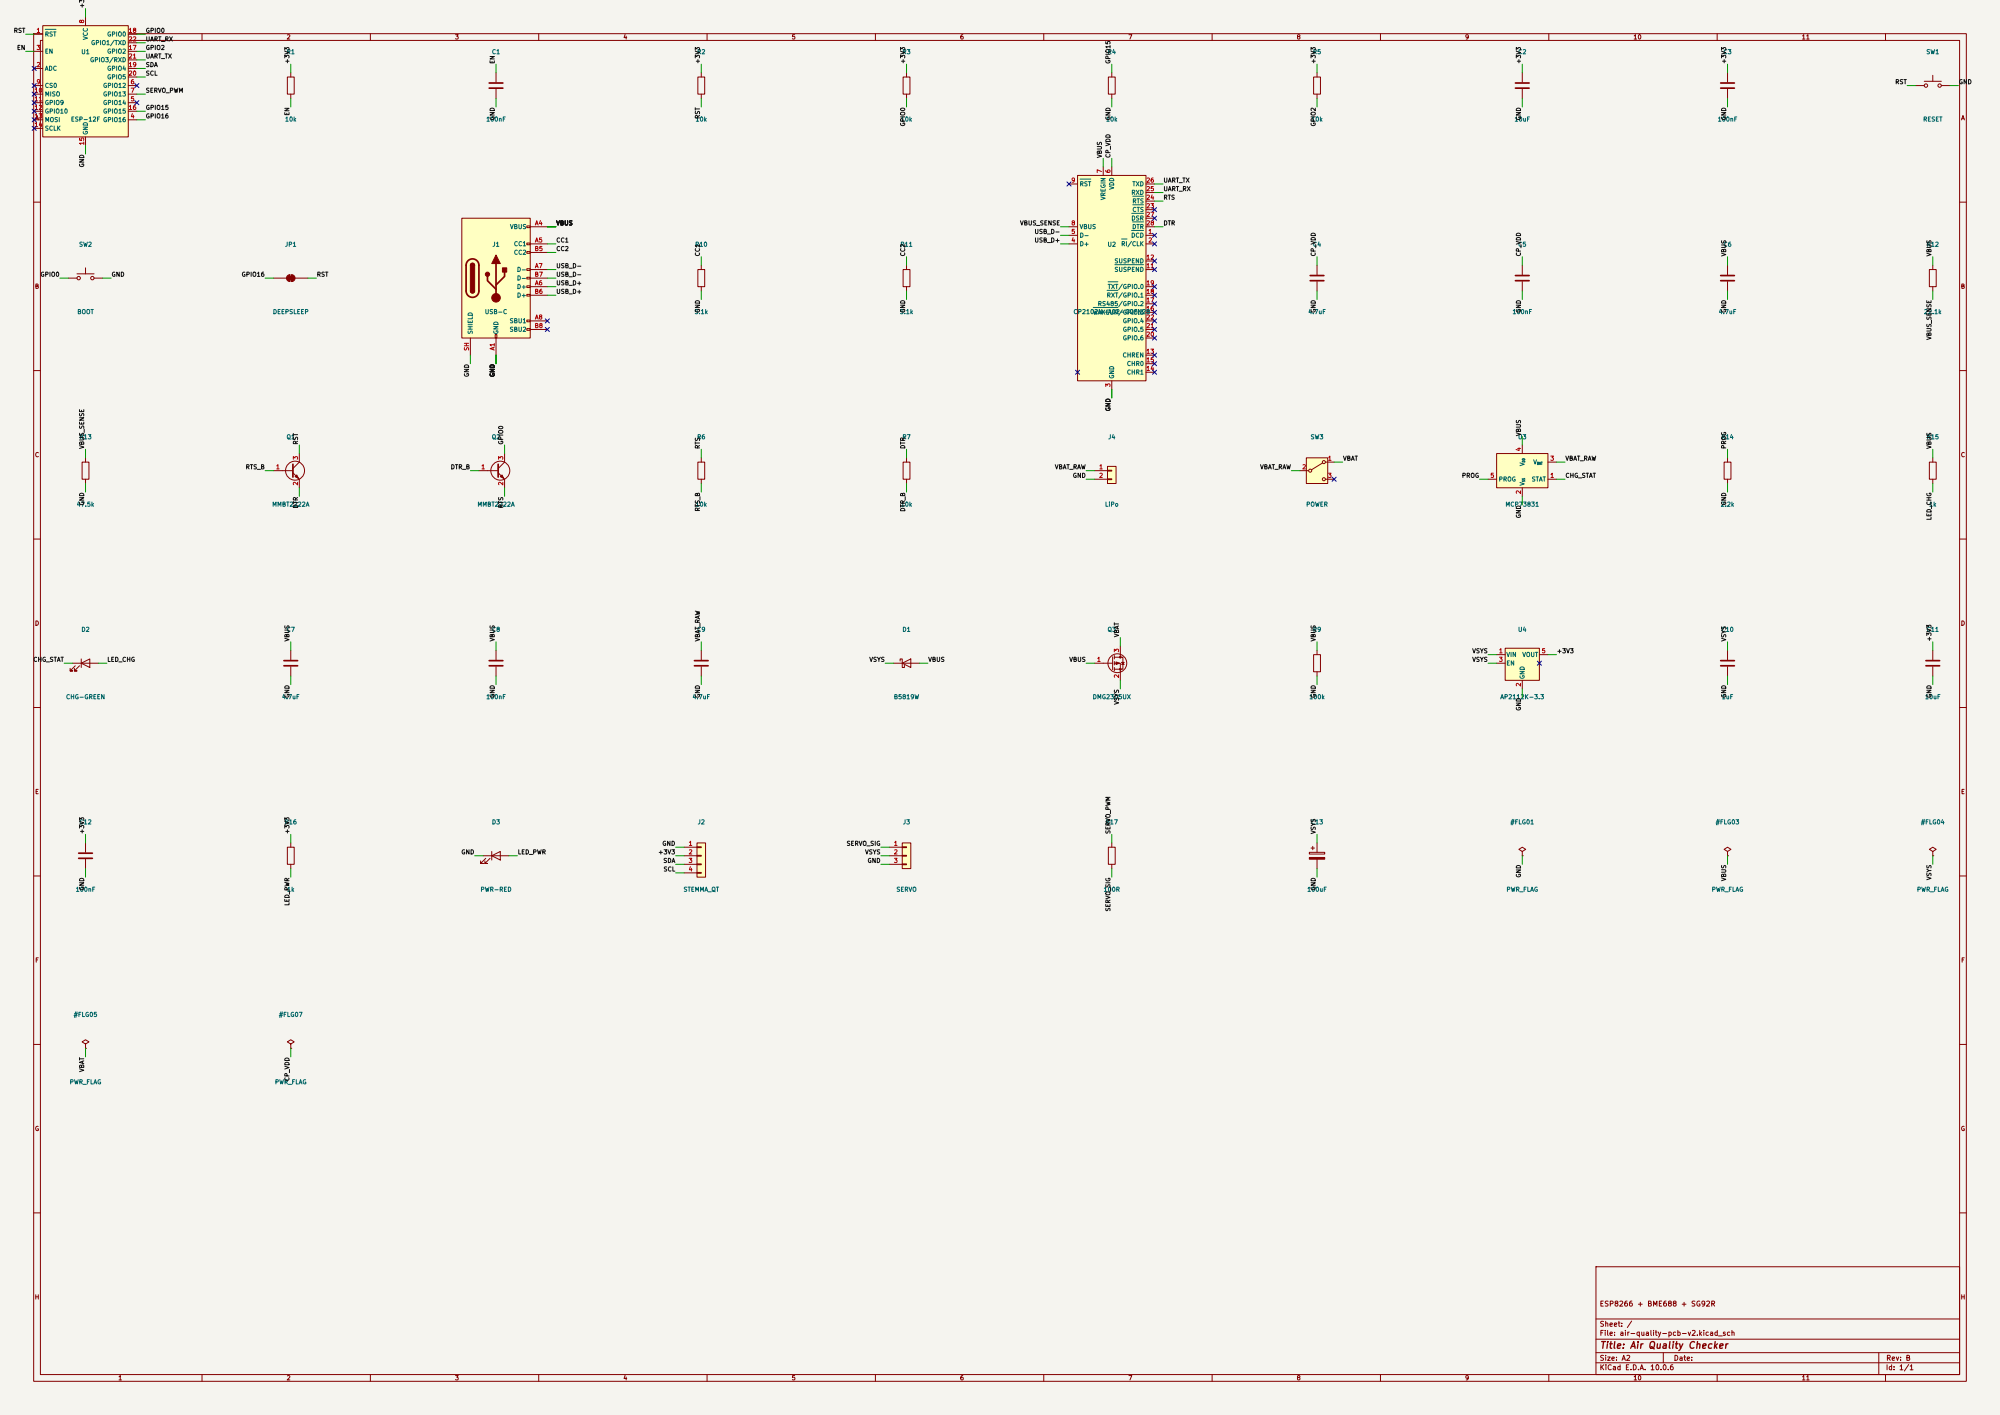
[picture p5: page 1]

Sheet: /
File: air-quality-pcb-v2.kicad_sch
Title: Air Quality Checker

Size: A2 | Rev: B
KiCad E.D.A. 10.0.6 | Id: 1/1

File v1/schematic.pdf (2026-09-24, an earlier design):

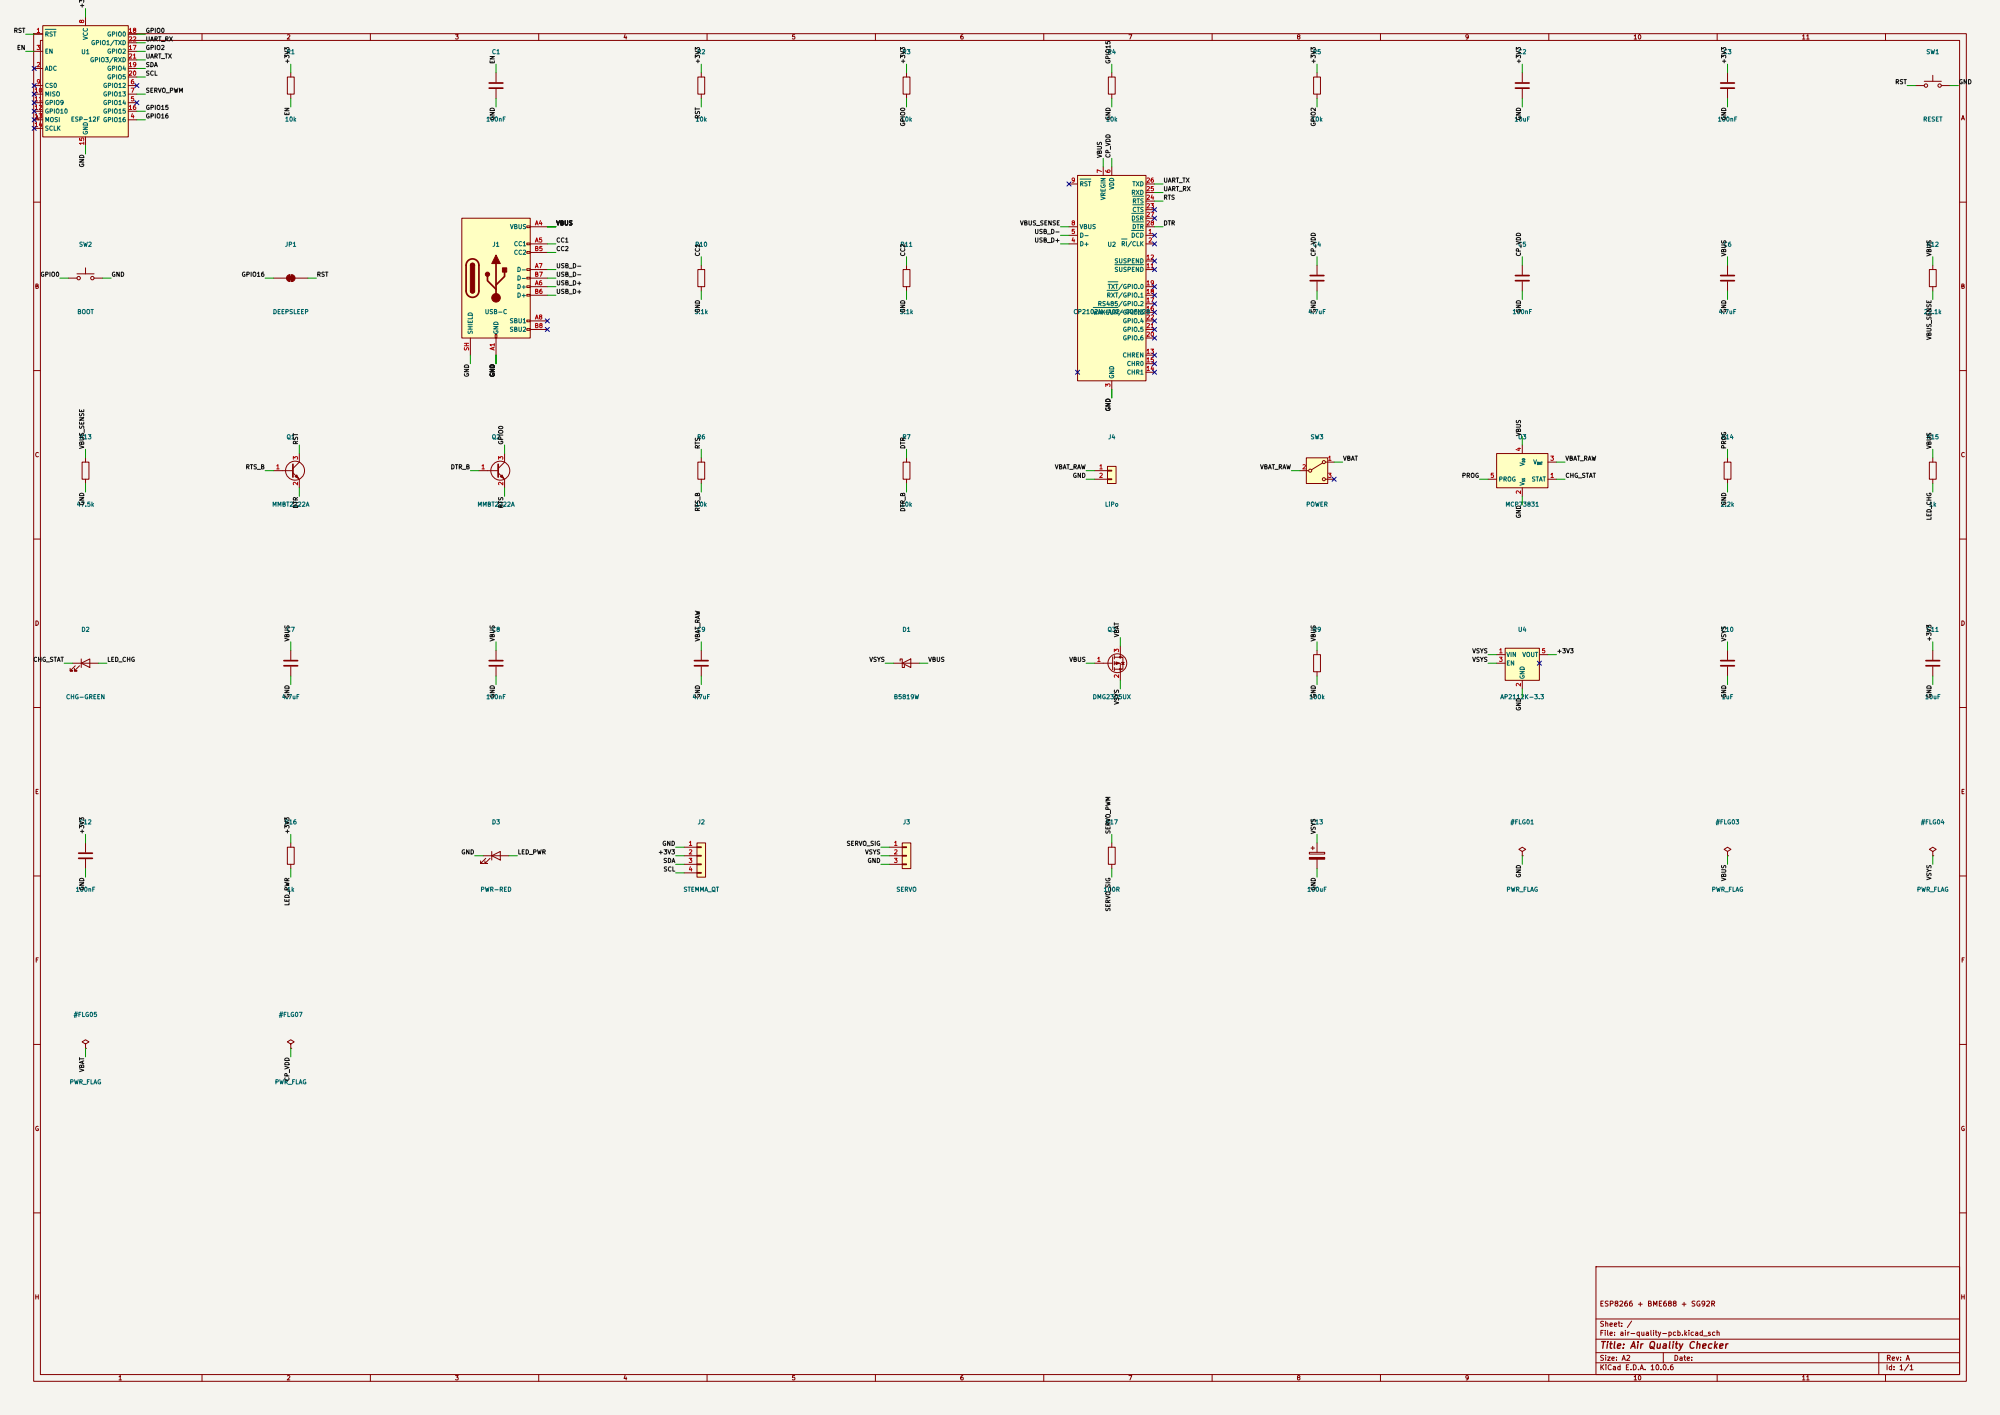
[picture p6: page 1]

Sheet: /
File: air-quality-pcb.kicad_sch
Title: Air Quality Checker

Size: A2 | Rev: A
KiCad E.D.A. 10.0.6 | Id: 1/1

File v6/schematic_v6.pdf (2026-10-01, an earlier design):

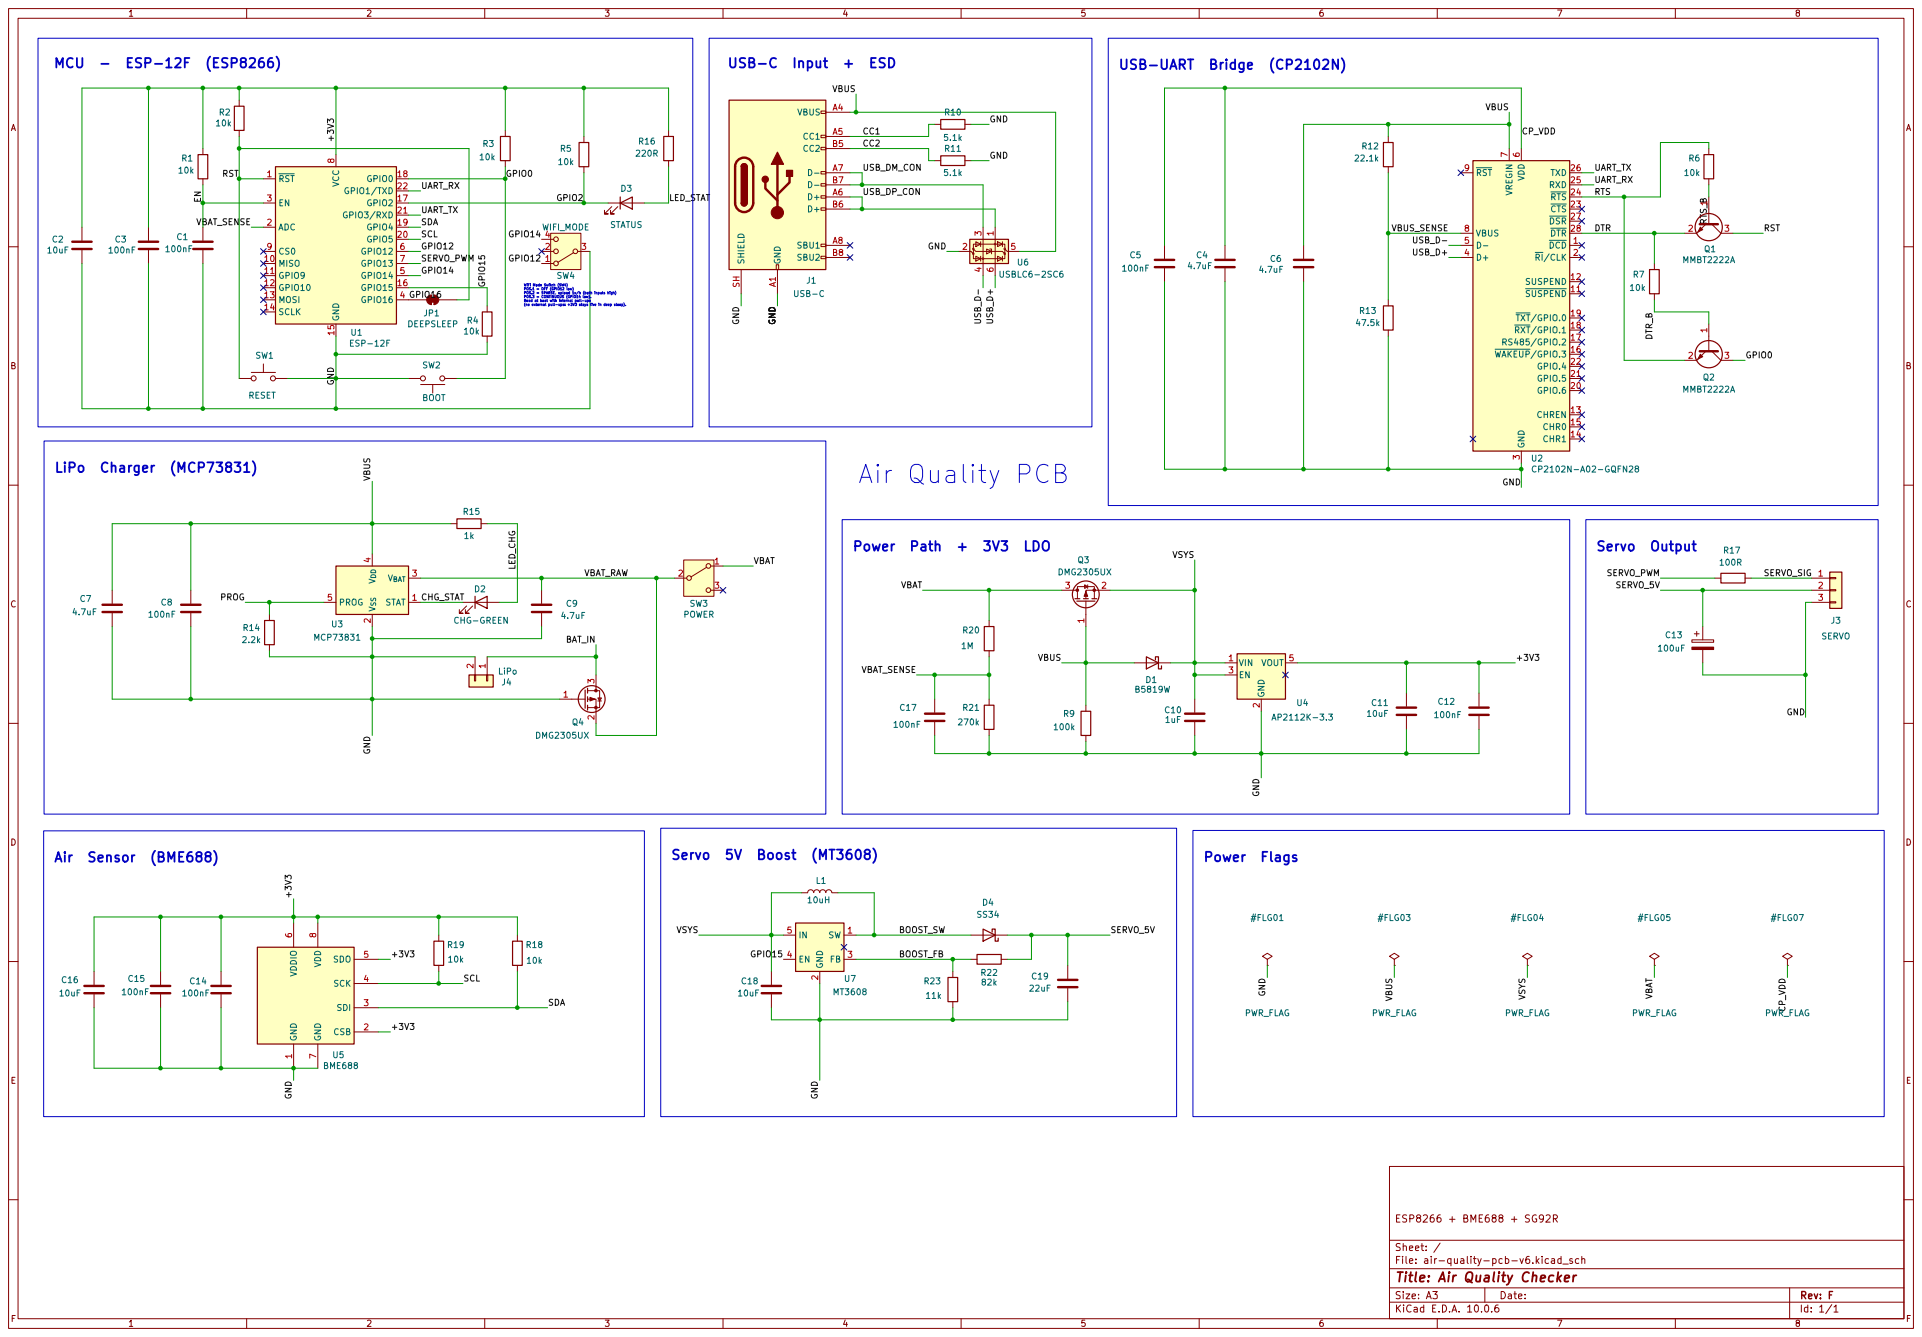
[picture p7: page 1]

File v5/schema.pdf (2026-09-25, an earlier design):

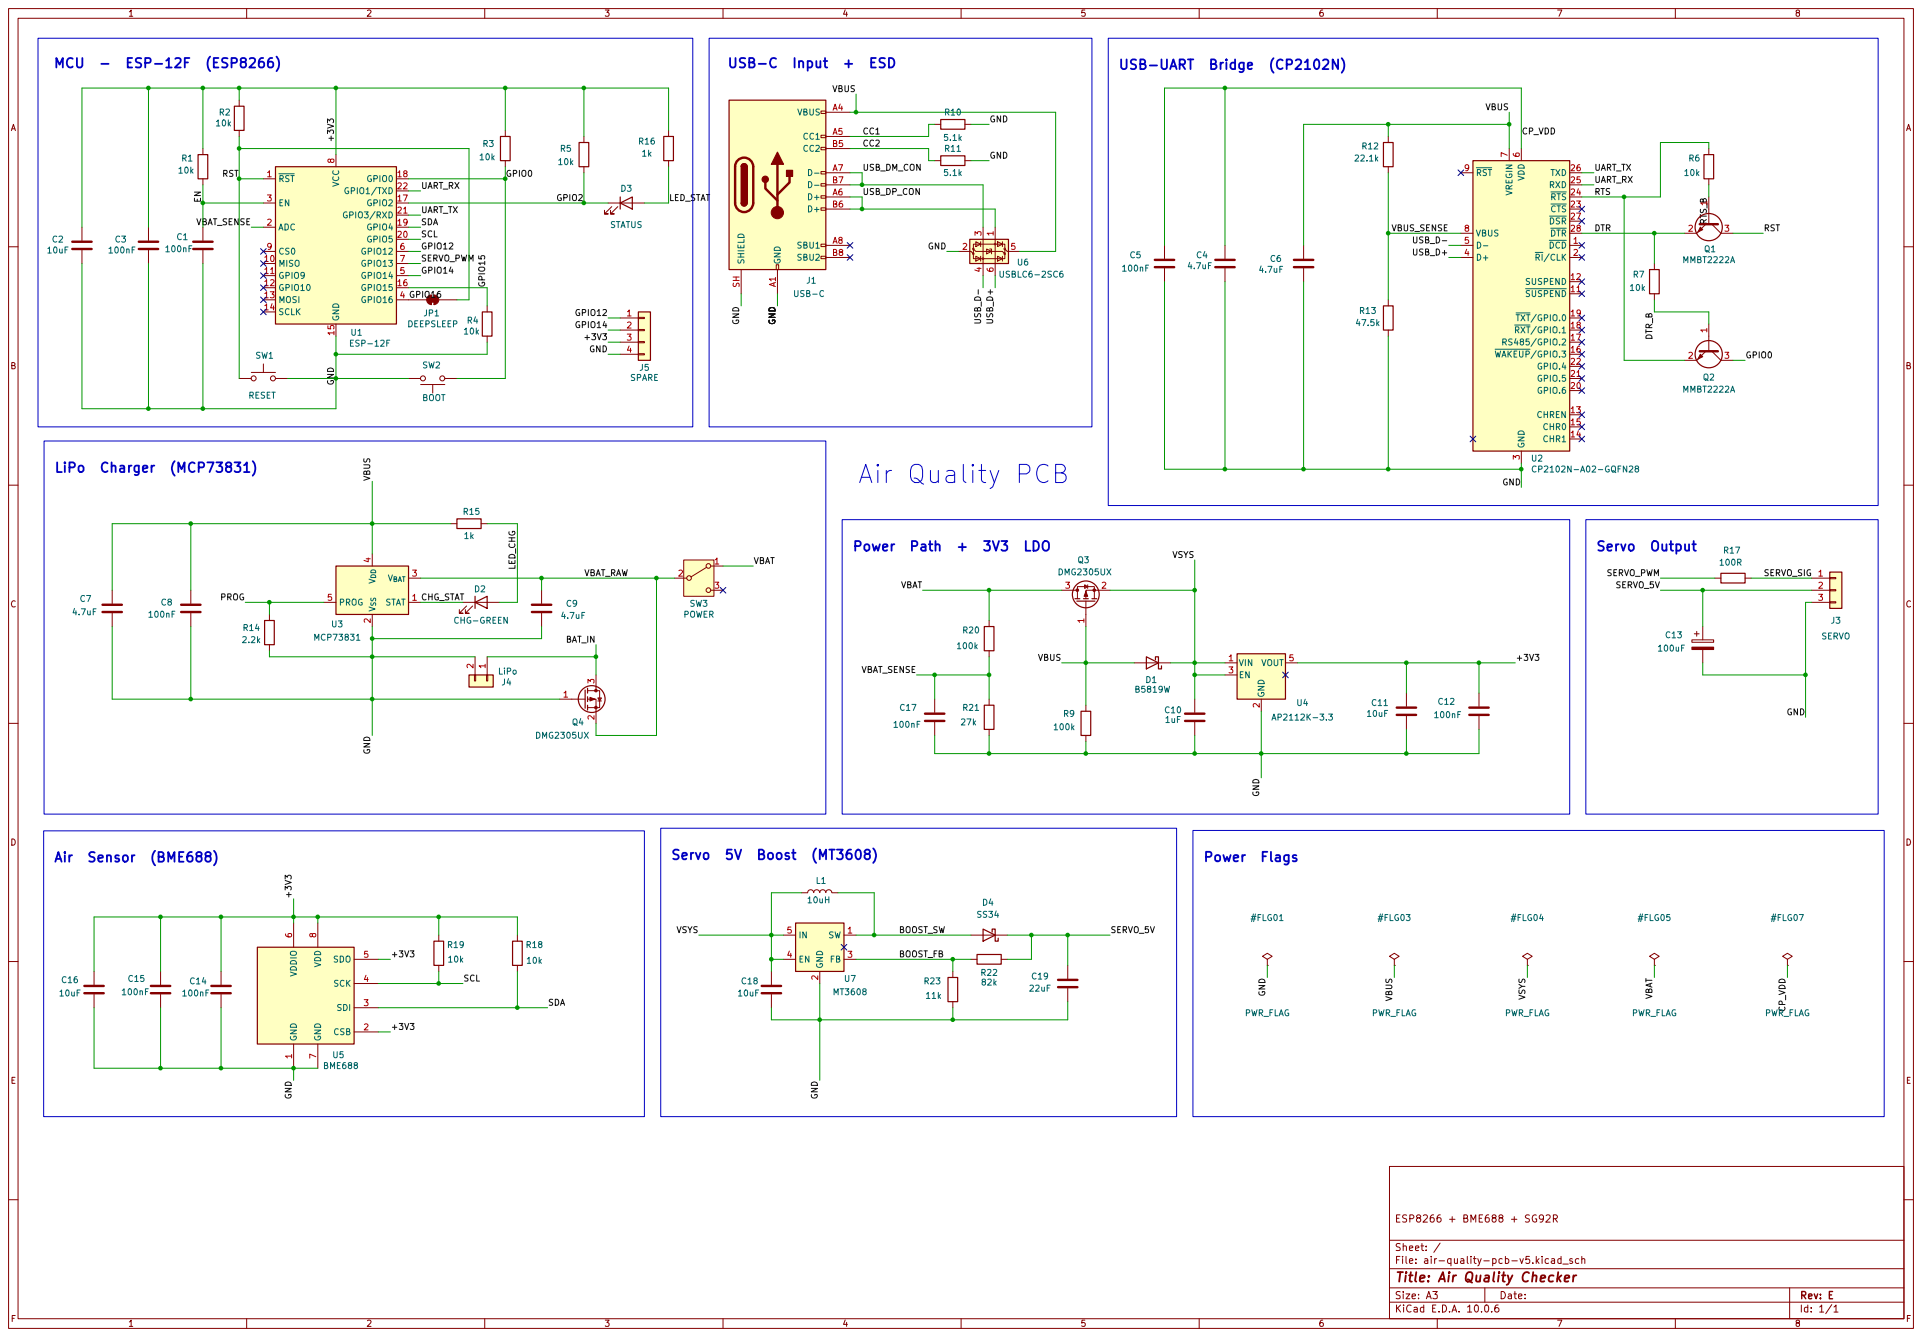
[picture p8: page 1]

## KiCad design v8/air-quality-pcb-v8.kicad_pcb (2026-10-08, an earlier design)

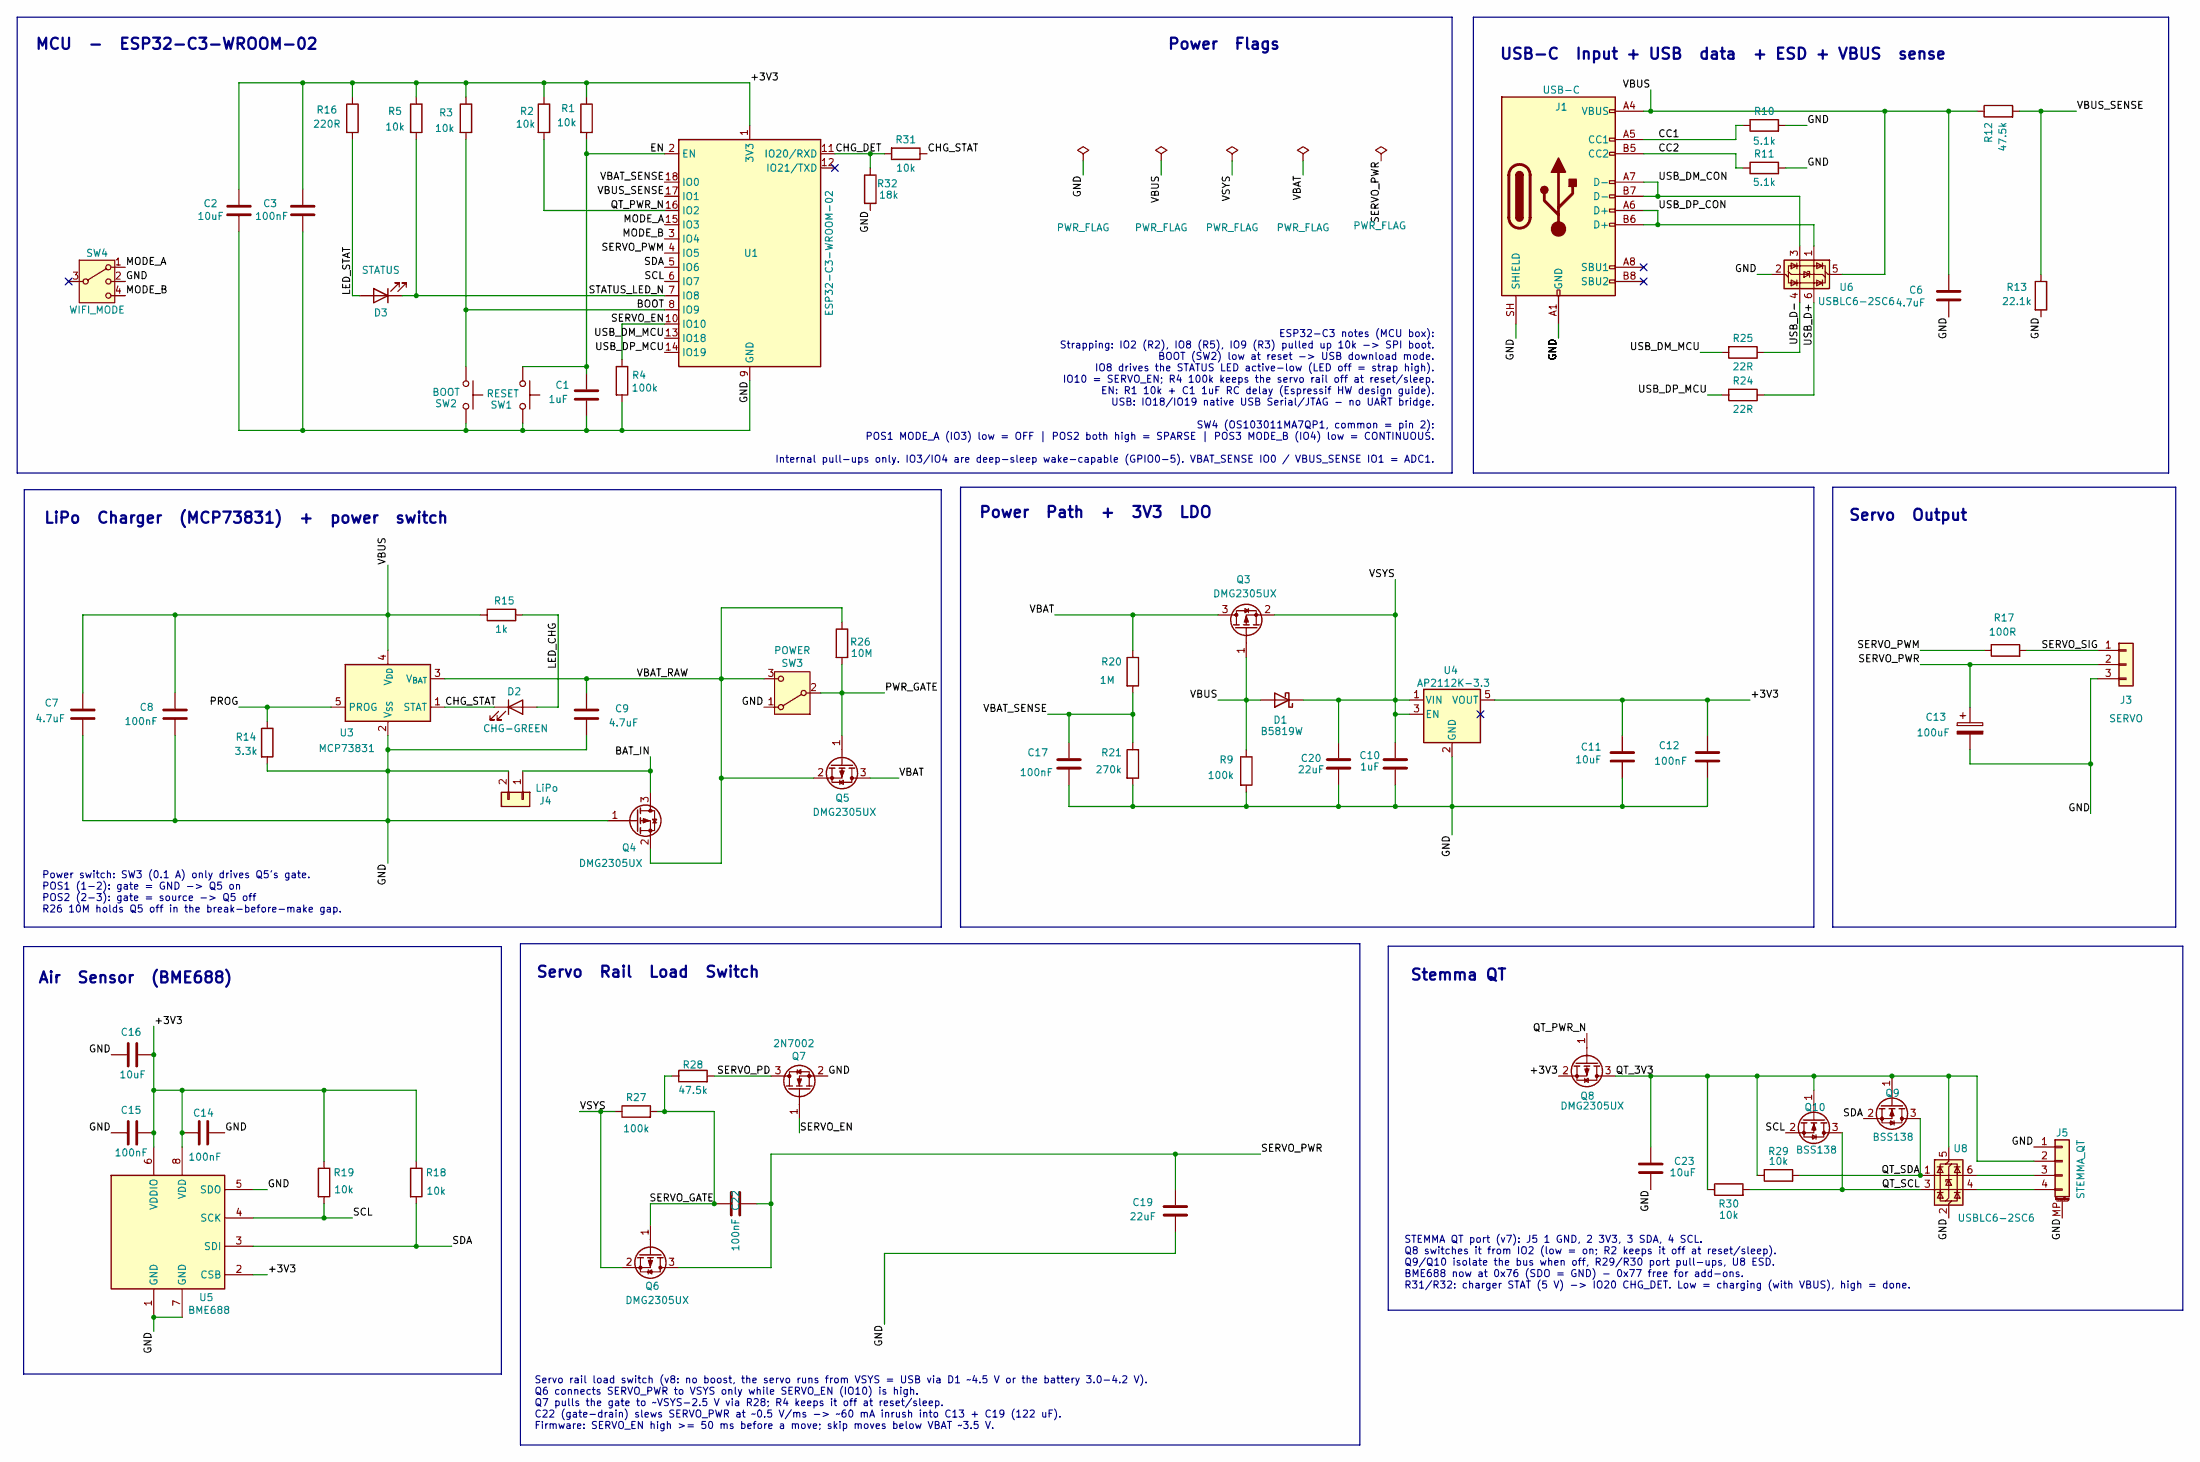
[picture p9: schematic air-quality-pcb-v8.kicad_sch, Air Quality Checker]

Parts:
C1, C10: 1uF; C_0805_2012Metric; MPN CL21B105KOFNNWE
C2, C11, C16, C23: 10uF; C_0805_2012Metric; MPN CC0805KRX5R7BB106
C3, C8, C12, C14, C15, C17, C22: 100nF; C_0805_2012Metric; MPN CL21B104KBCNNNC
C6, C7, C9: 4.7uF; C_0805_2012Metric; MPN CL21A475KOFNNNG
C13: 100uF; CP_Elec_6.3x5.4; MPN UCD1C101MCL1GS
C19, C20: 22uF; C_0805_2012Metric; MPN CL21A226KOQNNNG
D1: B5819W; D_SOD-123; MPN B5819W-TP
D2: CHG-GREEN; LED_Kingbright_KPA-3010_3x2x1mm; MPN KPA-3010SGC
D3: STATUS; LED_Kingbright_KPA-3010_3x2x1mm; MPN KPA-3010QBC-D
J1: USB-C; USB_C_Receptacle_HRO_TYPE-C-31-M-12; MPN TYPE-C-31-M-12
J3: SERVO; PinHeader_1x03_P2.54mm_Vertical; MPN 61300311121
J4: LiPo; JST_PH_B2B-PH-K_1x02_P2.00mm_Vertical; MPN B2B-PH-K-S
J5: STEMMA_QT; JST_SH_SM04B-SRSS-TB_1x04-1MP_P1.00mm_Horizontal; MPN SM04B-SRSS-TB(LF)(SN)
Q3, Q4, Q5, Q6, Q8: DMG2305UX; SOT-23; MPN DMG2305UX-7
Q7: 2N7002; SOT-23; MPN 2N7002-7-F
Q9, Q10: BSS138; SOT-23; MPN BSS138
R1, R2, R3, R5, R18, R19, R29, R30, R31: 10k; R_0805_2012Metric; MPN RC0805FR-0710KL
R4, R9, R27: 100k; R_0805_2012Metric; MPN RC0805FR-07100KL
R10, R11: 5.1k; R_0805_2012Metric; MPN RC0805FR-075K1L
R12, R28: 47.5k; R_0805_2012Metric; MPN RC0805FR-0747K5L
R13: 22.1k; R_0805_2012Metric; MPN RC0805FR-0722K1L
R14: 3.3k; R_0805_2012Metric; MPN RC0805FR-073K3L
R15: 1k; R_0805_2012Metric; MPN RC0805FR-071KL
R16: 220R; R_0805_2012Metric; MPN RC0805FR-07220RL
R17: 100R; R_0805_2012Metric; MPN RC0805FR-07100RL
R20: 1M; R_0805_2012Metric; MPN RC0805FR-071ML
R21: 270k; R_0805_2012Metric; MPN RC0805FR-07270KL
R24, R25: 22R; R_0805_2012Metric; MPN RC0805FR-0722RL
R26: 10M; R_0805_2012Metric; MPN RC0805FR-0710ML
R32: 18k; R_0805_2012Metric; MPN RC0805FR-0718KL
SW1: RESET; SW_Push_1P1T_NO_CK_KMR2; MPN KMR221G LFS
SW2: BOOT; SW_Push_1P1T_NO_CK_KMR2; MPN KMR221G LFS
SW3: POWER; SW_Slide_SPDT_Angled_CK_OS102011MA1Q; MPN OS102011MA1QN1
SW4: WIFI_MODE; OS103011MA7QP1; MPN OS103011MA7QP1
U1: ESP32-C3-WROOM-02; MPN ESP32-C3-WROOM-02-N4
U3: MCP73831; SOT-23-5; MPN MCP73831T-2ACI/OT
U4: AP2112K-3.3; SOT-23-5; MPN AP2112K-3.3TRG1
U5: BME688; Bosch_LGA-8_3x3mm_P0.8mm_ClockwisePinNumbering; MPN BME688
U6, U8: USBLC6-2SC6; SOT-23-6; MPN USBLC6-2SC6

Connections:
/+3V3: C2.1, C3.1, C11.1, C12.1, C14.1, C15.1, C16.1, Q8.2 (S), R1.1, R2.1, R3.1, R5.1, R16.1, R18.1, R19.1, U1.1 (3V3), U4.5 (VOUT), U5.2 (CSB), U5.6 (VDDIO), U5.8 (VDD)
/BAT_IN: J4.1, Q4.3 (D)
/BOOT: R3.2, SW2.1, U1.8 (IO9)
/CC1: J1.A5 (CC1), R10.1
/CC2: J1.B5 (CC2), R11.1
/CHG_DET: R31.2, R32.1, U1.11 (IO20/RXD)
/CHG_STAT: D2.1 (K), R31.1, U3.1 (STAT)
/EN: C1.1, R1.2, SW1.1, U1.2 (EN)
/GND: C1.2, C2.2, C3.2, C6.2, C7.2, C8.2, C9.2, C10.2, C11.2, C12.2, C13.2, C14.2, C15.2, C16.2, C17.2, C19.2, C20.2, C23.2, J1.A1 (GND), J1.A12 (GND), J1.B1 (GND), J1.B12 (GND), J1.SH (SHIELD), J3.3, J4.2, J5.1, J5.MP (MountPin), Q4.1 (G), Q7.2 (S), R4.2, R9.2, R10.2, R11.2, R13.2, R14.2, R21.2, R32.2, SW1.2, SW2.2, SW3.1 (A), SW4.2, U1.9 (GND), U1.19 (GND), U3.2 (V_{SS}), U4.2 (GND), U5.1 (GND), U5.5 (SDO), U5.7 (GND), U6.2 (GND), U8.2 (GND)
/LED_CHG: D2.2 (A), R15.2
/LED_STAT: D3.2 (A), R16.2
/MODE_A: SW4.1, U1.15 (IO3)
/MODE_B: SW4.4, U1.3 (IO4)
/PROG: R14.1, U3.5 (PROG)
/PWR_GATE: Q5.1 (G), R26.2, SW3.2 (B)
/QT_3V3: C23.1, J5.2, Q8.3 (D), Q9.1 (G), Q10.1 (G), R29.1, R30.1, U8.5 (VBUS)
/QT_PWR_N: Q8.1 (G), R2.2, U1.16 (IO2)
/QT_SCL: Q10.3 (D), R30.2, U8.3 (I/O2)
/QT_SDA: Q9.3 (D), R29.2, U8.1 (I/O1)
/SCL: Q10.2 (S), R19.2, U1.6 (IO7), U5.4 (SCK)
/SDA: Q9.2 (S), R18.2, U1.5 (IO6), U5.3 (SDI)
/SERVO_EN: Q7.1 (G), R4.1, U1.10 (IO10)
/SERVO_GATE: C22.2, Q6.1 (G), R27.2, R28.1
/SERVO_PD: Q7.3 (D), R28.2
/SERVO_PWM: R17.1, U1.4 (IO5)
/SERVO_PWR: C13.1, C19.1, C22.1, J3.2, Q6.3 (D)
/SERVO_SIG: J3.1, R17.2
/STATUS_LED_N: D3.1 (K), R5.2, U1.7 (IO8)
/USB_D+: R24.1, U6.6 (I/O1)
/USB_D-: R25.1, U6.4 (I/O2)
/USB_DM_CON: J1.A7 (D-), J1.B7 (D-), U6.3 (I/O2)
/USB_DM_MCU: R25.2, U1.13 (IO18)
/USB_DP_CON: J1.A6 (D+), J1.B6 (D+), U6.1 (I/O1)
/USB_DP_MCU: R24.2, U1.14 (IO19)
/VBAT: Q3.3 (D), Q5.3 (D), R20.1
/VBAT_RAW: C9.1, Q4.2 (S), Q5.2 (S), R26.1, SW3.3 (C), U3.3 (V_{BAT})
/VBAT_SENSE: C17.1, R20.2, R21.1, U1.18 (IO0)
/VBUS: C6.1, C7.1, C8.1, D1.2 (A), J1.A4 (VBUS), J1.A9 (VBUS), J1.B4 (VBUS), J1.B9 (VBUS), Q3.1 (G), R9.1, R12.1, R15.1, U3.4 (V_{DD}), U6.5 (VBUS)
/VBUS_SENSE: R12.2, R13.1, U1.17 (IO1)
/VSYS: C10.1, C20.1, D1.1 (K), Q3.2 (S), Q6.2 (S), R27.1, U4.1 (VIN), U4.3 (EN)
unnamed: J5.3, U8.6 (I/O1)
unnamed: J5.4, U8.4 (I/O2)

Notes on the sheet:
MCU - ESP32-C3-WROOM-02
Servo rail load switch (v8: no boost, the servo runs from VSYS = USB via D1 ~4.5 V or the battery 3.0-4.2 V). Q6 connects SERVO_PWR to VSYS only while SERVO_EN (IO10) is high. Q7 pulls the gate to ~VSYS-2.5 V via R28; R4 keeps it off at reset/sleep. C22 (gate-drain) slews SERVO_PWR at ~0.5 V/ms -> 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
STEMMA QT port (v7): J5 1 GND, 2 3V3, 3 SDA, 4 SCL. Q8 switches it from IO2 (low = on; R2 keeps it off at reset/sleep). Q9/Q10 isolate the bus when off, R29/R30 port pull-ups, U8 ESD. BME688 now at 0x76 (SDO = GND) - 0x77 free for add-ons. R31/R32: charger STAT (5 V) -> IO20 CHG_DET. Low = charging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
Power Path + 3V3 LDO
Power switch: SW3 (0.1 A) only drives Q5's gate. POS1 (1-2): gate = GND -> Q5 on POS2 (2-3): gate = source -> Q5 off R26 10M holds Q5 off in the break-before-make gap.
ESP32-C3 notes (MCU box): Strapping: IO2 (R2), IO8 (R5), IO9 (R3) pulled up 10k -> SPI boot. BOOT (SW2) low at reset -> USB download mode. IO8 drives the STATUS LED active-low (LED off = strap high). IO10 = SERVO_EN; R4 100k keeps the servo rail off at reset/sleep. EN: R1 10k + C1 1uF RC delay (Esp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
Air Sensor (BME688)
Power Flags
Stemma QT
USB-C Input + USB data + ESD + VBUS sense
LiPo Charger (MCP73831) + power switch
Servo Rail Load Switch
Servo Output

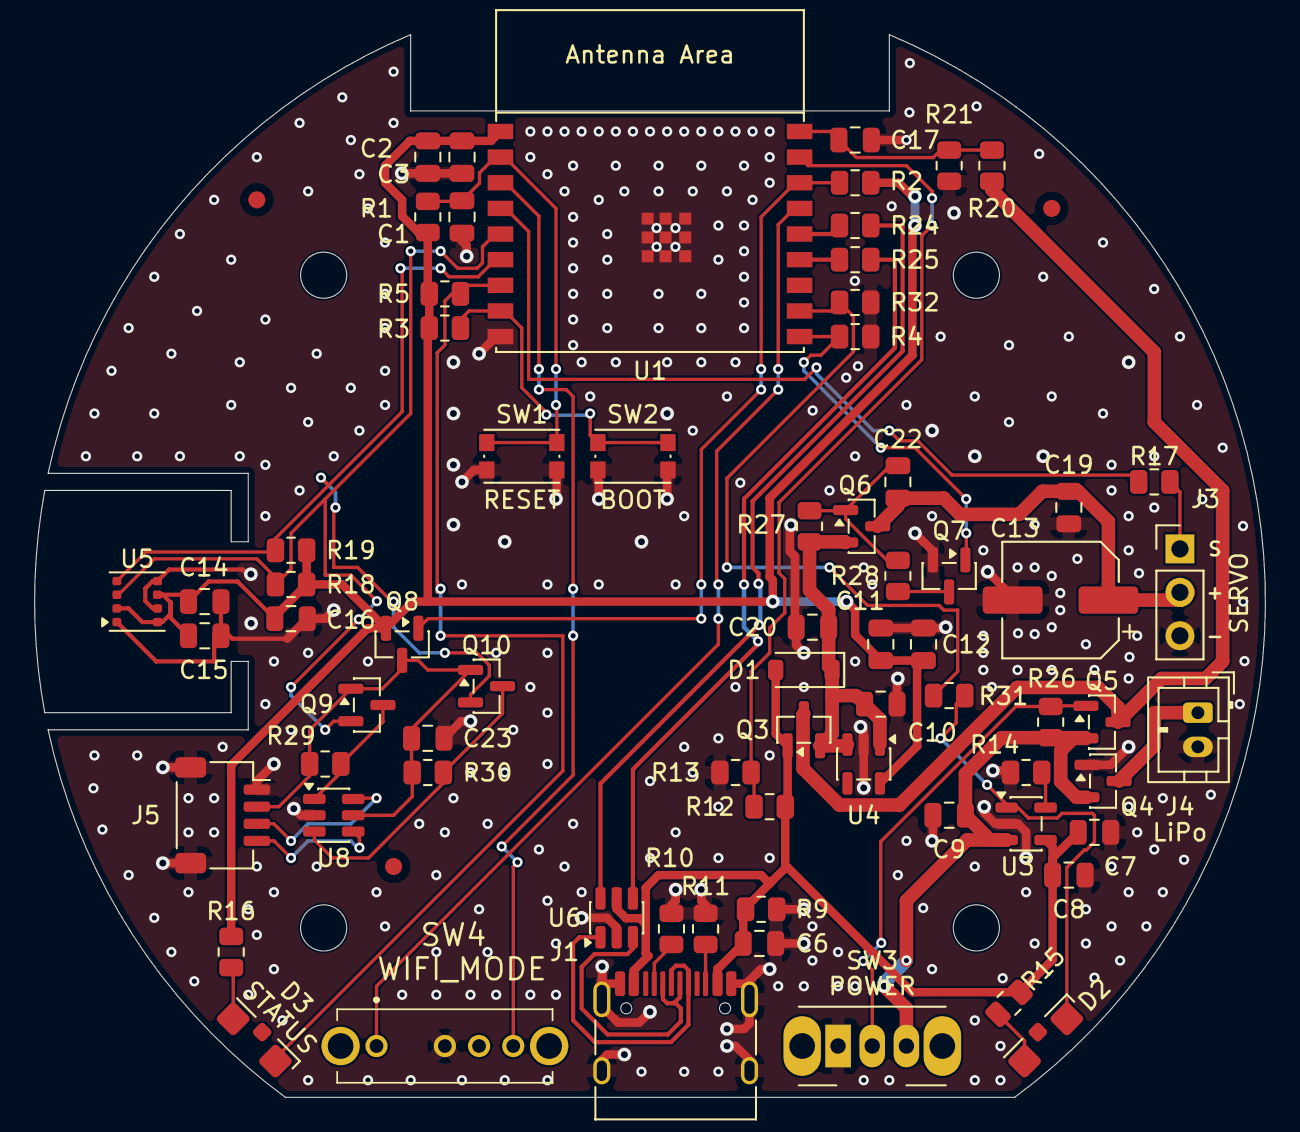
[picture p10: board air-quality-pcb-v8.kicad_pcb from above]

Board: 2 copper layers, 72.0 x 62.2 mm, 78 parts (0 on the bottom side), 42 nets.

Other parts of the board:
FID1, FID2, FID3: Fiducial; Fiducial_1mm_Mask2mm
H1, H2, H3, H4: M2.5; MountingHole_2.7mm_M2.5

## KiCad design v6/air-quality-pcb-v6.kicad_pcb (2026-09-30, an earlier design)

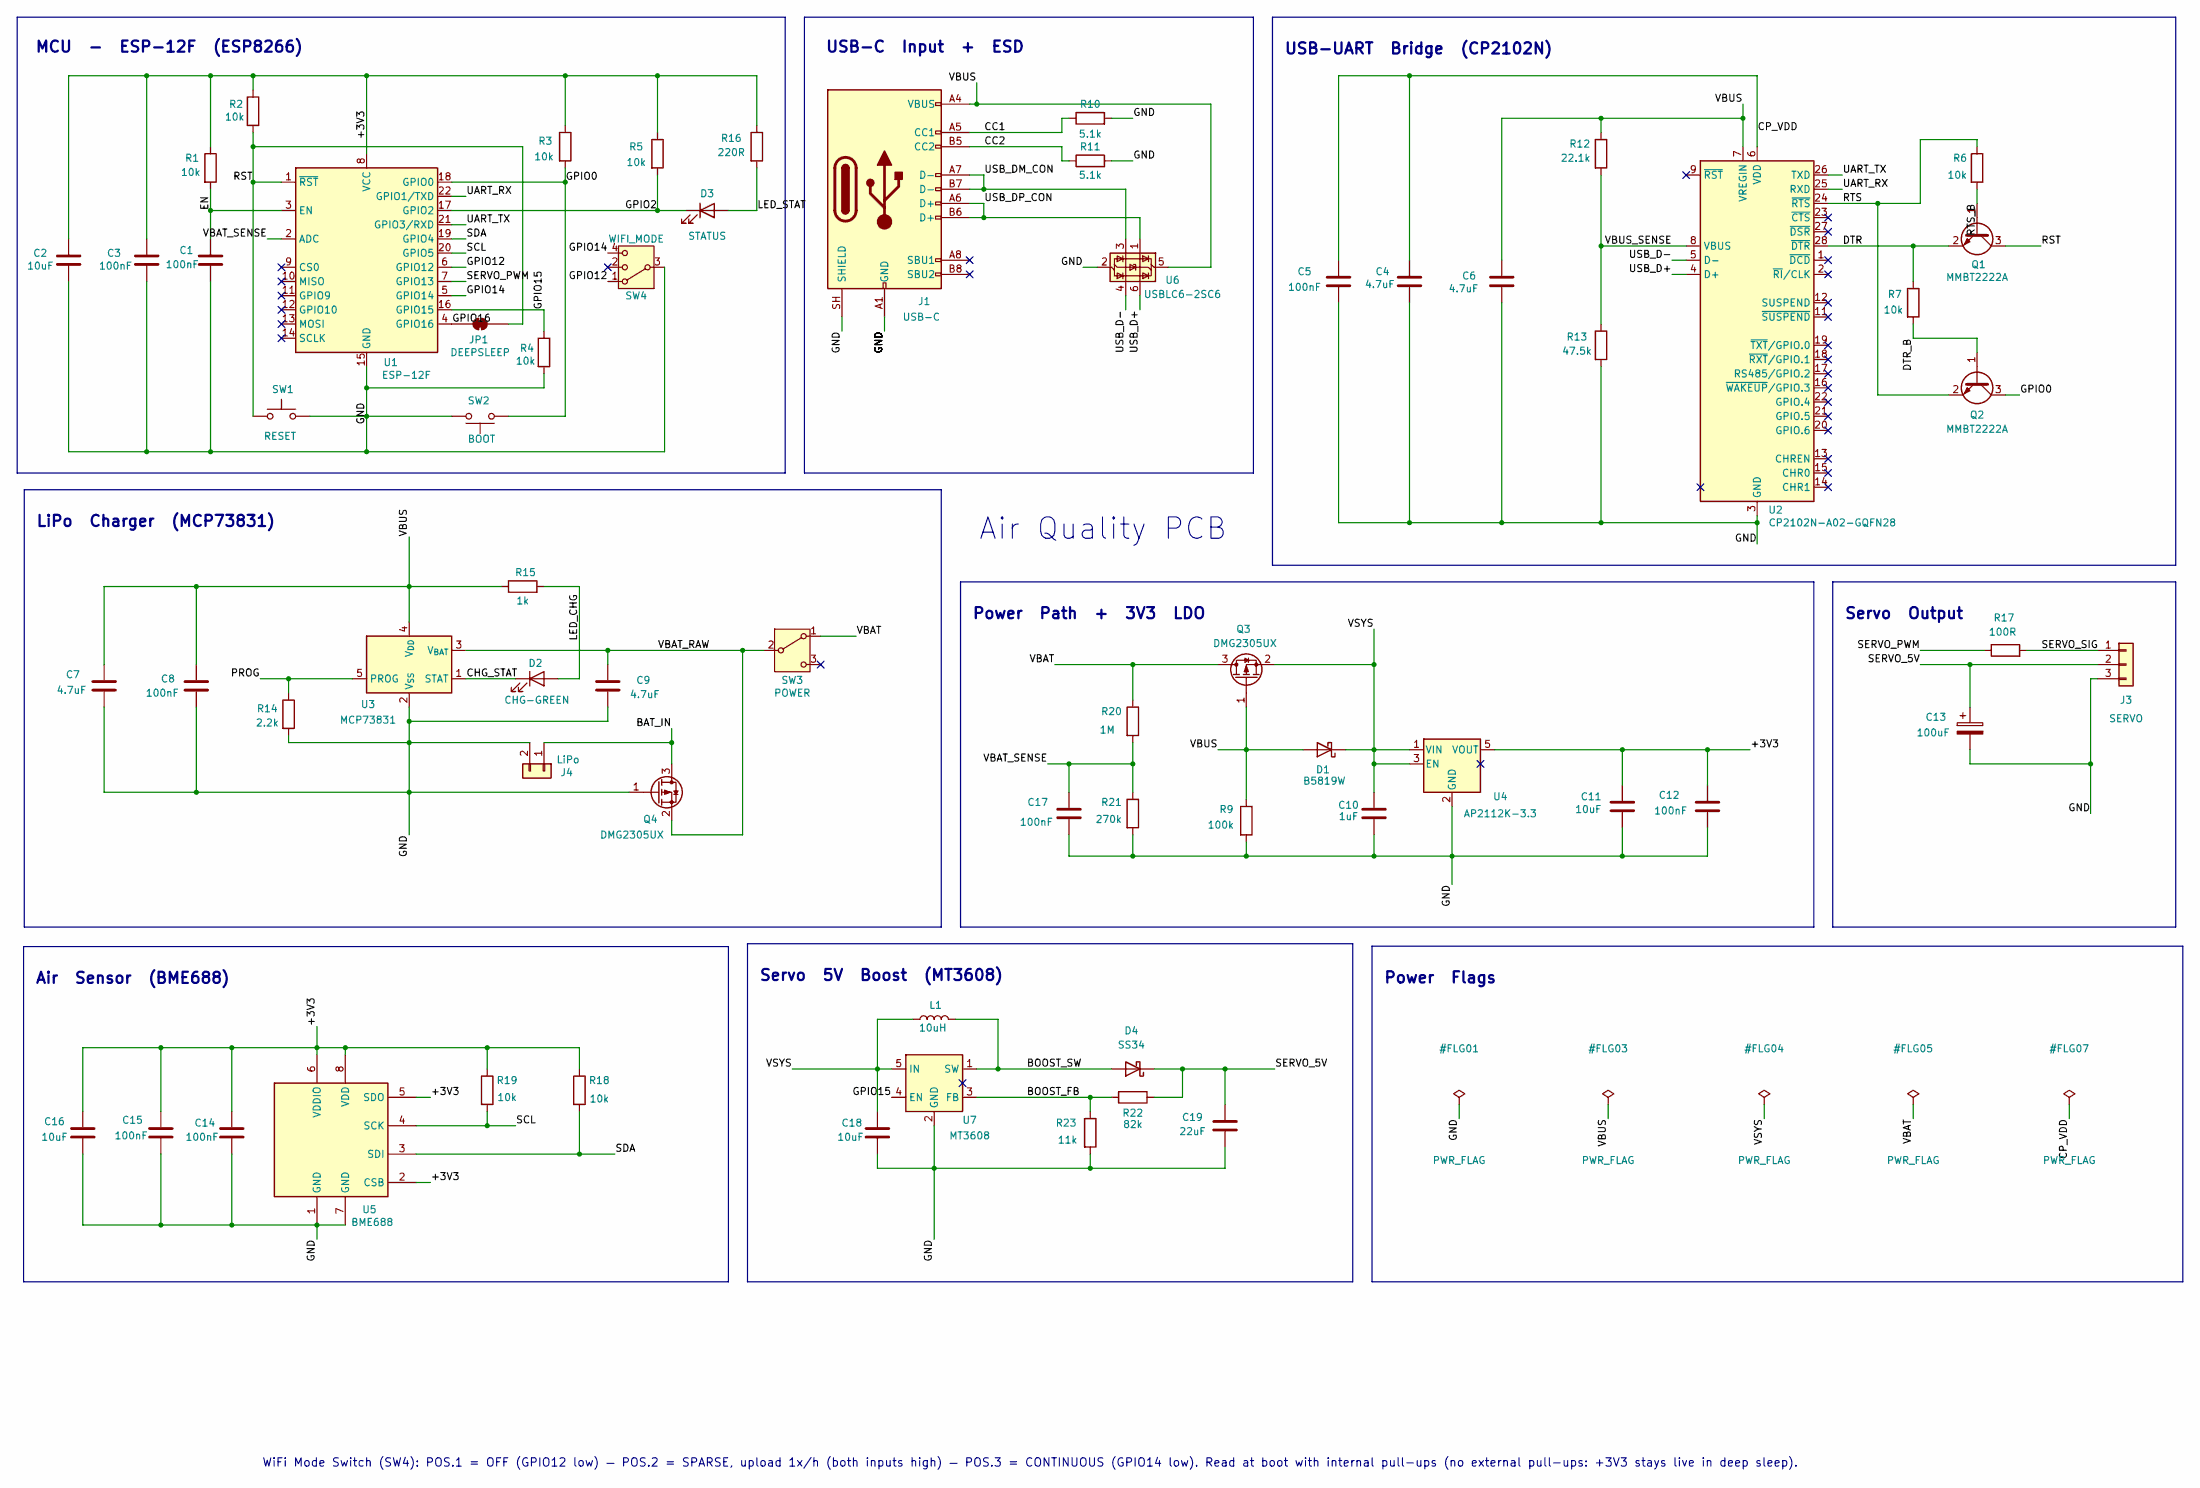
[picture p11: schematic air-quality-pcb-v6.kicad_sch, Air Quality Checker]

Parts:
C1, C3, C5, C8, C12, C14, C15, C17: 100nF; C_0805_2012Metric; MPN CL21B104KBCNNNC
C2, C11, C16, C18: 10uF; C_0805_2012Metric; MPN CC0805KRX5R7BB106
C4, C6, C7, C9: 4.7uF; C_0805_2012Metric; MPN CL21A475KOFNNNG
C10: 1uF; C_0805_2012Metric; MPN CL21B105KOFNNWE
C13: 100uF; CP_Elec_6.3x5.4; MPN UCD1C101MCL1GS
C19: 22uF; C_0805_2012Metric; MPN CL21A226KOQNNNG
D1: B5819W; D_SOD-123; MPN B5819W-TP
D2: CHG-GREEN; LED_0805_2012Metric; MPN LTST-C170GKT
D3: STATUS; LED_Kingbright_KPA-3010_3x2x1mm; MPN KPA-3010QBC-D
D4: SS34; D_SMA; MPN SS34-HF
J1: USB-C; USB_C_Receptacle_HRO_TYPE-C-31-M-12; MPN TYPE-C-31-M-12
J3: SERVO; PinHeader_1x03_P2.54mm_Vertical; MPN 61300311121
J4: LiPo; JST_PH_B2B-PH-K_1x02_P2.00mm_Vertical; MPN B2B-PH-K-S
JP1: DEEPSLEEP; SolderJumper-2_P1.3mm_Bridged_Pad1.0x1.5mm
L1: 10uH; L_Sunlord_SWPA4030S; MPN SWPA4030S100MT
Q1, Q2: MMBT2222A; SOT-23; MPN MMBT2222ALT1G
Q3, Q4: DMG2305UX; SOT-23; MPN DMG2305UX-7
R1, R2, R3, R4, R5, R6, R7, R18, R19: 10k; R_0805_2012Metric; MPN RC0805FR-0710KL
R9: 100k; R_0805_2012Metric; MPN RC0805FR-07100KL
R10, R11: 5.1k; R_0805_2012Metric; MPN RC0805FR-075K1L
R12: 22.1k; R_0805_2012Metric; MPN RC0805FR-0722K1L
R13: 47.5k; R_0805_2012Metric; MPN RC0805FR-0747K5L
R14: 2.2k; R_0805_2012Metric; MPN RC0805FR-072K2L
R15: 1k; R_0805_2012Metric; MPN RC0805FR-071KL
R16: 220R; R_0805_2012Metric; MPN RC0805FR-07220RL
R17: 100R; R_0805_2012Metric; MPN RC0805FR-07100RL
R20: 1M; R_0805_2012Metric; MPN RC0805FR-071ML
R21: 270k; R_0805_2012Metric; MPN RC0805FR-07270KL
R22: 82k; R_0805_2012Metric; MPN RC0805FR-0782KL
R23: 11k; R_0805_2012Metric; MPN RC0805FR-0711KL
SW1: RESET; SW_Push_1P1T_NO_CK_KMR2; MPN KMR221G LFS
SW2: BOOT; SW_Push_1P1T_NO_CK_KMR2; MPN KMR221G LFS
SW3: POWER; SW_SPDT_PCM12; MPN PCM12SMTBR
SW4: WIFI_MODE; SW_SP3T_PCM13; MPN PCM13SMTR
U1: ESP-12F; ESP-12E; MPN ESP-12F
U2: CP2102N-A02-GQFN28; QFN-28-1EP_5x5mm_P0.5mm_EP3.35x3.35mm; MPN CP2102N-A02-GQFN28
U3: MCP73831; SOT-23-5; MPN MCP73831T-2ACI/OT
U4: AP2112K-3.3; SOT-23-5; MPN AP2112K-3.3TRG1
U5: BME688; Bosch_LGA-8_3x3mm_P0.8mm_ClockwisePinNumbering; MPN BME688
U6: USBLC6-2SC6; SOT-23-6; MPN USBLC6-2SC6
U7: MT3608; SOT-23-6; MPN MT3608

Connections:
/+3V3: C2.1, C3.1, C11.1, C12.1, C14.1, C15.1, C16.1, R1.1, R2.1, R3.1, R5.1, R16.1, R18.1, R19.1, U1.8 (VCC), U4.5 (VOUT), U5.2 (CSB), U5.5 (SDO), U5.6 (VDDIO), U5.8 (VDD)
/BAT_IN: J4.1, Q4.3 (D)
/BOOST_FB: R22.2, R23.1, U7.3 (FB)
/BOOST_SW: D4.2 (A), L1.2, U7.1 (SW)
/CC1: J1.A5 (CC1), R10.1
/CC2: J1.B5 (CC2), R11.1
/CHG_STAT: D2.1 (K), U3.1 (STAT)
/CP_VDD: C4.1, C5.1, U2.6 (VDD)
/DTR: Q1.2 (E), R7.1, U2.28 (~DTR)
/DTR_B: Q2.1 (B), R7.2
/EN: C1.1, R1.2, U1.3 (EN)
/GND: C1.2, C2.2, C3.2, C4.2, C5.2, C6.2, C7.2, C8.2, C9.2, C10.2, C11.2, C12.2, C13.2, C14.2, C15.2, C16.2, C17.2, C18.2, C19.2, J1.A1 (GND), J1.A12 (GND), J1.B1 (GND), J1.B12 (GND), J1.SH (SHIELD), J3.3, J4.2, Q4.1 (G), R4.2, R9.2, R10.2, R11.2, R13.2, R14.2, R21.2, R23.2, SW1.2, SW2.2, SW4.3, U1.15 (GND), U2.3 (GND), U2.29 (GND), U3.2 (V_{SS}), U4.2 (GND), U5.1 (GND), U5.7 (GND), U6.2 (GND), U7.2 (GND)
/GPIO0: Q2.3 (C), R3.2, SW2.1, U1.18 (GPIO0)
/GPIO2: D3.1 (K), R5.2, U1.17 (GPIO2)
/GPIO12: SW4.1, U1.6 (GPIO12)
/GPIO14: SW4.4, U1.5 (GPIO14)
/GPIO15: R4.1, U1.16 (GPIO15), U7.4 (EN)
/GPIO16: JP1.1 (A), U1.4 (GPIO16)
/LED_CHG: D2.2 (A), R15.2
/LED_STAT: D3.2 (A), R16.2
/PROG: R14.1, U3.5 (PROG)
/RST: JP1.2 (B), Q1.3 (C), R2.2, SW1.1, U1.1 (~RST)
/RTS: Q2.2 (E), R6.1, U2.24 (~RTS)
/RTS_B: Q1.1 (B), R6.2
/SCL: R19.2, U1.20 (GPIO5), U5.4 (SCK)
/SDA: R18.2, U1.19 (GPIO4), U5.3 (SDI)
/SERVO_5V: C13.1, C19.1, D4.1 (K), J3.2, R22.1
/SERVO_PWM: R17.1, U1.7 (GPIO13)
/SERVO_SIG: J3.1, R17.2
/UART_RX: U1.22 (GPIO1/TXD), U2.25 (RXD)
/UART_TX: U1.21 (GPIO3/RXD), U2.26 (TXD)
/USB_D+: U2.4 (D+), U6.6 (I/O1)
/USB_D-: U2.5 (D-), U6.4 (I/O2)
/USB_DM_CON: J1.A7 (D-), J1.B7 (D-), U6.3 (I/O2)
/USB_DP_CON: J1.A6 (D+), J1.B6 (D+), U6.1 (I/O1)
/VBAT: Q3.3 (D), R20.1, SW3.1 (A)
/VBAT_RAW: C9.1, Q4.2 (S), SW3.2 (B), U3.3 (V_{BAT})
/VBAT_SENSE: C17.1, R20.2, R21.1, U1.2 (ADC)
/VBUS: C6.1, C7.1, C8.1, D1.2 (A), J1.A4 (VBUS), J1.A9 (VBUS), J1.B4 (VBUS), J1.B9 (VBUS), Q3.1 (G), R9.1, R12.1, R15.1, U2.7 (VREGIN), U3.4 (V_{DD}), U6.5 (VBUS)
/VBUS_SENSE: R12.2, R13.1, U2.8 (VBUS)
/VSYS: C10.1, C18.1, D1.1 (K), L1.1, Q3.2 (S), U4.1 (VIN), U4.3 (EN), U7.5 (IN)

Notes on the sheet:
MCU - ESP-12F (ESP8266)
Power Path + 3V3 LDO
Air Quality PCB
Air Sensor (BME688)
WiFi Mode Switch (SW4): POS.1 = OFF (GPIO12 low) — POS.2 = SPARSE, upload 1x/h (both inputs high) — POS.3 = CONTINUOUS (GPIO14 low). Read at boot with internal pull-ups (no external pull-ups: +3V3 stays live in deep sleep).
Power Flags
USB-UART Bridge (CP2102N)
USB-C Input + ESD
LiPo Charger (MCP73831)
Servo 5V Boost (MT3608)
Servo Output

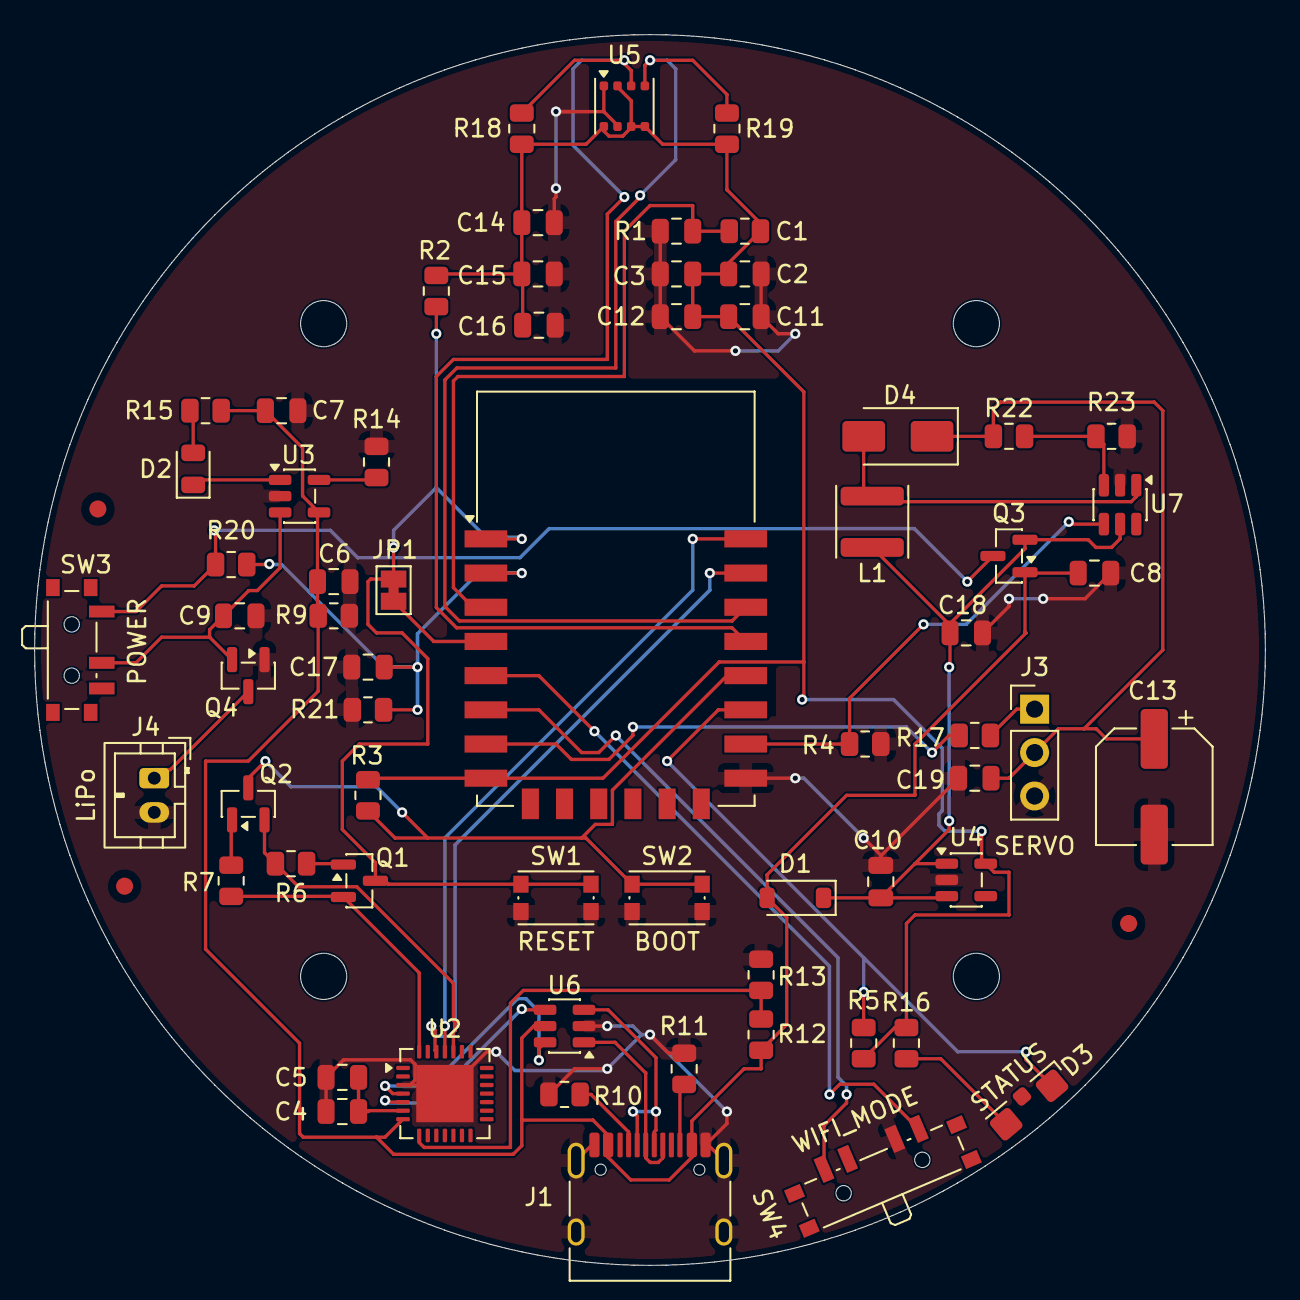
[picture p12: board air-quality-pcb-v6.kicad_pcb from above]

Board: 2 copper layers, 72.0 x 72.0 mm, 72 parts (0 on the bottom side), 41 nets.

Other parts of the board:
FID1, FID2, FID3: Fiducial; Fiducial_1mm_Mask2mm
H1, H2, H3, H4: M2.5; MountingHole_2.7mm_M2.5

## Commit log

2026-09-24 First version
    [air-quality-pcb.kicad_pcb, air-quality-pcb.kicad_sch, bom.csv]
2026-09-24 Add v2
    [air-quality-pcb-v2.kicad_pcb, air-quality-pcb-v2.kicad_sch, bom_v2.csv]
2026-09-24 Move v1 and add v4
    [air-quality-pcb-v4.kicad_pcb, air-quality-pcb-v4.kicad_sch, air-quality-pcb.kicad_pcb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]
2026-09-25 Add v5
    [air-quality-pcb-v5.kicad_pcb, air-quality-pcb-v5.kicad_sch, bom_v5.csv]
2026-09-25 Update v5
    [air-quality-pcb-v5.kicad_pcb]
2026-09-28 Update v5 add bom
    [air-quality-pcb-v5.kicad_pcb, air-quality-pcb-v5.kicad_sch, bom_kicad_raw.csv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]
2026-09-29 Update vias
    [air-quality-pcb-v5.kicad_pcb]
2026-09-30 Add v6
    [air-quality-pcb-v6.kicad_pcb, air-quality-pcb-v6.kicad_sch, bom_kicad_raw.csv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]
2026-10-01 Add v7
    [air-quality-pcb-v7.kicad_pcb, air-quality-pcb-v7.kicad_sch, bom_kicad_raw.csv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]
2026-10-08 Add v9
    [a-sample-of-PCBWay-BOM.xlsx, air-quality-pcb-v7.kicad_pcb, air-quality-pcb-v8.kicad_pcb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]
2026-10-08 Update documentation
    [bom_kicad_raw.csv, bom_pcbway_v9.csv, bom_v5.csv]
